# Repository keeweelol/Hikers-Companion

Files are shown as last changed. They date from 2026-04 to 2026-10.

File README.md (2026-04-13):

# Hiker’s Companion

## Overview
Hiker’s Companion is a portable hiking safety device designed for use in areas with little or no cellular coverage. It combines GPS tracking with LoRa communication to allow users to send location data and emergency SOS signals to nearby devices or gateways.

The goal is to provide a **low-cost (<$100), reliable, and energy-efficient** safety solution for recreational hikers.

---

## Features
- 📍 GPS location tracking (≈10 m accuracy)
- 🚨 SOS emergency signaling
- 📡 Long-range LoRa communication (no cellular needed)
- 🔋 24-hour battery life target
- 📱 Bluetooth setup via mobile device
- 🖥️ LCD status display
- 🧭 Real-time location updates for responders

---

## System Architecture

### Main Components
- **ESP32 Microcontroller**
  - Controls system logic and communication
- **GPS Module**
  - Provides real-time coordinates
- **LoRa Module (SX1262)**
  - Handles long-range wireless transmission
- **LCD Display**
  - Shows device status (sending, delivered, etc.)
- **Power System**
  - 3.7V battery → 3.3V regulated supply

---

## How It Works
1. User powers on the device  
2. GPS continuously collects location data  
3. System checks for button input  
4. When pressed:
   - SOS message + GPS data is transmitted via LoRa  
5. Gateway forwards message to emergency contacts  
6. Signal repeats for tracking movement  

---

## Design Constraints
- Cost: **< $100**
- Battery life: **≥ 24 hours**
- Range: **~1 km off-trail communication**
- Temperature: **-18°C to 38°C**
- Durability:
  - Drop resistant (1.5 m)
  - IP55 (dust + water resistant)

---

## Communication Choice
LoRa was selected over alternatives like NB-IoT, Satellite (Iridium), and Mioty due to:

- ✅ Low power consumption  
- ✅ Long range  
- ✅ Low cost  
- ❌ Requires mesh/gateway infrastructure  

---

## Power Analysis
- Estimated average current: **~46.93 mA**
- Daily consumption: **~1.126 Ah**
- Battery capacity: **3 Ah**

➡️ Device can comfortably last **24+ hours** on a single charge.

---

## Current Progress
- ✅ System design finalized  
- ✅ Component selection complete (ESP32-based boards)  
- ✅ Communication method chosen (LoRa)  
- ✅ Initial power calculations completed  

---

## Next Steps
- 🔧 Prototype development (Spring 2026)
- 🔌 Hardware integration and testing
- 🔋 Real-world power validation
- 🧱 Final enclosure design
- 🚀 Full system validation (Fall 2026)

---

## Team
- Ky’Juan Branch  
- Zavier Lowe  
- Kenneth Patrick  
- Taylor Snow  

North Carolina A&T State University  
ECEN 478 – Senior Design Project I  

---

## Summary
Hiker’s Companion aims to improve safety in remote hiking environments by providing a reliable, low-cost emergency communication system that works where traditional networks fail.

---

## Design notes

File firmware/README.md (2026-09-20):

# Hiker's Companion Firmware

Custom PlatformIO/Arduino firmware for the LILYGO T-Beam Supreme
(ESP32-S3 + SX1262 LoRa + AXP2101 PMU + GNSS).

This is separate from `../Lora Source/`, which is LilyGO's own vendored
example repo — kept only as pinout/API reference, not built directly.

Also separate: `../heltec-rx-test/`, a throwaway RX bench rig on a Heltec
WiFi LoRa 32 V3 used to confirm this board's LoRa TX is actually reaching a
second radio — decrypted payload + RSSI/SNR go to both serial and the
Heltec's onboard SSD1306 OLED, which wakes for 5s on each received signal
and sleeps otherwise. It also replies with an `ACK,<id>` for every valid
packet it decrypts, which is what makes the T-Beam's "Delivered" status
real (see FW-06 below). Not part of the product firmware.

## Test hardware on hand

2x LILYGO T-Beam Supreme, 2x Heltec WiFi LoRa 32 V3. Enough to test beyond a
single sender/receiver pair once we get there — e.g. two T-Beam senders into
one gateway, or a relay hop — not just the current one-to-one link test.

## Status: Milestone 1 — GPS + LoRa send loop, with SOS button and status display

Reads GPS fixes and transmits location over LoRa on a timer. The onboard
BOOT button (GPIO0) toggles a standing SOS beacon: pressing it sends an
immediate "SOS"-flagged packet and switches every subsequent periodic send
to "SOS" too (instead of the routine "OK") until pressed again to cancel —
see `sendLocationPacket()` / `buttonPressed()` in `src/main.cpp`.

An SH1106 OLED (I2C, pins 17/18) shows live status via `showStatus()`:
message type on top, "Sending" / "Delivered" / "No ACK" / "Send failed"
below. "Delivered" is now a real ACK, not an assumption: each packet carries
a small message id (`<type>,<id>,<location>`), and after transmitting, the
T-Beam listens for a matching `ACK,<id>` for up to the ACK's own airtime at
the current spreading factor plus `ACK_TURNAROUND_MARGIN_MS` (computed in
`waitForAck()`, so the window grows automatically from SF7 to SF12)
reply from the Heltec RX rig (`waitForAck()`/`sendAck()`). A timeout with no
reply shows "No ACK" — distinct from "Send failed," which means the radio
call itself errored, not that nobody answered.

The panel stays off between transmissions to save power — it wakes for a
send and holds for `DISPLAY_HOLD_MS` (5s) after the result, then sleeps
again (`displayWake()`/`displaySleep()`).

## Power

Between sends, the LoRa and GPS PMU rails (ALDO3/ALDO4) are cut and the
ESP32 goes into light sleep, instead of both rails and the CPU staying fully
awake for the whole `SEND_INTERVAL_MS` interval — this duty cycle is what
the report's 46.93 mA average current draw is based on. Each cycle in
`loop()`:

1. Check for a pending SOS press (`buttonPressed()`/`handleButtonPress()`).
2. Power the GPS/LoRa rails back on and acquire a fix (`acquireGpsFix()`,
   bounded by `GPS_ACQUIRE_BUDGET_MS` for a routine poll or the much shorter
   `GPS_ACQUIRE_QUICK_MS` for an SOS press — a fresh fix isn't worth making
   an emergency send wait).
3. Send (`sendLocationPacket()`).
4. Gate the rails back off (`gpsRailDown()`/`radioRailDown()`) and light-sleep
   for whatever's left of the ~60s interval (`lightSleepMs()`).

The SX1262 and the GPS module both lose all internal state when their rail
is cut, so `gpsRailUp()`/`radioRailUp()` do a full re-init (`initGPS()`/
`initRadio()`), not just a PMU output toggle. The sleep also arms a GPIO
wakeup on the SOS button (level-triggered, since ESP32-S3 light sleep GPIO
wakeup only supports level triggers) so a press doesn't have to wait out the
rest of a ~60s sleep.

## BLE provisioning (FW-10)

Two ways in:

- **At power-on**: holding BOOT through boot (2s, `PROVISION_HOLD_MS`) skips
  the normal GPS/LoRa loop entirely and boots straight into a standalone
  provisioning mode (`bootButtonHeldForProvisioning()` in `main.cpp`).
- **On the fly, during normal operation**: short-pressing the board's
  physical PWR button (`checkBluetoothButton()`/`bluetoothButtonPressed()`
  in `main.cpp`) drops straight into provisioning mid-loop, without a
  reboot. PWR isn't a GPIO on this board — it's wired into the AXP2101 PMU
  as its "power key," reported via `PMU_IRQ_PIN` going low — so it's a
  physically separate button from BOOT/`BUTTON_PIN` (SOS) on purpose: a
  contact-editing press can never be mistaken for, or interfere with, the
  emergency button. **Ignored outright whenever the SOS beacon is active**
  (`sosActive`) rather than queued — entering provisioning can block the
  loop for minutes, and an active SOS beacon has to keep beaconing every
  cycle, not go quiet while someone edits contacts. When SOS isn't active,
  a PWR press is checked at the top of `loop()`, inside `acquireGpsFix()`'s
  polling loop, and as a light-sleep wakeup source, so it can interrupt a
  routine "OK" cycle at any point except the ~2s send/ACK-wait window
  itself.

Either way, `runProvisioningMode()` never returns — normal operation never
runs BLE, so it doesn't touch the sleep/power budget the Power section
above depends on.

In provisioning mode the device advertises as `HikerComp-XXXX` (last 4 hex
digits of its MAC, so multiple units on the bench are distinguishable)
implementing the Nordic UART Service (NUS) — the de facto standard a
terminal-style BLE app (Serial Bluetooth Terminal, nRF Connect's UART
preset, Adafruit Bluefruit Connect, etc.) auto-detects and treats as a
plain serial link, so provisioning is "type a command, see a reply" rather
than hand-browsing a raw GATT table. No dedicated companion app exists yet
(see FW-11).

The OLED reflects connection state throughout — "Bluetooth / No Device"
while advertising, flipping to "Bluetooth / Connected" as soon as a phone
connects (polled from `clientConnected` in `runProvisioningMode()`'s loop
rather than drawn from inside the NimBLE connect/disconnect callbacks
themselves, so every display write stays on one task). Unlike normal
operation, the display is never put to sleep in this mode — it stays lit
for the whole session, since provisioning is a short, deliberate, plugged-in
bench activity rather than something to optimize for battery life.

One command per line on the RX characteristic, one text reply per line back
over TX (`sendLine()`/`RxCallbacks::onWrite()` in `src/ble_provisioning.cpp`):

- `<slot 0-1>|<name>|<phone>` — store one of up to 2 emergency contacts.
  Replies `OK: stored slot <n>`.
- `LIST` — replies with all slots as `<slot>:<name>:<phone>` lines,
  confirming what's actually stored.
- `CLEAR` — wipes all slots.
- `DONE` — ends the session immediately instead of waiting on a disconnect.
- Anything else gets an `ERR: ...` reply rather than being silently dropped,
  since a human is typing these by hand.

Contacts are backed by NVS (`Preferences`, namespace `hc_contacts`) so they
survive a reboot; each slot is its own pair of keys so a write to one can't
corrupt another.

A session also ends on a phone disconnect (one provisioning session per
boot-hold — walking away doesn't leave the device re-advertising), on a
second BOOT press, or after `PROVISION_IDLE_TIMEOUT_MS` (3 min) if no phone
ever connects. Either way `runProvisioningMode()` finishes with
`esp_restart()` back into normal firmware — there's no in-place return path.

**Not implemented:** pairing is unauthenticated (BLE "Just Works", no
passkey/bonding) — same simple-for-now tradeoff as the LoRa PSK being baked
into firmware, acceptable for bench hardware the team controls but not
before this leaves the bench.

### Contacts over LoRa

The stored contacts go out over LoRa on **every** SOS send, not just the
first one. While `sosActive` is set, `sendLocationPacket()` appends
`,<buildContactsForSos()>` — a compact `name:phone;name:phone;...` summary,
empty slots skipped — to each packet of the standing beacon.

Repeating the list on every beacon costs airtime on data that doesn't change
mid-emergency, but that redundancy is the point: LoRa packets get lost, and a
responder who only catches one packet out of a standing beacon still learns
who to notify. With a one-shot, losing that single packet meant losing the
contacts for the entire emergency. If the
combined location+contacts string would overflow the crypto buffer
(`kMaxPlaintextLen`, now 160 bytes — raised from the location-only packet's
64 specifically to fit this), the contacts are dropped for that send and
the location goes out alone instead — the location must never fail to send
just because someone's stored contact names ran long.

Raising `kMaxPlaintextLen` also raises the ciphertext size on the air
(`+ HC_GCM_NONCE_LEN + HC_GCM_TAG_LEN` = up to 188 bytes now, versus 92
before), which is why `heltec-rx-test/src/main.cpp`'s own receive buffer
(`kMaxCipherLen`) had to move from 128 to 192 alongside it — a packet larger
than the receiver's buffer gets silently dropped as "bad packet length"
rather than received. The two constants have to be kept in sync by hand;
there's no shared source of truth between the two PlatformIO projects for
this.

## Build / flash

```sh
python3 -m venv .venv
.venv/bin/pip install platformio
.venv/bin/pio run                 # compile
.venv/bin/pio run -t upload       # flash (board connected via USB-C)
.venv/bin/pio device monitor      # serial log at 115200 baud
```

## Config knobs (top of `src/main.cpp`)

- `LORA_FREQUENCY_MHZ` — 915 MHz (US915 ISM band)
- `LORA_SPREADING_FACTOR` — currently SF10, placeholder until range testing
  picks a value from the report's SF7-SF12 tradeoff space
- `SEND_INTERVAL_MS` — currently 60s, matches the flow chart's "poll every
  minute" behavior

## Security

LoRa payloads are encrypted with AES-128-GCM before transmission — GCM gives
both confidentiality and an authentication tag, so a receiver can tell a
tampered/spoofed packet from a real one, not just decrypt it. This matters
once the main/gateway node forwards messages to emergency services: a forged
SOS or forged "I'm fine" location needs to fail the auth check, not be
trusted just because it decrypts.

The 128-bit key is pre-shared and baked directly into firmware — see
`../shared/psk.h`, included by every project via the `-I ../shared` build
flag so sender and receiver firmware can't drift out of sync. This is
deliberately simple for now, since every node is firmware we build and flash
ourselves; revisit if the project ever needs per-device keys or field
provisioning. Crypto helpers (`hcEncrypt`/`hcDecrypt`) live in
`../shared/hc_crypto.h`.

Wire format on the air: `[12-byte nonce][ciphertext][16-byte tag]`.

## Known gotcha

The T-Beam Supreme's AXP2101 PMU gates power to the LoRa, GPS, and display
modules behind the ALDO3, ALDO4, and ALDO1 rails respectively, all off at
boot. `initPower()` in `main.cpp` turns them on — skip any of these and
that module silently never powers up even with correct wiring. ALDO1 is
the one that actually bit us: per LilyGO's own hardware doc it's shared
across the display, the BME280 sensor, and the magnetometer, and our
`initPower()` originally only ever enabled ALDO3/ALDO4, never ALDO1. One of
our two units had a screen that stayed completely black through boot even
though `display.begin()` reported success and the rest of the device ran
fine — flashing Meshtastic on the same unit proved the OLED hardware itself
was fine, which pointed straight at power rather than the display or its
I2C address. The SH1106 controller could apparently still ACK basic I2C
reads/writes with no ALDO1 power at all (enough for `begin()` to report
success), but never had the power to actually drive the panel. `initPower()`
now enables ALDO1 alongside ALDO3/ALDO4, and — because `runProvisioningMode()`
can be entered via the boot-hold path *before* `initPower()` would otherwise
run (it's `[[noreturn]]`, so the rest of `setup()` never executes in that
boot) — `initPower()` was moved ahead of the `bootButtonHeldForProvisioning()`
check in `setup()`, so both entry paths into provisioning always have a
powered display too.

LilyGO also ships this board with two magnetometer sub-variants (QMC6310U
vs QMC6310N) that, per their docs, put the SH1106 OLED at different I2C
addresses — 0x3C or 0x3D respectively. We haven't actually confirmed this
varies between our own two units (the ALDO1 gap above was the real bug on
the unit we tested), but `initDisplay()`/`runProvisioningMode()` both probe
`0x3C` then `0x3D` rather than assuming one anyway (`DISPLAY_I2C_ADDR_CANDIDATES`),
since it's cheap insurance against a documented hardware variance for this
exact board. Display failure is non-fatal everywhere, including at boot —
`initDisplay()` used to `haltWithError()` if the display didn't respond,
which took the *entire* device down (no GPS, no LoRa, no SOS) over what
looked like just a dead screen. It now logs and continues with
`displayAvailable = false`; every `display*` function in `main.cpp` checks
that flag and no-ops rather than touching hardware that was never found.

The board's PWR button isn't a GPIO at all — it's wired into the AXP2101 as
its power key, reported by pulling `PMU_IRQ_PIN` low. `initPower()`
disables every other AXP2101 IRQ source and enables only
`XPOWERS_AXP2101_PKEY_SHORT_IRQ`, so `bluetoothButtonPressed()` can treat
"pin is low" as "PWR was pressed" without decoding the status register —
if another IRQ source ever gets enabled here for something else, that
assumption breaks and the pin could go low for an unrelated reason.
`PMU->clearIrqStatus()` must be called after reading a press or the pin
stays stuck low and every subsequent check reads as a phantom press.

The display's I2C bus (`Wire`) needs a full re-init (`reinitDisplay()`)
before every cycle's status draw, not just an ON command — unlike the
GPS/LoRa rails, the display's own power is never cut, but the ESP32's I2C
peripheral state doesn't reliably survive `esp_light_sleep_start()` either
way. Without this the screen goes dark after the first sleep and stays dark
even though GPS/LoRa/SOS keep working fine, since those get a full re-init
already (their rails actually are cut). `reinitDisplay()` is non-fatal on
failure, unlike `initDisplay()` at boot — a flaky display shouldn't halt the
whole device the way a missing one at boot should.

Confirmed, not just suspected: native USB CDC serial (`ARDUINO_USB_CDC_ON_BOOT=1`)
is not reliable across sleep on this chip — RadioLib itself emits `"Use of
USB CDC for debug output is not recommended (might stop on first sleep).
Use hardware UART instead."` at compile time whenever that flag is set,
sleep loop or not. If `pio device monitor` (or opening the COM port
directly) stops working partway through testing, replug the USB-C cable to
force Windows to re-enumerate it — don't rely on one continuous serial
session surviving a full sleep cycle. A hardware UART-to-USB adapter would
sidestep this if continuous logging becomes necessary.

RadioLib's `setDio1Action()` (used for interrupt-driven receive, see
`heltec-rx-test/`) fires on any rising edge on that pin — it doesn't know
whether the chip currently means RX-done or TX-done by it. Any
`radio.transmit()` call made while that interrupt is attached (e.g. sending
an ACK from within the RX loop) will trip the same callback via its own
TX-done pulse, so the flag it sets must be explicitly cleared after your own
transmits or the next loop iteration will treat it as a real received
packet — see the comment on `sendAck()` in `heltec-rx-test/src/main.cpp`.

## Next milestones (not yet implemented)

- Power measurement against the report's theoretical current-draw numbers
  now that the sleep/rail-gating duty cycle (see Power, above) is in place
  to measure

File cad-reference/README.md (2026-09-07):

# CAD reference

3D/2D reference models for the LILYGO T-Beam Supreme, extracted from the
vendored `../Lora Source/dimensions/` archives (LilyGO's own repo, kept
elsewhere in this project only as reference — not built or modified there).
Pulled out here because they were buried in compressed archives inside a
directory that's otherwise just firmware examples, and are directly useful
for the mechanical backlog items (MECH-01/02/04): enclosure material and
gasket selection, CAD'ing a manufacturable build, and finalizing carabiner
mounts and cutouts.

## T-Beam-Supreme/

- **T-Beam-Supreme-Board.stp** — Full 3D STEP model of the board itself.
  Import this for real component clearances (ports, connectors, antenna,
  battery connector placement) rather than guessing from photos.
- **T-Beam-Supreme-Dimensions.dxf** — 2D board outline and mounting-hole
  dimension drawing.
- **T-Beam-Supreme-Bracket.stp** — A separate mounting bracket LilyGO
  provides for this board.
- **shell/backshell.stl, shell/topside.stl, shell/brackets.stl** — LilyGO's
  own existing enclosure shell design for this board (back half, top half,
  and mounting brackets). A real starting point for MECH-02 rather than a
  from-scratch design — still needs our own button/port cutouts, wall
  thickness/gasket work for the IP55 target (MECH-01), and carabiner mount
  changes (MECH-04), since this shell wasn't designed for those.

## Source

Pulled from `Lora Source/dimensions/` on 2026-09-07:
`T-Beam-Supreme.zip`, `T-Beam-Supreme-Shell.7z`, `T-Beam-Supreme-Bracket.zip`,
`T-BEAM-SUPREME-V3.0.DXF`. See that folder's own README.md for the full
LilyGO dimension-file index across all their boards, if a different board
revision's files are ever needed.

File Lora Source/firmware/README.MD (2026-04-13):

## How to Flash ?

### Before burning firmware, please put the board into download mode and follow the steps below

 1. Connect the board via the USB cable
 2. Press and hold the **BOOT** button , While still pressing the **BOOT** button (If there is no **BOOT** button, you need to use wires to connect **GND** and **IO0** together.)
 3. Press **RST** button
 4. Release the **RST** button
 5. Release the **BOOT** button (If there is no **BOOT** button, disconnect IO0 from GND.)
 6. Upload sketch
 7. Press the **RST** button to exit download mode

### Use ESP Download Tool

- Download [Flash_download_tool](https://www.espressif.com.cn/sites/default/files/tools/flash_download_tool_3.9.6_0.zip)

> \[!IMPORTANT]
> The following GIF shows the writing of ESP32S3. If you are using ESP32, please select ESP32 instead of ESP32S3.

web_flasher

* **Note that after writing is completed, you need to press RST to reset**.

### Use Web Flasher

- [ESP Web Flasher Online](https://espressif.github.io/esptool-js/)

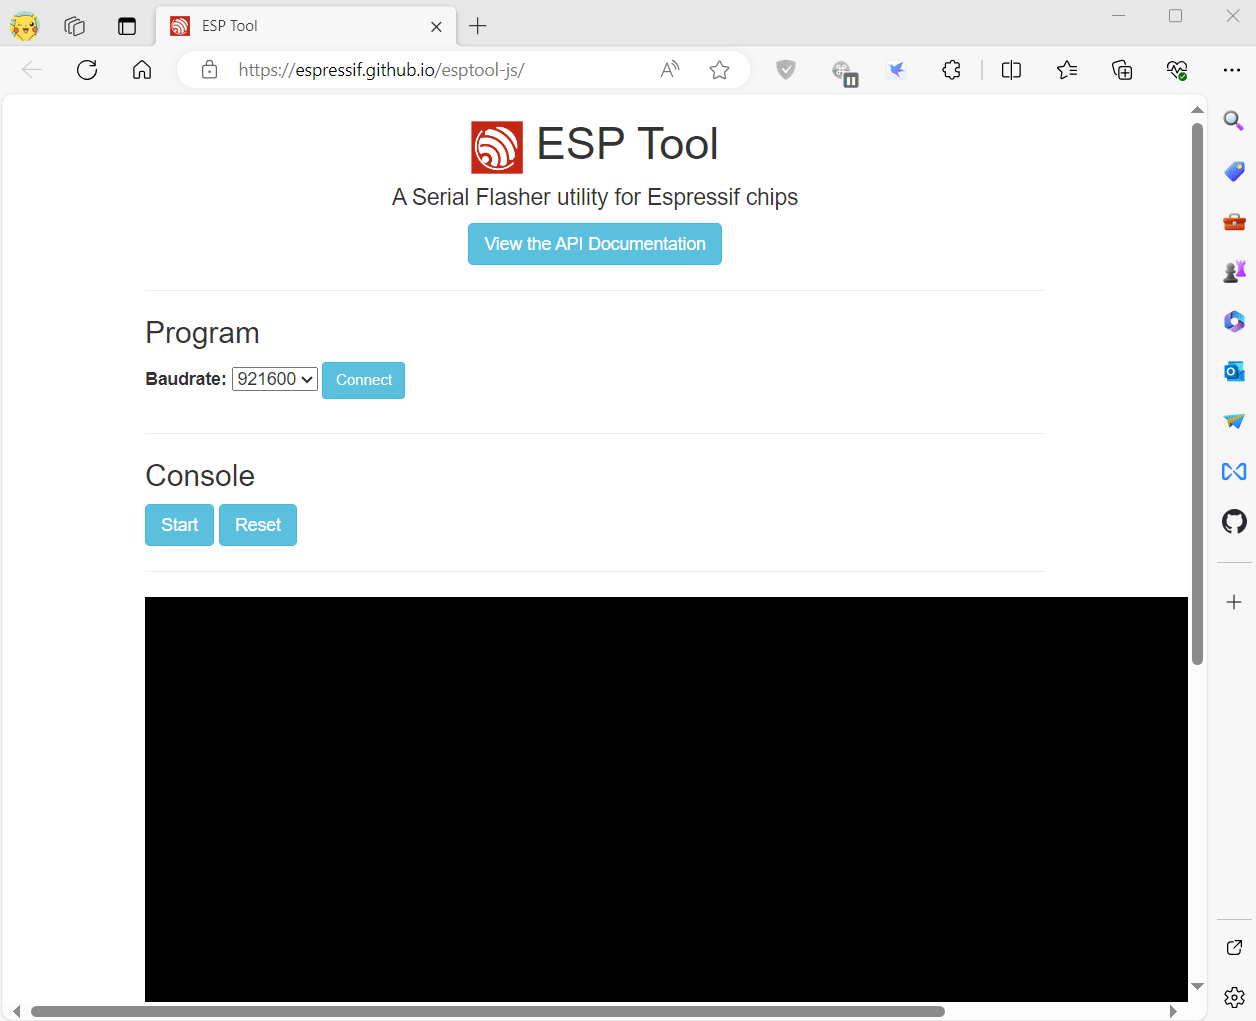
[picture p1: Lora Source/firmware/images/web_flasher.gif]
web_flasher


* **Note that after writing is completed, you need to press RST to reset**.

### Use command line

If system asks about install Developer Tools, do it.

```
python3 -m pip install --upgrade pip
python3 -m pip install esptool
```

In order to launch esptool.py, exec directly with this:

```
python3 -m esptool
```

For ESP32 use the following command to write

```
esptool --chip esp32  --baud 921600 --before default_reset --after hard_reset write_flash -z --flash_mode dio --flash_freq 80m 0x0 firmware.bin

```

For ESP32-S3 use the following command to write

```
esptool --chip esp32s3  --baud 921600 --before default_reset --after hard_reset write_flash -z --flash_mode dio --flash_freq 80m 0x0 firmware.bin

```

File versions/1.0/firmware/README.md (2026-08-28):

# Hiker's Companion Firmware

Custom PlatformIO/Arduino firmware for the LILYGO T-Beam Supreme
(ESP32-S3 + SX1262 LoRa + AXP2101 PMU + GNSS).

This is separate from `../Lora Source/`, which is LilyGO's own vendored
example repo — kept only as pinout/API reference, not built directly.

Also separate: `../heltec-rx-test/`, a throwaway RX bench rig on a Heltec
WiFi LoRa 32 V3 used to confirm this board's LoRa TX is actually reaching a
second radio (prints received payload + RSSI/SNR to serial). Not part of the
product firmware.

## Test hardware on hand

2x LILYGO T-Beam Supreme, 2x Heltec WiFi LoRa 32 V3. Enough to test beyond a
single sender/receiver pair once we get there — e.g. two T-Beam senders into
one gateway, or a relay hop — not just the current one-to-one link test.

## Status: Milestone 1 — GPS + LoRa send loop, with SOS button

Reads GPS fixes and transmits location over LoRa on a timer. The onboard
BOOT button (GPIO0) toggles a standing SOS beacon: pressing it sends an
immediate "SOS"-flagged packet and switches every subsequent periodic send
to "SOS" too (instead of the routine "OK") until pressed again to cancel —
see `sendLocationPacket()` / `pollButton()` in `src/main.cpp`. No display
yet, and no ACK, so "sent ok" on serial is not the same as "a human saw
this."

## Build / flash

```sh
python3 -m venv .venv
.venv/bin/pip install platformio
.venv/bin/pio run                 # compile
.venv/bin/pio run -t upload       # flash (board connected via USB-C)
.venv/bin/pio device monitor      # serial log at 115200 baud
```

## Config knobs (top of `src/main.cpp`)

- `LORA_FREQUENCY_MHZ` — 915 MHz (US915 ISM band)
- `LORA_SPREADING_FACTOR` — currently SF10, placeholder until range testing
  picks a value from the report's SF7-SF12 tradeoff space
- `SEND_INTERVAL_MS` — currently 60s, matches the flow chart's "poll every
  minute" behavior

## Security

LoRa payloads are encrypted with AES-128-GCM before transmission — GCM gives
both confidentiality and an authentication tag, so a receiver can tell a
tampered/spoofed packet from a real one, not just decrypt it. This matters
once the main/gateway node forwards messages to emergency services: a forged
SOS or forged "I'm fine" location needs to fail the auth check, not be
trusted just because it decrypts.

The 128-bit key is pre-shared and baked directly into firmware — see
`../shared/psk.h`, included by every project via the `-I ../shared` build
flag so sender and receiver firmware can't drift out of sync. This is
deliberately simple for now, since every node is firmware we build and flash
ourselves; revisit if the project ever needs per-device keys or field
provisioning. Crypto helpers (`hcEncrypt`/`hcDecrypt`) live in
`../shared/hc_crypto.h`.

Wire format on the air: `[12-byte nonce][ciphertext][16-byte tag]`.

## Known gotcha

The T-Beam Supreme's AXP2101 PMU gates power to the LoRa and GPS modules
behind the ALDO3/ALDO4 rails, which are off at boot. `initPower()` in
`main.cpp` turns them on — skip that step and the radio/GPS silently never
power up even with correct wiring.

## Next milestones (not yet implemented)

- LCD status display ("Sending" / "Delivered")
- LoRa RX side / ACK handling so "Delivered" status is real, not assumed
- Power measurement against the report's theoretical current-draw numbers

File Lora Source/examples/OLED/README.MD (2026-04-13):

  

## TBEAM-S3-CORE

- `TBEAM-S3-CORE` uses `SH1106` by default. Please do not run the `SSD1306` example on `TBEAM-S3-CORE`
- For more examples, please refer to U8g2/examples

## TBEAM-V1.x

- `TBEAM-V1.x` The SSD1306 driver screen is used by default. If the SH1106 screen is used, please comment cancellation
    ```
    // #define DISPLAY_ MODEL               U8G2_ SH1106_ 128X64_ NONAME_ F_ HW_ I2C
    ```

## Other model uses SSD1306 display model

- [esp8266-oled-ssd1306](https://github.com/ThingPulse/esp8266-oled-ssd1306)
- For more examples, please refer to esp8266-oled-ssd1306/examples

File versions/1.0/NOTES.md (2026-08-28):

# Version 1.0

Baseline snapshot: everything working and hardware-verified as of this session.

- GPS + LoRa send loop (Milestone 1), hardware-verified on the T-Beam Supreme.
- AES-128-GCM encryption on all LoRa payloads (pre-shared key in `shared/psk.h`).
- SOS button (GPIO0 / BOOT button): press toggles a standing SOS beacon —
  every send goes out flagged "SOS" instead of "OK" until pressed again to
  cancel.
- `heltec-rx-test/`: RX bench rig on a Heltec WiFi LoRa 32 V3, confirmed
  receiving and decrypting real packets from the T-Beam with RSSI/SNR logged.

Not yet implemented: LCD status display, LoRa RX/ACK on the gateway side,
sleep/wake power management, final GPS polling interval.

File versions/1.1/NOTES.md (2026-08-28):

# Version 1.1

Built on 1.0 — adds status displays to both boards (FW-05).

- T-Beam: SH1106 OLED (I2C, pins 17/18) shows "Sending" / "Delivered" /
  "Send failed" per send, plus a "Ready" boot screen. See `showStatus()` in
  `firmware/src/main.cpp`. No ACK yet, so "Delivered" means the radio call
  returned success, not that anyone received it (FW-06).
- Heltec RX rig: onboard SSD1306 OLED shows the received message type
  (OK/SOS, large) with RSSI/SNR below, plus distinct banners for
  decrypt/auth failure, CRC mismatch, and radio errors. Needed enabling the
  Vext power rail (GPIO36, active-low) before the display responds.
- Both displays power down between events rather than staying lit: the
  T-Beam's wakes for a send and holds 5s past the result before sleeping;
  the Heltec's wakes for 5s on any received signal. Non-blocking timer
  (`displayWake()`/`displaySleep()`/`scheduleDisplayOff()`, checked once per
  `loop()`) — no `delay()`, since that would stall GPS/button/radio polling.

Everything from 1.0's NOTES.md still applies (GPS + LoRa send loop, AES-128-GCM
encryption, SOS button toggle).

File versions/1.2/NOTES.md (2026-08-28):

# Version 1.2

Built on 1.1 — adds a real delivery ACK (FW-06).

- Outgoing packets now carry a message id: `<type>,<id>,<location>` instead
  of just `<type>,<location>`.
- Heltec RX rig replies with an encrypted `ACK,<id>` for every packet it
  successfully decrypts (`sendAck()`), sent before its own display update to
  keep latency low.
- T-Beam listens for up to `ACK_TIMEOUT_MS` (2s) after transmitting
  (`waitForAck()`, using RadioLib's blocking `receive()` with a timeout) and
  now shows three distinct outcomes instead of two:
  - "Delivered" — a matching ACK came back (a real confirmation now, not an
    assumption)
  - "No ACK" — transmit succeeded but nothing came back in time
  - "Send failed" — the radio call itself errored

Trade-off: `waitForAck()` blocks `loop()` (GPS/button polling included) for
up to 2s after every send. Acceptable for now since it's once per send, not
continuous — revisit if button responsiveness during that window becomes a
problem.

**Bug fix folded into this snapshot**: `sendAck()`'s own `radio.transmit()`
call was tripping the Heltec's `onPacketReceived()` interrupt via its
TX-done pulse on the same DIO1 pin `setDio1Action()` watches for RX-done —
RadioLib's callback doesn't distinguish the two. The next `loop()` iteration
then read a corrupted mix of the ACK's own bytes and leftover tail from the
real packet (SX1262's TX/RX buffers share memory), which reliably failed
the GCM auth check and printed a spurious "decrypt/auth failed" right after
every successful exchange. Fixed by clearing `packetReceived = false`
immediately after `sendAck()`'s transmit call. See the "Known gotcha"
section of `firmware/README.md` for the full mechanism.

Everything from 1.1's NOTES.md still applies (status displays with
sleep/wake power saving) and 1.0's (GPS + LoRa send loop, AES-128-GCM
encryption — now covering the ACK too — and the SOS button toggle).

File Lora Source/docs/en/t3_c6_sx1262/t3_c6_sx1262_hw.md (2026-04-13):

<div align="center" markdown="1">
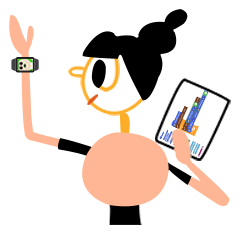
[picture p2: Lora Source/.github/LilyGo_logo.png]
LilyGo logo
  
</div>

<h1 align = "center">🌟LilyGo T3-C6🌟</h1>

## Overview

* This page introduces the hardware parameters related to `LilyGo T3-C6`

### Notes on use

1. Please be sure to connect the antenna before transmitting, otherwise it is easy to damage the RF module

### Product

| Product | SOC | Flash |
| --- | --- | --- |
| [T-Lora C6][1] | ESP32-C6-MINI-1U | 4MB(Quad-SPI) |

[1]: https://www.lilygo.cc/products/t-lora-c6 "T-Lora C6"

### PlatformIO Quick Start

1. Install [Visual Studio Code](https://code.visualstudio.com/) and [Python](https://www.python.org/)
2. Search for the `PlatformIO` plugin in the `Visual Studio Code` extension and install it.
3. After the installation is complete, you need to restart `Visual Studio Code`
4. After restarting `Visual Studio Code`, select `File` in the upper left corner of `Visual Studio Code` -> `Open Folder` -> select the `LilyGo-LoRa-Series` directory
5. Wait for the installation of third-party dependent libraries to complete
6. Click on the `platformio.ini` file, and in the `platformio` column
7. Select the board name you want to use in `default_envs` and uncomment it.
8. Uncomment one of the lines `src_dir = xxxx` to make sure only one line works , Please note the example comments, indicating what works and what does not.
9.  Click the (✔) symbol in the lower left corner to compile
10. Connect the board to the computer USB-C , Micro-USB is used for module firmware upgrade
11. Click (→) to upload firmware
12. Click (plug symbol) to monitor serial output
13. If it cannot be written, or the USB device keeps flashing, please check the **FAQ** below

### Arduino IDE quick start

1. Install [Arduino IDE](https://www.arduino.cc/en/software)
2. Install [Arduino ESP32](https://docs.espressif.com/projects/arduino-esp32/en/latest/)
3. Copy all folders in the `lib` directory to the `Sketchbook location` directory. How to find the location of your own libraries, [please see here](https://support.arduino.cc/hc/en-us/articles/4415103213714-Find-sketches-libraries-board-cores-and-other-files-on-your-computer)
    * Windows: `C:\Users\{username}\Documents\Arduino`
    * macOS: `/Users/{username}/Documents/Arduino`
    * Linux: `/home/{username}/Arduino`
4. Open the corresponding example
    * Open the downloaded `LilyGo-LoRa-Series`
    * Open `examples`
    * Select the sample file and open the file ending with `ino`
5. On Arduino Select the corresponding board in the IDE tool project and click on the corresponding option in the list below to select

     | T3-C6                                | Value                                                   |
     | ------------------------------------ | ------------------------------------------------------- |
     | Board                                | **ESP32C6 Dev Module**                                  |
     | Port                                 | Your port                                               |
     | USB CDC On Boot                      | Enable                                                  |
     | CPU Frequency                        | 160MHZ(WiFi)                                            |
     | Core Debug Level                     | None                                                    |
     | USB DFU On Boot                      | Disable                                                 |
     | Erase All Flash Before Sketch Upload | Disable                                                 |
     | Flash Mode                           | DIO                                                     |
     | Flash Size                           | **4MB(32Mb)**                                           |
     | Arduino Runs On                      | Core1                                                   |
     | USB Firmware MSC On Boot             | Disable                                                 |
     | Partition Scheme                     | **Default 4M Flash with spiffs(1.2M APP/1.5MB SPIFFS)** |
     | Upload Speed                         | 921600                                                  |
     | Programmer                           | **Esptool**                                             |

6. Please uncomment the `utilities.h` file of each sketch according to your board model ,e.g `T3_C6` , otherwise the compilation will report an error.
7. Upload sketch

### 📍 Pins Map

| Name | GPIO NUM | Free |
| --- | --- | ---- |
| LoRa(**SX1276**) SCK | 6 | ❌ |
| LoRa(**SX1276**) MISO  | 1 | ❌ |
| LoRa(**SX1276**) MOSI  | 0 | ❌ |
| LoRa(**SX1276**) RESET | 21 | ❌ |
| LoRa(**SX1276**) DIO0  | 23 | ❌ |
| LoRa(**SX1276**) BUSY  | 22 | ❌ |
| LoRa(**SX1276**) CS | 18 | ❌ |
| On Board LED | 7 | ❌ |

### ⚡ Electrical parameters

| Features | Details |
| --- | --- |
| 🔗USB-C Input Voltage | 5V |

### Button Description

| Channel | Peripherals |
| --- | --- |
| BOOT | Boot mode button, customizable |
| RST | Reset button |

### LED Description

* User LED

1. The LED is connected to ESP32C6 GPIO7, and the LED is turned on or off by writing a high or low level

### RF parameters

| Features | Details |
| --- | --- |
| RF  Module | SX1262 |
| Frequency range | 840～945MHz |
| Transfer rate(LoRa) | 0.018K～37.5Kbps |
| Transfer rate(FSK)  | 1.2K～300Kbps |
| Modulation | FSK, GFSK, MSK, GMSK, LoRa，OOK |

### Resource

* [Schematic](../../../schematic/T3-C6_V1.0.pdf)

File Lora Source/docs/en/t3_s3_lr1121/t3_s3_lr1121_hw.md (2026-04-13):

<div align="center" markdown="1">
  LilyGo logo
</div>

<h1 align = "center">🌟LilyGo T3 S3 LR1121🌟</h1>

## Overview

* This page introduces the hardware parameters related to `LilyGo T3 S3 LR1121`

### Notes on use

1. This version does not have BMS, please use a lithium-ion battery with battery protection function
2. Please be sure to connect the antenna before transmitting, otherwise it is easy to damage the RF module
3. The T3-S3 V1.2 and T3-S3 V1.3 use the same pins; the only difference is the charging circuit.

### Product

| Product | SOC | Flash | PSRAM |
| --- | --- | --- | --- |
| [T3-S3][1] | ESP32-S3FH4R2 | 4MB(Quad-SPI) | 2MB(Quad-SPI) |

[1]: https://www.lilygo.cc/products/t3s3-v1-0?variant=42586879688885 "T3-S3"

## PlatformIO Quick Start

1. Install [Visual Studio Code](https://code.visualstudio.com/) and [Python](https://www.python.org/)
2. Search for the `PlatformIO` plugin in the `Visual Studio Code` extension and install it.
3. After the installation is complete, you need to restart `Visual Studio Code`
4. After restarting `Visual Studio Code`, select `File` in the upper left corner of `Visual Studio Code` -> `Open Folder` -> select the `LilyGo-LoRa-Series` directory
5. Wait for the installation of third-party dependent libraries to complete
6. Click on the `platformio.ini` file, and in the `platformio` column
7. Select the board name you want to use in `default_envs` and uncomment it.
8. Uncomment one of the lines `src_dir = xxxx` to make sure only one line works , Please note the example comments, indicating what works and what does not.
9. Click the (✔) symbol in the lower left corner to compile
10. Connect the board to the computer USB-C , Micro-USB is used for module firmware upgrade
11. Click (→) to upload firmware
12. Click (plug symbol) to monitor serial output
13. If it cannot be written, or the USB device keeps flashing, please check the **FAQ** below

## Arduino IDE quick start

1. Install [Arduino IDE](https://www.arduino.cc/en/software)
2. Install [Arduino ESP32](https://docs.espressif.com/projects/arduino-esp32/en/latest/)
3. Copy all folders in the `lib` directory to the `Sketchbook location` directory. How to find the location of your own libraries, [please see here](https://support.arduino.cc/hc/en-us/articles/4415103213714-Find-sketches-libraries-board-cores-and-other-files-on-your-computer)
    * Windows: `C:\Users\{username}\Documents\Arduino`
    * macOS: `/Users/{username}/Documents/Arduino`
    * Linux: `/home/{username}/Arduino`
4. Open the corresponding example
    * Open the downloaded `LilyGo-LoRa-Series`
    * Open `examples`
    * Select the sample file and open the file ending with `ino`
5. On Arduino Select the corresponding board in the IDE tool project and click on the corresponding option in the list below to select

    | Name                                 | Value                                                |
    | ------------------------------------ | ---------------------------------------------------- |
    | Board                                | **LilyGo T3-S3**                                     |
    | Port                                 | Your port                                            |
    | USB CDC On Boot                      | Enable                                               |
    | CPU Frequency                        | 240MHZ(WiFi)                                         |
    | Core Debug Level                     | None                                                 |
    | USB DFU On Boot                      | Disable                                              |
    | Erase All Flash Before Sketch Upload | Disable                                              |
    | Events Run On                        | Core1                                                |
    | Arduino Runs On                      | Core1                                                |
    | USB Firmware MSC On Boot             | Disable                                              |
    | Partition Scheme                     | **Default 4MB with spiffs (1.2MB APP/1.5MB SPIFFS)** |
    | PSRAM                                | **QSPI PSRAM**                                       |
    | **Board Revision***                  | **Radio-LR1121**                                     |
    | Upload Mode                          | **UART0/Hardware CDC**                               |
    | Upload Speed                         | 921600                                               |
    | USB Mode                             | **CDC and JTAG**                                     |
    | Programmer                           | **Esptool**                                          |

     * **Board revision Select according to actual model**

6. Upload sketch

### 📍 Pins Map

| Name | GPIO NUM | Free |
| --- | --- | ---- |
| (QWIIC) Uart1 TX | 43(External QWIIC Socket) | ✅️ |
| (QWIIC) Uart1 RX | 44(External QWIIC Socket) | ✅️ |
| QWIIC Socket IO10* | 10(External QWIIC Socket) | ✅️ |
| QWIIC Socket IO21* | 21(External QWIIC Socket) | ✅️ |
| SDA | 18 | ❌ |
| SCL | 17 | ❌ |
| OLED(**SSD1306**) SDA  | Share with I2C bus | ❌ |
| OLED(**SSD1306**) SCL  | Share with I2C bus | ❌ |
| SD CS | 13 | ❌ |
| SD MOSI | 11 | ❌ |
| SD MISO | 2 | ❌ |
| SD SCK | 14 | ❌ |
| LoRa(**LR1121**) SCK | 5 | ❌ |
| LoRa(**LR1121**) MISO  | 3 | ❌ |
| LoRa(**LR1121**) MOSI  | 6 | ❌ |
| LoRa(**LR1121**) RESET | 8 | ❌ |
| LoRa(**LR1121**) DIO9  | 36 | ❌ |
| LoRa(**LR1121**) BUSY  | 34 | ❌ |
| LoRa(**LR1121**) CS | 7 | ❌ |
| Button1 (BOOT) | 0 | ❌ |
| Battery ADC | 1 | ❌ |
| On Board LED | 37 | ❌ |

* You can use GPIO10,21 by removing the two resistors in the figure below. Otherwise, the GPIO is connected to DIO8,DIO7 of Radio by default.
* SDA(18) and SCL(17) are not brought out and cannot be accessed. They can only be used as other GPIOs through QWIIC or header pins. During initialization, use explicit initialization `Wire.begin(sda,scl);` Any unused GPIO can be used as SDA and SCL.

| T3 V1.2 | T3 V1.3 |
| --- | --- |
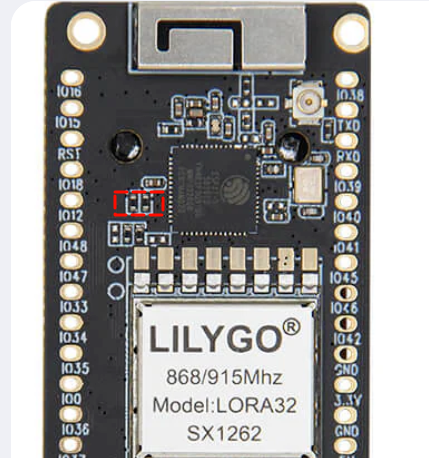
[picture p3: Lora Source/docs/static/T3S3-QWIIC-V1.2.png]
T3-S3-QWIIC
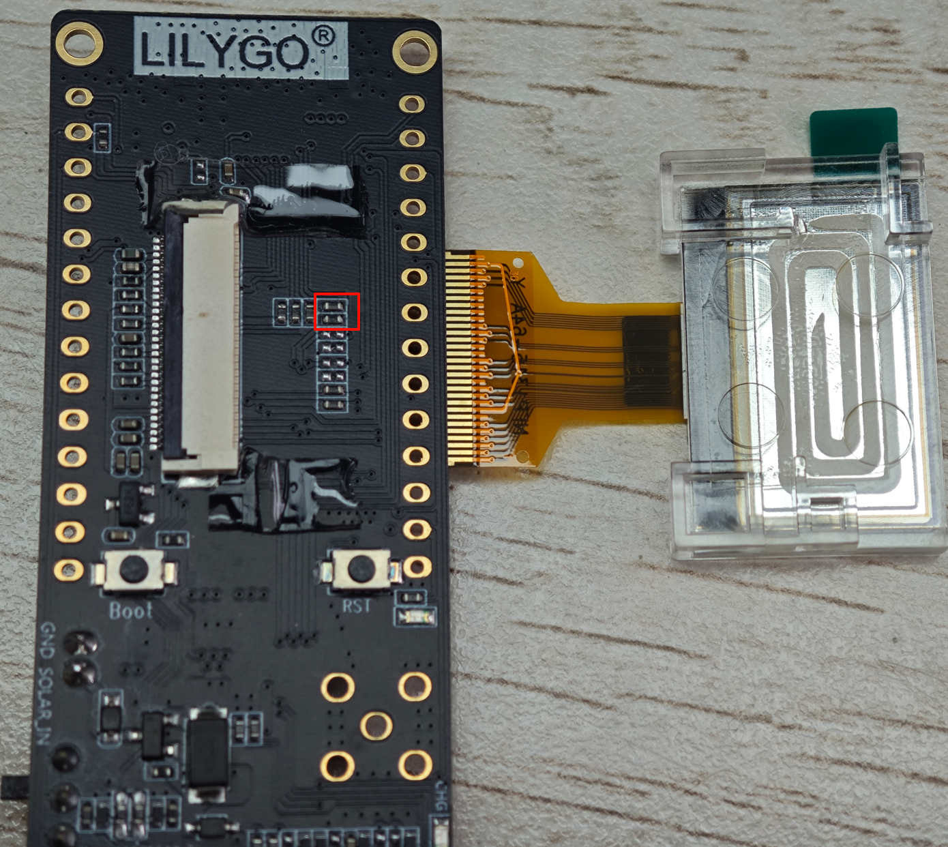
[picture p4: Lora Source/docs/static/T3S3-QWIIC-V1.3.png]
T3-S3-QWIIC
|  |  |

### 🧑🏼‍🔧 I2C Devices Address

| Devices | 7-Bit Address | Share Bus |
| --- | --- | --- |
| OLED Display SSD1306 | 0x3C | ✅️ |

### ⚡ Electrical parameters

| Features | Details  |
| --- | --- |
| 🔗USB-C Input Voltage | 5V |
| 🔗Solar Input Voltage(T3 V1.3 Only) | 4.5~5.6V |
| ⚡Charge Current | 500mA |
| 🔋Battery Voltage | 3.7V |
| 🔋Battery Socket Cables | PH2.0mm  |
| 🔗QWIIC Socket Cables | JST1.0 |

> \[!IMPORTANT]
> T3 V1.3 The maximum solar input voltage can only be 5.6V. If the voltage exceeds this, the Zener diode will discharge and cause the diode to heat up.T3 V1.3 
>

### Button Description

| Channel | Peripherals |
| --- | --- |
| BOOT | Boot mode button, customizable |
| RST | Reset button |

### LED Description

* CHG LED

| LED State | Details |
| --- | --- |
| On | Battery charging |
| Off | Battery Full |
| Blink | Battery not connected |

* User LED

1. The LED is connected to ESP32 GPIO37, and the LED is turned on or off by writing a high or low level

### RF parameters

| Features | Details |
| --- | --- |
| RF  Module | LR1121 |
| Frequency range | 400-520MHz/830-945MHz/2400-2500MHz |
| Transfer rate(LoRa Sub1G) | 0.018 K ～ 62.5 Kbps |
| Transfer rate(FSK Sub1G)  | 0.6 K ～ 300 Kbps |
| Transfer rate(LoRa 2.4G)  | 0.476 K~101.5 Kbps |
| Modulation | LoRa,FSK,LR-HFSS |

* LR1121 Sub-1G When the power setting is lower than 14, the power is abnormal. Please [see here](https://github.com/Xinyuan-LilyGO/LilyGo-LoRa-Series/issues/254#issuecomment-3219719499)

## WiFi-IPEX

* The following figure shows how to switch the onboard WIFI antenna to IPEX

| T3 V1.2 | T3 V1.3 |
| --- | --- |
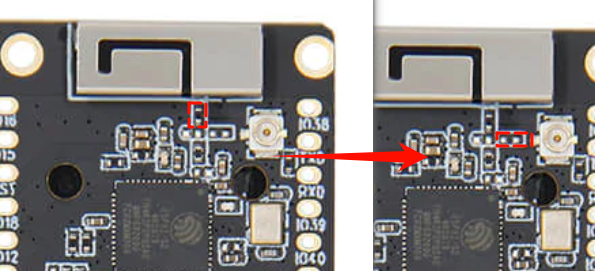
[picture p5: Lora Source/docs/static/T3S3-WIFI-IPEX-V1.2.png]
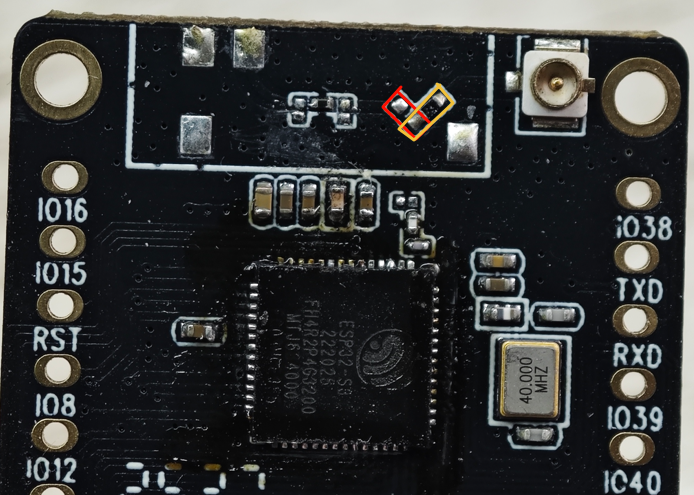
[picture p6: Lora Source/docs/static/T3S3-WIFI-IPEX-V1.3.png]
|  |  |

## LoRa Ant

* For instructions on how to configure LoRa antenna control, please refer to the [example](https://github.com/Xinyuan-LilyGO/LilyGo-LoRa-Series/blob/d04e9c4c66516ad918c7fafbd63b477822066ec8/examples/T3S3Factory/T3S3Factory.ino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)
* LR1121 The 2.4G antenna interface is located on the LoRa module and cannot be changed.
* LoRa 2.4G and Sub1G antennas are independent and cannot be shared.
* The following figure shows how to switch the onboard LoRa-Sub1G SMA antenna to IPEX

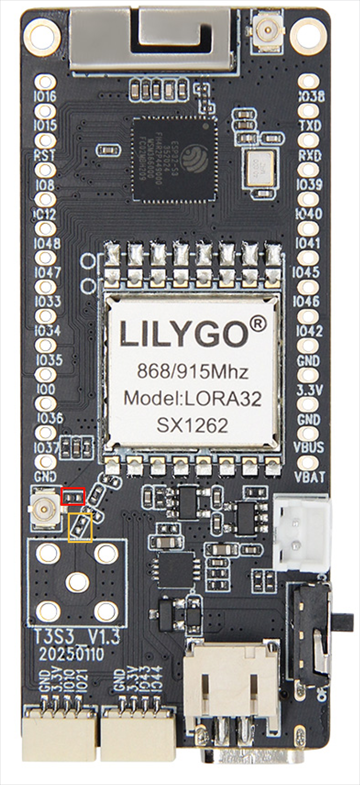
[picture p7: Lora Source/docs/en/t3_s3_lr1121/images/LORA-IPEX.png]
LORA-IPEX


### LR1121 RF Block Diagram

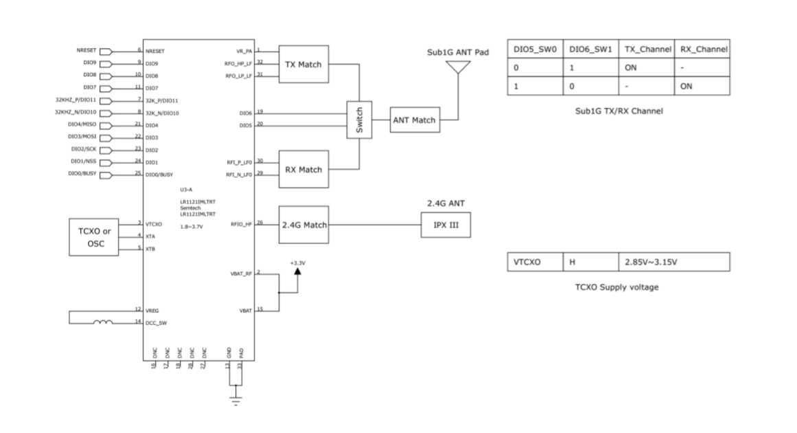
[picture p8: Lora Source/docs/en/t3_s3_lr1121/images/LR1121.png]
RF Block Diagram


#### Resource

* [T3_S3_V1.2 schematic](../../../schematic/T3_S3_V1.2.pdf)
* [T3_S3_V1.3 schematic](../../../schematic/T3_S3_V1.3.pdf)
* [LR1121 datasheet](https://www.semtech.com/products/wireless-rf/lora-connect/lr1121)

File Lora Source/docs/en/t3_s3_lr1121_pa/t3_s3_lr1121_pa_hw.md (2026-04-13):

<div align="center" markdown="1">
  LilyGo logo
</div>

<h1 align = "center">🌟LilyGo T3 S3 LR1121 PA Version🌟</h1>

## Overview

* This page introduces the hardware parameters related to `LilyGo T3 S3 LR1121 PA Version`

### Notes on use

1. This version does not have BMS, please use a lithium-ion battery with battery protection function
2. Please be sure to connect the antenna before transmitting, otherwise it is easy to damage the RF module
3. The T3-S3 V1.2 and T3-S3 V1.3 use the same pins; the only difference is the charging circuit.

### Product

| Product | SOC | Flash | PSRAM |
| --- | --- | --- | --- |
| [T3-S3][1] | ESP32-S3FH4R2 | 4MB(Quad-SPI) | 2MB(Quad-SPI) |

[1]: https://www.lilygo.cc/products/t3s3-v1-0?variant=42586879688885 "T3-S3"

## PlatformIO Quick Start

1. Install [Visual Studio Code](https://code.visualstudio.com/) and [Python](https://www.python.org/)
2. Search for the `PlatformIO` plugin in the `Visual Studio Code` extension and install it.
3. After the installation is complete, you need to restart `Visual Studio Code`
4. After restarting `Visual Studio Code`, select `File` in the upper left corner of `Visual Studio Code` -> `Open Folder` -> select the `LilyGo-LoRa-Series` directory
5. Wait for the installation of third-party dependent libraries to complete
6. Click on the `platformio.ini` file, and in the `platformio` column
7. Select the board name you want to use in `default_envs` and uncomment it.
8. Uncomment one of the lines `src_dir = xxxx` to make sure only one line works , Please note the example comments, indicating what works and what does not.
9. Click the (✔) symbol in the lower left corner to compile
10. Connect the board to the computer USB-C , Micro-USB is used for module firmware upgrade
11. Click (→) to upload firmware
12. Click (plug symbol) to monitor serial output
13. If it cannot be written, or the USB device keeps flashing, please check the **FAQ** below

## Arduino IDE quick start

1. Install [Arduino IDE](https://www.arduino.cc/en/software)
2. Install [Arduino ESP32](https://docs.espressif.com/projects/arduino-esp32/en/latest/)
3. Copy all folders in the `lib` directory to the `Sketchbook location` directory. How to find the location of your own libraries, [please see here](https://support.arduino.cc/hc/en-us/articles/4415103213714-Find-sketches-libraries-board-cores-and-other-files-on-your-computer)
    * Windows: `C:\Users\{username}\Documents\Arduino`
    * macOS: `/Users/{username}/Documents/Arduino`
    * Linux: `/home/{username}/Arduino`
4. Open the corresponding example
    * Open the downloaded `LilyGo-LoRa-Series`
    * Open `examples`
    * Select the sample file and open the file ending with `ino`
5. On Arduino Select the corresponding board in the IDE tool project and click on the corresponding option in the list below to select

    | Name                                 | Value                                                |
    | ------------------------------------ | ---------------------------------------------------- |
    | Board                                | **ESP32S3 Dev Module**                               |
    | Port                                 | Your port                                            |
    | USB CDC On Boot                      | Enable                                               |
    | CPU Frequency                        | 240MHZ(WiFi)                                         |
    | Core Debug Level                     | None                                                 |
    | USB DFU On Boot                      | Disable                                              |
    | Erase All Flash Before Sketch Upload | Disable                                              |
    | Flash Mode                           | QIO 80Mhz                                            |
    | Flash Size                           | **4MB(32Mb)**                                        |
    | Arduino Runs On                      | Core1                                                |
    | USB Firmware MSC On Boot             | Disable                                              |
    | Partition Scheme                     | **Default 4MB with spiffs (1.2MB APP/1.5MB SPIFFS)** |
    | PSRAM                                | **OPI PSRAM**                                        |
    | Upload Speed                         | 921600                                               |
    | Programmer                           | **Esptool**                                          |

6. Please uncomment the `utilities.h` file of each sketch according to your board model e.g `T3_S3_V1_2_LR1121_PA`, otherwise the compilation will report an error.
7. Upload sketch

### 📍 Pins Map

| Name | GPIO NUM | Free |
| --- | --- | ---- |
| (QWIIC) Uart1 TX | 43(External QWIIC Socket) | ✅️ |
| (QWIIC) Uart1 RX | 44(External QWIIC Socket) | ✅️ |
| QWIIC Socket IO10* | 10(External QWIIC Socket) | ✅️ |
| QWIIC Socket IO21* | 21(External QWIIC Socket) | ✅️ |
| SDA | 18 | ❌ |
| SCL | 17 | ❌ |
| OLED(**SSD1306**) SDA  | Share with I2C bus | ❌ |
| OLED(**SSD1306**) SCL  | Share with I2C bus | ❌ |
| SD CS | 13 | ❌ |
| SD MOSI | 11 | ❌ |
| SD MISO | 2 | ❌ |
| SD SCK | 14 | ❌ |
| LoRa(**LR1121**) SCK | 5 | ❌ |
| LoRa(**LR1121**) MISO  | 3 | ❌ |
| LoRa(**LR1121**) MOSI  | 6 | ❌ |
| LoRa(**LR1121**) RESET | 8 | ❌ |
| LoRa(**LR1121**) DIO9  | 36 | ❌ |
| LoRa(**LR1121**) BUSY  | 34 | ❌ |
| LoRa(**LR1121**) CS | 7 | ❌ |
| Button1 (BOOT) | 0 | ❌ |
| Battery ADC | 1 | ❌ |
| On Board LED | 37 | ❌ |

* You can use GPIO10,21 by removing the two resistors in the figure below. Otherwise, the GPIO is connected to DIO8,DIO7 of Radio by default.
* SDA(18) and SCL(17) are not brought out and cannot be accessed. They can only be used as other GPIOs through QWIIC or header pins. During initialization, use explicit initialization `Wire.begin(sda,scl);` Any unused GPIO can be used as SDA and SCL.

| T3 V1.2 | T3 V1.3 |
| --- | --- |
| T3-S3-QWIIC | T3-S3-QWIIC |

### 🧑🏼‍🔧 I2C Devices Address

| Devices | 7-Bit Address | Share Bus |
| --- | --- | --- |
| OLED Display SSD1306 | 0x3C | ✅️ |

### ⚡ Electrical parameters

| Features | Details  |
| --- | --- |
| 🔗USB-C Input Voltage | 5V |
| 🔗Solar Input Voltage(T3 V1.3 Only) | 4.5~5.6V |
| ⚡Charge Current | 500mA |
| 🔋Battery Voltage | 3.7V |
| 🔋Battery Socket Cables | PH2.0mm  |
| 🔗QWIIC Socket Cables | JST1.0 |

> \[!IMPORTANT]
> T3 V1.3 The maximum solar input voltage can only be 5.6V. If the voltage exceeds this, the Zener diode will discharge and cause the diode to heat up.T3 V1.3 
>

### Button Description

| Channel | Peripherals |
| --- | --- |
| BOOT | Boot mode button, customizable |
| RST | Reset button |

### LED Description

* CHG LED

| LED State | Details |
| --- | --- |
| On | Battery charging |
| Off | Battery Full |
| Blink | Battery not connected |

* User LED

1. The LED is connected to ESP32 GPIO37, and the LED is turned on or off by writing a high or low level

### RF parameters

| Features | Details |
| --- | --- |
| RF  Module | LR1121 |
| Frequency range | 400-520MHz/830-945MHz/2400-2500MHz |
| Transfer rate(LoRa Sub1G) | 0.018 K ～ 62.5 Kbps |
| Transfer rate(FSK Sub1G)  | 0.6 K ～ 300 Kbps |
| Transfer rate(LoRa 2.4G)  | 0.476 K~101.5 Kbps |
| Modulation | LoRa,FSK,LR-HFSS |

> \[!IMPORTANT]
>
> ⚠️⚠️⚠️
> LR1121 version with a built-in PA, do not set the maximum power above 0dBm.
> This is because a power amplifier is added to the RF front end; setting it to 0dBm will achieve an output power of 22dBm.
> Setting it above 1dBm may damage the PA.
>

### LoRa Antenna Switch Truth Table

| Freq | Mode  | DIO5_SW0 | DIO6_SW1 | DIO7_SW2 | DIO8_SW3 |
| --- | ----- | --- | --- | --- | --- |
| 868/915 | TX | 0 | 1 | 0 | 0 |
| 868/915 | RX | 1 | 0 | 0 | 0 |
| 2.4G | TX | 0 | 0 | 1 | 0 |
| 2.4G | RX | 0 | 0 | 0 | 1 |
| SLEEP | SLEEP | 0 | 0 | 0 | 0 |

## WiFi-IPEX

* The following figure shows how to switch the onboard WIFI antenna to IPEX

| T3 V1.2 | T3 V1.3 |
| --- | --- |
| T3-S3 | T3-S3 |

## LoRa-IPEX

* The following figure shows how to switch the onboard LoRa SMA antenna to IPEX

LORA-IPEX

### LR1121 RF Block Diagram

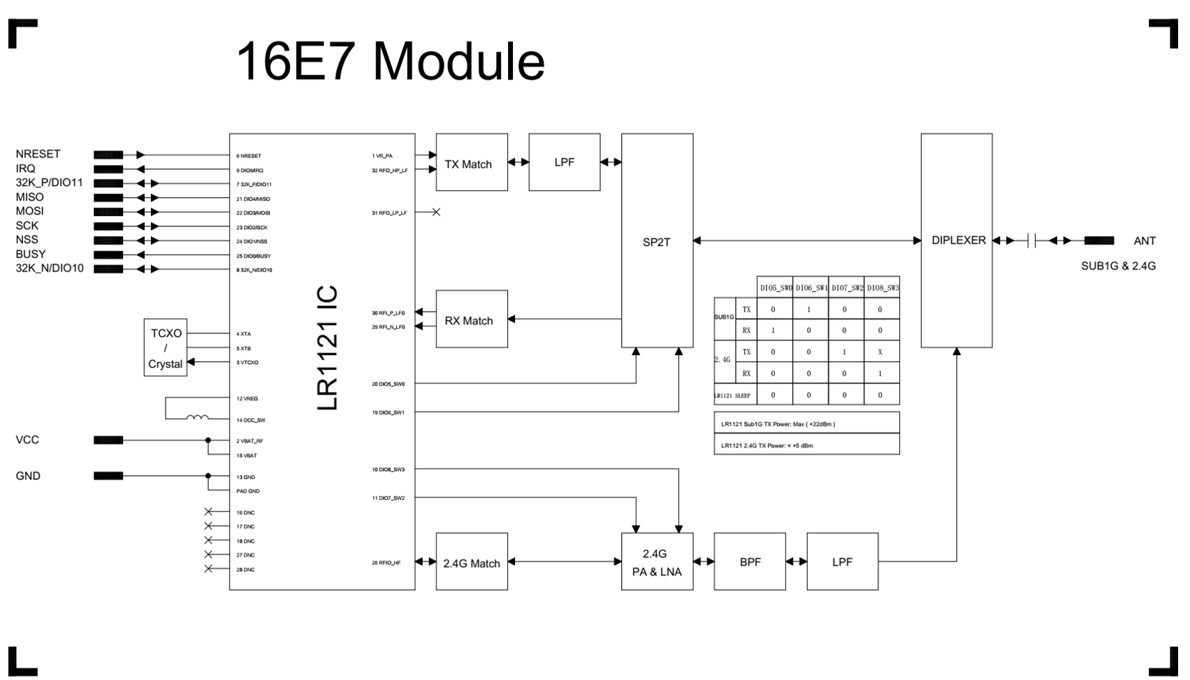
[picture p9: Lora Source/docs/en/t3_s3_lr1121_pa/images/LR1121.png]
RF Block Diagram


#### Resource

* [T3_S3_V1.2 schematic](../../../schematic/T3_S3_V1.2.pdf)
* [T3_S3_V1.3 schematic](../../../schematic/T3_S3_V1.3.pdf)
* [LR1121 datasheet](https://www.semtech.com/products/wireless-rf/lora-connect/lr1121)

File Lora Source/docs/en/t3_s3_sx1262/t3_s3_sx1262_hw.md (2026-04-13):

<div align="center" markdown="1">
  LilyGo logo
</div>

<h1 align = "center">🌟LilyGo T3 S3 SX1262🌟</h1>

## Overview

* This page introduces the hardware parameters related to `LilyGo T3 S3 SX1262`

### Notes on use

1. This version does not have BMS, please use a lithium-ion battery with battery protection function
2. Please be sure to connect the antenna before transmitting, otherwise it is easy to damage the RF module
3. The T3-S3 V1.2 and T3-S3 V1.3 use the same pins; the only difference is the charging circuit.

### Product

| Product | SOC | Flash | PSRAM |
| --- | --- | --- | --- |
| [T3-S3][1] | ESP32-S3FH4R2 | 4MB(Quad-SPI) | 2MB(Quad-SPI) |

[1]: https://www.lilygo.cc/products/t3s3-v1-0?variant=42586879688885 "T3-S3"

## PlatformIO Quick Start

1. Install [Visual Studio Code](https://code.visualstudio.com/) and [Python](https://www.python.org/)
2. Search for the `PlatformIO` plugin in the `Visual Studio Code` extension and install it.
3. After the installation is complete, you need to restart `Visual Studio Code`
4. After restarting `Visual Studio Code`, select `File` in the upper left corner of `Visual Studio Code` -> `Open Folder` -> select the `LilyGo-LoRa-Series` directory
5. Wait for the installation of third-party dependent libraries to complete
6. Click on the `platformio.ini` file, and in the `platformio` column
7. Select the board name you want to use in `default_envs` and uncomment it.
8. Uncomment one of the lines `src_dir = xxxx` to make sure only one line works , Please note the example comments, indicating what works and what does not.
9. Click the (✔) symbol in the lower left corner to compile
10. Connect the board to the computer USB-C , Micro-USB is used for module firmware upgrade
11. Click (→) to upload firmware
12. Click (plug symbol) to monitor serial output
13. If it cannot be written, or the USB device keeps flashing, please check the **FAQ** below

## Arduino IDE quick start

1. Install [Arduino IDE](https://www.arduino.cc/en/software)
2. Install [Arduino ESP32](https://docs.espressif.com/projects/arduino-esp32/en/latest/)
3. Copy all folders in the `lib` directory to the `Sketchbook location` directory. How to find the location of your own libraries, [please see here](https://support.arduino.cc/hc/en-us/articles/4415103213714-Find-sketches-libraries-board-cores-and-other-files-on-your-computer)
    * Windows: `C:\Users\{username}\Documents\Arduino`
    * macOS: `/Users/{username}/Documents/Arduino`
    * Linux: `/home/{username}/Arduino`
4. Open the corresponding example
    * Open the downloaded `LilyGo-LoRa-Series`
    * Open `examples`
    * Select the sample file and open the file ending with `ino`
5. On Arduino Select the corresponding board in the IDE tool project and click on the corresponding option in the list below to select

    | Name                                 | Value                                                |
    | ------------------------------------ | ---------------------------------------------------- |
    | Board                                | **LilyGo T3-S3**                                     |
    | Port                                 | Your port                                            |
    | USB CDC On Boot                      | Enable                                               |
    | CPU Frequency                        | 240MHZ(WiFi)                                         |
    | Core Debug Level                     | None                                                 |
    | USB DFU On Boot                      | Disable                                              |
    | Erase All Flash Before Sketch Upload | Disable                                              |
    | Events Run On                        | Core1                                                |
    | Arduino Runs On                      | Core1                                                |
    | USB Firmware MSC On Boot             | Disable                                              |
    | Partition Scheme                     | **Default 4MB with spiffs (1.2MB APP/1.5MB SPIFFS)** |
    | PSRAM                                | **QSPI PSRAM**                                       |
    | **Board Revision***                  | **Radio-SX1262**                                     |
    | Upload Mode                          | **UART0/Hardware CDC**                               |
    | Upload Speed                         | 921600                                               |
    | USB Mode                             | **CDC and JTAG**                                     |
    | Programmer                           | **Esptool**                                          |

     * **Board revision Select according to actual model**

6. Upload sketch

### 📍 Pins Map

| Name | GPIO NUM | Free |
| --- | --- | ---- |
| (QWIIC) Uart1 TX | 43(External QWIIC Socket) | ✅️ |
| (QWIIC) Uart1 RX | 44(External QWIIC Socket) | ✅️ |
| QWIIC Socket IO10* | 10(External QWIIC Socket) | ✅️ |
| QWIIC Socket IO21* | 21(External QWIIC Socket) | ✅️ |
| SDA | 18 | ❌ |
| SCL | 17 | ❌ |
| OLED(**SSD1306**) SDA  | Share with I2C bus | ❌ |
| OLED(**SSD1306**) SCL  | Share with I2C bus | ❌ |
| SD CS | 13 | ❌ |
| SD MOSI | 11 | ❌ |
| SD MISO | 2 | ❌ |
| SD SCK | 14 | ❌ |
| LoRa(**SX1262**) SCK | 5 | ❌ |
| LoRa(**SX1262**) MISO  | 3 | ❌ |
| LoRa(**SX1262**) MOSI  | 6 | ❌ |
| LoRa(**SX1262**) RESET | 8 | ❌ |
| LoRa(**SX1262**) DIO1  | 33 | ❌ |
| LoRa(**SX1262**) BUSY  | 34 | ❌ |
| LoRa(**SX1262**) CS | 7 | ❌ |
| Button1 (BOOT) | 0 | ❌ |
| Battery ADC | 1 | ❌ |
| On Board LED | 37 | ❌ |

* You can use GPIO10,21 by removing the two resistors in the figure below. Otherwise, the GPIO is connected to DIO3,DIO4 of Radio by default.
* SDA(18) and SCL(17) are not brought out and cannot be accessed. They can only be used as other GPIOs through QWIIC or header pins. During initialization, use explicit initialization `Wire.begin(sda,scl);` Any unused GPIO can be used as SDA and SCL.

| T3 V1.2 | T3 V1.3 |
| --- | --- |
| T3-S3-QWIIC | T3-S3-QWIIC |

### 🧑🏼‍🔧 I2C Devices Address

| Devices | 7-Bit Address | Share Bus |
| --- | --- | --- |
| OLED Display SSD1306 | 0x3C | ✅️ |

### ⚡ Electrical parameters

| Features | Details  |
| --- | --- |
| 🔗USB-C Input Voltage | 5V |
| 🔗Solar Input Voltage(T3 V1.3 Only) | 4.5~5.6V |
| ⚡Charge Current | 500mA |
| 🔋Battery Voltage | 3.7V |
| 🔋Battery Socket Cables | PH2.0mm  |
| 🔗QWIIC Socket Cables | JST1.0 |

> \[!IMPORTANT]
> T3 V1.3 The maximum solar input voltage can only be 5.6V. If the voltage exceeds this, the Zener diode will discharge and cause the diode to heat up.T3 V1.3 
>

### Button Description

| Channel | Peripherals |
| --- | --- |
| BOOT | Boot mode button, customizable |
| RST | Reset button |

### LED Description

* CHG LED

| LED State | Details |
| --- | --- |
| On | Battery charging |
| Off | Battery Full |
| Blink | Battery not connected |

* User LED

1. The LED is connected to ESP32 GPIO37, and the LED is turned on or off by writing a high or low level

### RF parameters

| Features | Details |
| --- | --- |
| RF  Module | SX1262 |
| Frequency range | 868/915MHz |
| Transfer rate(LoRa) | 0.018 K ～ 62.5 Kbps |
| Transfer rate(FSK)  | 0.6 K ～ 300 Kbps |
| Modulation | FSK, GFSK, MSK, GMSK, LoRa,OOK |

## WiFi-IPEX

* The following figure shows how to switch the onboard WIFI antenna to IPEX

| T3 V1.2 | T3 V1.3 |
| --- | --- |
| T3-S3 | T3-S3 |

## LoRa-IPEX

* The following figure shows how to switch the onboard LoRa SMA antenna to IPEX

LORA-IPEX

### SX1262 RF Block Diagram

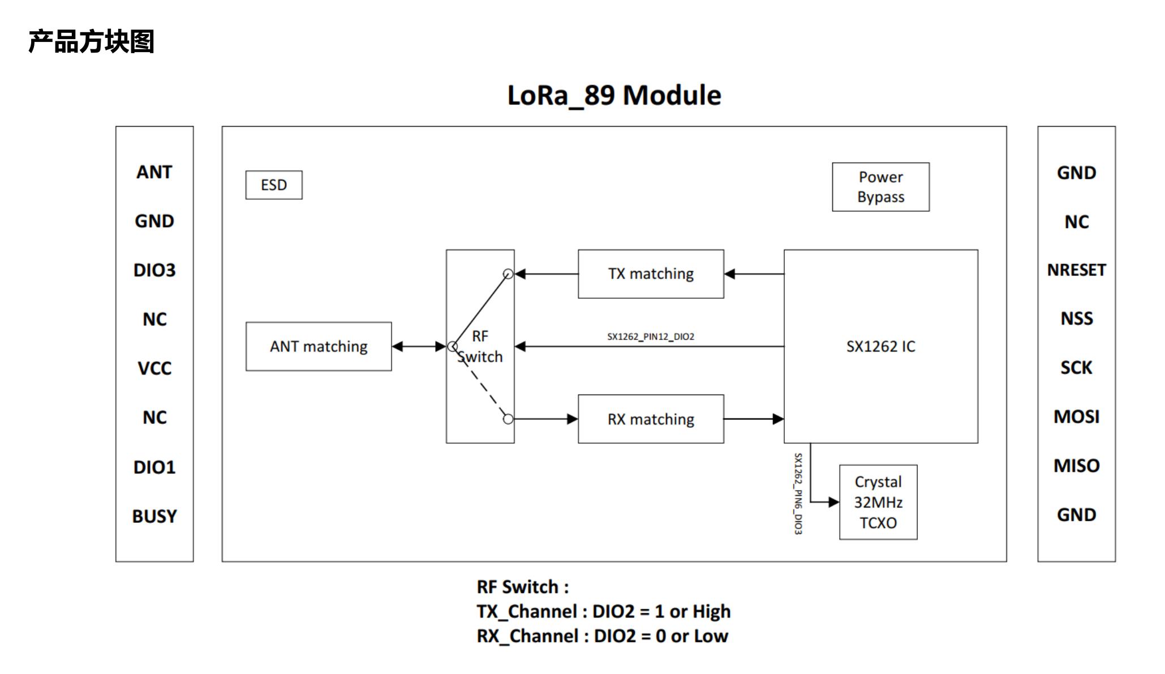
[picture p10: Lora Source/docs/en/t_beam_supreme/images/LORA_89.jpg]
RF Block Diagram


#### Resource

* [T3_S3_V1.2 schematic](../../../schematic/T3_S3_V1.2.pdf)
* [T3_S3_V1.3 schematic](../../../schematic/T3_S3_V1.3.pdf)
* [SX1262 datasheet](https://www.semtech.com/products/wireless-rf/lora-transceivers/sx1262)

### Application

* [T-Beam Meshtastic](https://github.com/meshtastic/Meshtastic-device)

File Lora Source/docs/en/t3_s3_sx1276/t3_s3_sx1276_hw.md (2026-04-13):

<div align="center" markdown="1">
  LilyGo logo
</div>

<h1 align = "center">🌟LilyGo T3 S3 SX1276🌟</h1>

## Overview

* This page introduces the hardware parameters related to `LilyGo T3 S3 SX1276`

### Notes on use

1. This version does not have BMS, please use a lithium-ion battery with battery protection function
2. Please be sure to connect the antenna before transmitting, otherwise it is easy to damage the RF module
3. The T3-S3 V1.2 and T3-S3 V1.3 use the same pins; the only difference is the charging circuit.

### Product

| Product | SOC | Flash | PSRAM |
| --- | --- | --- | --- |
| [T3-S3][1] | ESP32-S3FH4R2 | 4MB(Quad-SPI) | 2MB(Quad-SPI) |

[1]: https://www.lilygo.cc/products/t3s3-v1-0?variant=42586879688885 "T3-S3"

## PlatformIO Quick Start

1. Install [Visual Studio Code](https://code.visualstudio.com/) and [Python](https://www.python.org/)
2. Search for the `PlatformIO` plugin in the `Visual Studio Code` extension and install it.
3. After the installation is complete, you need to restart `Visual Studio Code`
4. After restarting `Visual Studio Code`, select `File` in the upper left corner of `Visual Studio Code` -> `Open Folder` -> select the `LilyGo-LoRa-Series` directory
5. Wait for the installation of third-party dependent libraries to complete
6. Click on the `platformio.ini` file, and in the `platformio` column
7. Select the board name you want to use in `default_envs` and uncomment it.
8. Uncomment one of the lines `src_dir = xxxx` to make sure only one line works , Please note the example comments, indicating what works and what does not.
9. Click the (✔) symbol in the lower left corner to compile
10. Connect the board to the computer USB-C , Micro-USB is used for module firmware upgrade
11. Click (→) to upload firmware
12. Click (plug symbol) to monitor serial output
13. If it cannot be written, or the USB device keeps flashing, please check the **FAQ** below

## Arduino IDE quick start

1. Install [Arduino IDE](https://www.arduino.cc/en/software)
2. Install [Arduino ESP32](https://docs.espressif.com/projects/arduino-esp32/en/latest/)
3. Copy all folders in the `lib` directory to the `Sketchbook location` directory. How to find the location of your own libraries, [please see here](https://support.arduino.cc/hc/en-us/articles/4415103213714-Find-sketches-libraries-board-cores-and-other-files-on-your-computer)
    * Windows: `C:\Users\{username}\Documents\Arduino`
    * macOS: `/Users/{username}/Documents/Arduino`
    * Linux: `/home/{username}/Arduino`
4. Open the corresponding example
    * Open the downloaded `LilyGo-LoRa-Series`
    * Open `examples`
    * Select the sample file and open the file ending with `ino`
5. On Arduino Select the corresponding board in the IDE tool project and click on the corresponding option in the list below to select

    | Name                                 | Value                                                |
    | ------------------------------------ | ---------------------------------------------------- |
    | Board                                | **LilyGo T3-S3**                                     |
    | Port                                 | Your port                                            |
    | USB CDC On Boot                      | Enable                                               |
    | CPU Frequency                        | 240MHZ(WiFi)                                         |
    | Core Debug Level                     | None                                                 |
    | USB DFU On Boot                      | Disable                                              |
    | Erase All Flash Before Sketch Upload | Disable                                              |
    | Events Run On                        | Core1                                                |
    | Arduino Runs On                      | Core1                                                |
    | USB Firmware MSC On Boot             | Disable                                              |
    | Partition Scheme                     | **Default 4MB with spiffs (1.2MB APP/1.5MB SPIFFS)** |
    | PSRAM                                | **QSPI PSRAM**                                       |
    | **Board Revision***                  | **Radio-SX1276**                                     |
    | Upload Mode                          | **UART0/Hardware CDC**                               |
    | Upload Speed                         | 921600                                               |
    | USB Mode                             | **CDC and JTAG**                                     |
    | Programmer                           | **Esptool**                                          |

     * **Board revision Select according to actual model**

6. Upload sketch

### 📍 Pins Map

| Name | GPIO NUM | Free |
| --- | --- | ---- |
| (QWIIC) Uart1 TX | 43(External QWIIC Socket) | ✅️ |
| (QWIIC) Uart1 RX | 44(External QWIIC Socket) | ✅️ |
| QWIIC Socket IO10* | 10(External QWIIC Socket) | ✅️ |
| QWIIC Socket IO21* | 21(External QWIIC Socket) | ✅️ |
| SDA | 18 | ❌ |
| SCL | 17 | ❌ |
| OLED(**SSD1306**) SDA  | Share with I2C bus | ❌ |
| OLED(**SSD1306**) SCL  | Share with I2C bus | ❌ |
| SD CS | 13 | ❌ |
| SD MOSI | 11 | ❌ |
| SD MISO | 2 | ❌ |
| SD SCK | 14 | ❌ |
| LoRa(**SX1276**) SCK | 5 | ❌ |
| LoRa(**SX1276**) MISO  | 3 | ❌ |
| LoRa(**SX1276**) MOSI  | 6 | ❌ |
| LoRa(**SX1276**) RESET | 8 | ❌ |
| LoRa(**SX1276**) DIO0  | 9 | ❌ |
| LoRa(**SX1276**) DIO1  | 33 | ❌ |
| LoRa(**SX1276**) DIO2  | 34 | ❌ |
| LoRa(**SX1276**) DIO3  | 21 | ❌ |
| LoRa(**SX1276**) DIO4  | 10 | ❌ |
| LoRa(**SX1276**) DIO5  | 36 | ❌ |
| LoRa(**SX1276**) CS | 7 | ❌ |
| Button1 (BOOT) | 0 | ❌ |
| Battery ADC | 1 | ❌ |
| On Board LED | 37 | ❌ |

* You can use GPIO10,21 by removing the two resistors in the figure below. Otherwise, the GPIO is connected to DIO3,DIO4 of Radio by default.
* SDA(18) and SCL(17) are not brought out and cannot be accessed. They can only be used as other GPIOs through QWIIC or header pins. During initialization, use explicit initialization `Wire.begin(sda,scl);` Any unused GPIO can be used as SDA and SCL.

| T3 V1.2 | T3 V1.3 |
| --- | --- |
| T3-S3-QWIIC | T3-S3-QWIIC |

### 🧑🏼‍🔧 I2C Devices Address

| Devices | 7-Bit Address | Share Bus |
| --- | --- | --- |
| OLED Display SSD1306 | 0x3C | ✅️ |

### ⚡ Electrical parameters

| Features | Details  |
| --- | --- |
| 🔗USB-C Input Voltage | 5V |
| 🔗Solar Input Voltage(T3 V1.3 Only) | 4.5~5.6V |
| ⚡Charge Current | 500mA |
| 🔋Battery Voltage | 3.7V |
| 🔋Battery Socket Cables | PH2.0mm  |
| 🔗QWIIC Socket Cables | JST1.0 |

> \[!IMPORTANT]
> T3 V1.3 The maximum solar input voltage can only be 5.6V. If the voltage exceeds this, the Zener diode will discharge and cause the diode to heat up.T3 V1.3 
>

### Button Description

| Channel | Peripherals |
| --- | --- |
| BOOT | Boot mode button, customizable |
| RST | Reset button |

### LED Description

* CHG LED

| LED State | Details |
| --- | --- |
| On | Battery charging |
| Off | Battery Full |
| Blink | Battery not connected |

* User LED

1. The LED is connected to ESP32 GPIO37, and the LED is turned on or off by writing a high or low level

### RF parameters

| Features | Details |
| --- | --- |
| RF  Module | SX1276 |
| Frequency range | 840～945MHz |
| Transfer rate(LoRa) | 0.018K～37.5Kbps |
| Transfer rate(FSK)  | 1.2K～300Kbps |
| Modulation | FSK, GFSK, MSK, GMSK, LoRa，OOK |

> [!IMPORTANT]
> When the bandwidth is lower than 62.5kHz, LoRa modules using non-TCXOs will not be able to communicate fully.
> This will result in poor communication quality.
> If you need to use a bandwidth lower than 62.5kHz, please use a [TCXO Version](https://lilygo.cc/products/t3-s3-v1-3?variant=45367157883061)
>

## WiFi-IPEX

* The following figure shows how to switch the onboard WIFI antenna to IPEX

| T3 V1.2 | T3 V1.3 |
| --- | --- |
| T3-S3 | T3-S3 |

## LoRa-IPEX

* The following figure shows how to switch the onboard LoRa SMA antenna to IPEX

LORA-IPEX

#### Resource

* [T3_S3_V1.2 schematic](../../../schematic/T3_S3_V1.2.pdf)
* [T3_S3_V1.3 schematic](../../../schematic/T3_S3_V1.3.pdf)
* [SX1276 datasheet](https://www.semtech.com/products/wireless-rf/lora-connect/sx1276)

### Application

* [T-Beam Meshtastic](https://github.com/meshtastic/Meshtastic-device)

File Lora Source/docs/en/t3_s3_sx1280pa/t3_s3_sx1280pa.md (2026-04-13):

<div align="center" markdown="1">
  LilyGo logo
</div>

<h1 align = "center">🌟LilyGo T3 S3 SX1280PA🌟</h1>

## Overview

* This page introduces the hardware parameters related to `LilyGo T3 S3 SX1280PA`

### Notes on use

1. This version does not have BMS, please use a lithium-ion battery with battery protection function
2. Please be sure to connect the antenna before transmitting, otherwise it is easy to damage the RF module
3. The T3-S3 V1.2 and T3-S3 V1.3 use the same pins; the only difference is the charging circuit.

### Product

| Product | SOC | Flash | PSRAM |
| --- | --- | --- | --- |
| [T3-S3][1] | ESP32-S3FH4R2 | 4MB(Quad-SPI) | 2MB(Quad-SPI) |

[1]: https://www.lilygo.cc/products/t3s3-v1-0?variant=42586879688885 "T3-S3"

## PlatformIO Quick Start

1. Install [Visual Studio Code](https://code.visualstudio.com/) and [Python](https://www.python.org/)
2. Search for the `PlatformIO` plugin in the `Visual Studio Code` extension and install it.
3. After the installation is complete, you need to restart `Visual Studio Code`
4. After restarting `Visual Studio Code`, select `File` in the upper left corner of `Visual Studio Code` -> `Open Folder` -> select the `LilyGo-LoRa-Series` directory
5. Wait for the installation of third-party dependent libraries to complete
6. Click on the `platformio.ini` file, and in the `platformio` column
7. Select the board name you want to use in `default_envs` and uncomment it.
8. Uncomment one of the lines `src_dir = xxxx` to make sure only one line works , Please note the example comments, indicating what works and what does not.
9. Click the (✔) symbol in the lower left corner to compile
10. Connect the board to the computer USB-C , Micro-USB is used for module firmware upgrade
11. Click (→) to upload firmware
12. Click (plug symbol) to monitor serial output
13. If it cannot be written, or the USB device keeps flashing, please check the **FAQ** below

## Arduino IDE quick start

1. Install [Arduino IDE](https://www.arduino.cc/en/software)
2. Install [Arduino ESP32](https://docs.espressif.com/projects/arduino-esp32/en/latest/)
3. Copy all folders in the `lib` directory to the `Sketchbook location` directory. How to find the location of your own libraries, [please see here](https://support.arduino.cc/hc/en-us/articles/4415103213714-Find-sketches-libraries-board-cores-and-other-files-on-your-computer)
    * Windows: `C:\Users\{username}\Documents\Arduino`
    * macOS: `/Users/{username}/Documents/Arduino`
    * Linux: `/home/{username}/Arduino`
4. Open the corresponding example
    * Open the downloaded `LilyGo-LoRa-Series`
    * Open `examples`
    * Select the sample file and open the file ending with `ino`
5. On Arduino Select the corresponding board in the IDE tool project and click on the corresponding option in the list below to select

    | Name                                 | Value                                                |
    | ------------------------------------ | ---------------------------------------------------- |
    | Board                                | **LilyGo T3-S3**                                     |
    | Port                                 | Your port                                            |
    | USB CDC On Boot                      | Enable                                               |
    | CPU Frequency                        | 240MHZ(WiFi)                                         |
    | Core Debug Level                     | None                                                 |
    | USB DFU On Boot                      | Disable                                              |
    | Erase All Flash Before Sketch Upload | Disable                                              |
    | Events Run On                        | Core1                                                |
    | Arduino Runs On                      | Core1                                                |
    | USB Firmware MSC On Boot             | Disable                                              |
    | Partition Scheme                     | **Default 4MB with spiffs (1.2MB APP/1.5MB SPIFFS)** |
    | PSRAM                                | **QSPI PSRAM**                                       |
    | **Board Revision***                  | **Radio-SX1280PA**                                   |
    | Upload Mode                          | **UART0/Hardware CDC**                               |
    | Upload Speed                         | 921600                                               |
    | USB Mode                             | **CDC and JTAG**                                     |
    | Programmer                           | **Esptool**                                          |

     * **Board revision Select according to actual model**

6. Upload sketch

### 📍 Pins Map

| Name | GPIO NUM | Free |
| --- | --- | ---- |
| Uart1 TX | 43(External QWIIC Socket) | ✅️ |
| Uart1 RX | 44(External QWIIC Socket) | ✅️ |
| QWIIC Socket IO10* | 10(External QWIIC Socket) | ❌ |
| QWIIC Socket IO21* | 21(External QWIIC Socket) | ❌ |
| SDA | 18 | ❌ |
| SCL | 17 | ❌ |
| OLED(**SSD1306**) SDA  | Share with I2C bus | ❌ |
| OLED(**SSD1306**) SCL  | Share with I2C bus | ❌ |
| SD CS | 13 | ❌ |
| SD MOSI | 11 | ❌ |
| SD MISO | 2 | ❌ |
| SD SCK | 14 | ❌ |
| LoRa(**SX1280**) SCK | 5 | ❌ |
| LoRa(**SX1280**) MISO  | 3 | ❌ |
| LoRa(**SX1280**) MOSI  | 6 | ❌ |
| LoRa(**SX1280**) RESET | 8 | ❌ |
| LoRa(**SX1280**) DIO1  | 9 | ❌ |
| LoRa(**SX1280**) BUSY  | 36 | ❌ |
| LoRa(**SX1280**) CS | 7 | ❌ |
| LoRa(**SX1280**) TX | 10 | ❌ |
| LoRa(**SX1280**) RX | 21 | ❌ |
| Button1 (BOOT) | 0 | ❌ |
| Battery ADC | 1 | ❌ |
| On Board LED | 37 | ❌ |

* QWIIC IO10/IO21 GPIOs are already connected to the Radio TX/RX Pin and cannot be used.
* SDA(18) and SCL(17) are not brought out and cannot be accessed. They can only be used as other GPIOs through QWIIC or header pins. During initialization, use explicit initialization `Wire.begin(sda,scl);` Any unused GPIO can be used as SDA and SCL.

### 🧑🏼‍🔧 I2C Devices Address

| Devices | 7-Bit Address | Share Bus |
| --- | --- | --- |
| OLED Display SSD1306 | 0x3C | ✅️ |

### ⚡ Electrical parameters

| Features | Details  |
| --- | --- |
| 🔗USB-C Input Voltage | 5V |
| 🔗Solar Input Voltage(T3 V1.3 Only) | 4.5~5.6V |
| ⚡Charge Current | 500mA |
| 🔋Battery Voltage | 3.7V |
| 🔋Battery Socket Cables | PH2.0mm  |
| 🔗QWIIC Socket Cables | JST1.0 |

> \[!IMPORTANT]
> T3 V1.3 The maximum solar input voltage can only be 5.6V. If the voltage exceeds this, the Zener diode will discharge and cause the diode to heat up.T3 V1.3 
>

### Button Description

| Channel | Peripherals |
| --- | --- |
| BOOT | Boot mode button, customizable |
| RST | Reset button |

### LED Description

* CHG LED

| LED State | Details |
| --- | --- |
| On | Battery charging |
| Off | Battery Full |
| Blink | Battery not connected |

* User LED

1. The LED is connected to ESP32 GPIO37, and the LED is turned on or off by writing a high or low level

### RF parameters

| Features | Details |
| --- | --- |
| RF  Module | SX1280 |
| Frequency range | 2400 ~ 2500MHz |
| Transfer rate(LoRa) | 0.476 ～ 202 Kbps |
| Transfer rate(FSK)  | 0.125 ～ 20000 Kbps |
| Transfer rate(FLRC) | 260 ～ 1300 Kbps |
| Modulation | LoRa 、 FLRC 、 (G)FSK |

## WiFi-IPEX

* The following figure shows how to switch the onboard WIFI antenna to IPEX

| T3 V1.2 | T3 V1.3 |
| --- | --- |
| T3-S3 | T3-S3 |

## LoRa-IPEX

* The following figure shows how to switch the onboard LoRa SMA antenna to IPEX

LORA-IPEX

### Frequently asked questions

1. When the module turns on PA (transmit) / LNA (receive) data, the module's RX / TX two input pins need to be set. The state truth table is shown in the table below. Setting errors will result in failure to send and receive data normally.

| TX PIN | RX PIN | Radio Status |
| --- | --- | --- |
| 1 | X | PA ( TX active )  |
| 0 | 1 | LNA ( RX active ) |

2. Recommended that the software controls the 1280 chip to output 2~5dbm, so that the entire module will output 20dbm power; When the output of the 1280 chip is higher than 2dbm, the output power of the entire module is only 20dbm; When the output of the 1280 chip is higher than 5dbm, the output power of the entire module is only 20dbm, but if 5dbm is given to the FEM, it will damage the FEM chip (the maximum input allowed by the FEM is 5dbm) .If the output of the 1280 chip is lower than 2dbm, the output power of the entire module is within 20dbm.
3. SX1280 output power setting cannot be greater than 2~5dbm, otherwise the FEM chip may be damaged. Setting 3dbm already has 20dmb output power

#### Resource

* [T3_S3_V1.2 schematic](../../../schematic/T3_S3_V1.2.pdf)
* [T3_S3_V1.3 schematic](../../../schematic/T3_S3_V1.3.pdf)
* [SX1280 datasheet](https://www.semtech.cn/products/wireless-rf/lora-connect/sx1280)

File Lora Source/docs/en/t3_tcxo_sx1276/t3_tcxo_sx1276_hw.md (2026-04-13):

<div align="center" markdown="1">
  LilyGo logo
</div>

<h1 align = "center">🌟LilyGo T3 TCXO SX1276🌟</h1>

## Overview

* This page introduces the hardware parameters related to `LilyGo T3 TCXO SX1276`

### Notes on use

1. This version does not have BMS, please use a lithium-ion battery with battery protection function
2. Please be sure to connect the antenna before transmitting, otherwise it is easy to damage the RF module

### Product

| Product | SOC | Flash | PSRAM |
| --- | --- | --- | ----- |
| [T-3 TCXO][1] | ESP32-PICO-D4 | 4MB(Quad-SPI) | ❌ |

[1]: https://lilygo.cc/products/t3-tcxo "T-3 TCXO"

### PlatformIO Quick Start

1. Install the **CH9102 USB bridge** driver for the first time.
   * [Windows](https://www.wch-ic.com/downloads/CH343SER_ZIP.html)
   * [Mac OS](https://www.wch-ic.com/downloads/CH34XSER_MAC_ZIP.html)
2. Install [Visual Studio Code](https://code.visualstudio.com/) and [Python](https://www.python.org/)
3. Search for the `PlatformIO` plugin in the `Visual Studio Code` extension and install it.
4. After the installation is complete, you need to restart `Visual Studio Code`
5. After restarting `Visual Studio Code`, select `File` in the upper left corner of `Visual Studio Code` -> `Open Folder` -> select the `LilyGo-LoRa-Series` directory
6. Wait for the installation of third-party dependent libraries to complete
7. Click on the `platformio.ini` file, and in the `platformio` column
8. Select the board name you want to use in `default_envs` and uncomment it.
9. Uncomment one of the lines `src_dir = xxxx` to make sure only one line works , Please note the example comments, indicating what works and what does not.
10. Click the (✔) symbol in the lower left corner to compile
11. Connect the board to the computer USB-C , Micro-USB is used for module firmware upgrade
12. Click (→) to upload firmware
13. Click (plug symbol) to monitor serial output
14. If it cannot be written, or the USB device keeps flashing, please check the **FAQ** below

### Arduino IDE quick start

1. Install the **CH9102 USB bridge** driver for the first time.
   * [Windows](https://www.wch-ic.com/downloads/CH343SER_ZIP.html)
   * [Mac OS](https://www.wch-ic.com/downloads/CH34XSER_MAC_ZIP.html)
2. Install [Arduino IDE](https://www.arduino.cc/en/software)
3. Install [Arduino ESP32](https://docs.espressif.com/projects/arduino-esp32/en/latest/)
4. Copy all folders in the `lib` directory to the `Sketchbook location` directory. How to find the location of your own libraries, [please see here](https://support.arduino.cc/hc/en-us/articles/4415103213714-Find-sketches-libraries-board-cores-and-other-files-on-your-computer)
    * Windows: `C:\Users\{username}\Documents\Arduino`
    * macOS: `/Users/{username}/Documents/Arduino`
    * Linux: `/home/{username}/Arduino`
5. Open the corresponding example
    * Open the downloaded `LilyGo-LoRa-Series`
    * Open `examples`
    * Select the sample file and open the file ending with `ino`
6. On Arduino Select the corresponding board in the IDE tool project and click on the corresponding option in the list below to select

    | Name                                 | Value                                |
    | ------------------------------------ | ------------------------------------ |
    | Board                                | **ESP32 Dev Module**                 |
    | Port                                 | Your port                            |
    | CPU Frequency                        | 240MHZ(WiFi/BT)                      |
    | Core Debug Level                     | None                                 |
    | Erase All Flash Before Sketch Upload | Disable                              |
    | Events Run On                        | Core1                                |
    | Flash Frequency                      | 80MHZ                                |
    | Flash Mode                           | QIO                                  |
    | Flash Size                           | **4MB(32Mb)**                        |
    | JTAG Adapter                         | Disabled                             |
    | Arduino Runs On                      | Core1                                |
    | Partition Scheme                     | **Huge APP (3MB No OTA/1MB SPIFFS)** |
    | PSRAM                                | **Enable**                           |
    | Upload Speed                         | 921600                               |
    | Programmer                           | **Esptool**                          |

6. Please uncomment the `utilities.h` file of each sketch according to your board model ,e.g `T3_V3_0_SX1276_TCXO`, otherwise the compilation will report an error.
7. Upload sketch

### 📍 Pins Map

| Name | GPIO NUM | Free |
| --- | --- | ---- |
| OLED(**SSD1306**) SDA | 21 | ❌ |
| OLED(**SSD1306**) SCL | 22 | ❌ |
| SD CS | 13 | ❌ |
| SD MOSI | 15 | ❌ |
| SD MISO | 2 | ❌ |
| SD SCK | 14 | ❌ |
| LoRa(**SX1276**) SCK | 5 | ❌ |
| LoRa(**SX1276**) MISO | 19 | ❌ |
| LoRa(**SX1276**) MOSI | 27 | ❌ |
| LoRa(**SX1276**) RESET | 23 | ❌ |
| LoRa(**SX1276**) DIO0 | 26 | ❌ |
| LoRa(**SX1276**) DIO1 | 32 | ❌ |
| LoRa(**SX1276**) CS | 7 | ❌ |
| LoRa(**SX1276**) TCXO EN | 12 | ❌ |
| Battery ADC | 35 | ❌ |
| On Board LED | 25 | ❌ |

* **The GPIOs above GPIO33 of the ESP32 chip only allow input functions and cannot be set as output functions.**
* **You need to remove the SD card when uploading the sketch, otherwise it will not be downloaded**
* **TCXO EN must be set to high before initializing the Radio**

### 🧑🏼‍🔧 I2C Devices Address

| Devices | 7-Bit Address | Share Bus |
| --- | --- | --- |
| OLED Display SSD1306 | 0x3C | ✅️ |

### ⚡ Electrical parameters

| Features | Details |
| --- | --- |
| 🔗USB-C Input Voltage | 5V |
| ⚡Charge Current | 500mA |
| 🔋Battery Voltage | 3.7V |

### Button Description

| Channel | Peripherals  |
| --- | --- |
| RST | Reset button |

### LED Description

* CHG LED

| LED State | Details |
| --- | --- |
| On | Battery charging |
| Off | Battery Full |
| Blink | Battery not connected |

* User LED

1. The LED is connected to ESP32 GPIO25, and the LED is turned on or off by writing a high or low level

### RF parameters

| Features | Details |
| --- | --- |
| RF  Module | SX1276 |
| Frequency range | 840～945MHz |
| Transfer rate(LoRa) | 0.018K～37.5Kbps |
| Transfer rate(FSK)  | 1.2K～300Kbps |
| Modulation | FSK, GFSK, MSK, GMSK, LoRa，OOK |

> [!IMPORTANT]
> When the bandwidth is lower than 62.5kHz, LoRa modules using non-TCXOs will not be able to fully communicate, resulting in poor communication quality.
> Modules equipped with TCXOs do not experience this issue.
>

#### Resource

* [T3-TCXO schematic](../../../schematic/T3_V3.0.pdf)
* [SX1276 datasheet](https://www.semtech.com/products/wireless-rf/lora-transceivers/sx1276)
* [T3-TCXO DXF](../../../dimensions/T3_V3.0_TCXO.dxf)

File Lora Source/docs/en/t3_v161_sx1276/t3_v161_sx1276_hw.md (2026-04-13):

<div align="center" markdown="1">
  LilyGo logo
</div>

<h1 align = "center">🌟LilyGo LoRa32 SX1276🌟</h1>

## Overview

* This page introduces the hardware parameters related to `LilyGo LoRa32 SX1276`

### Notes on use

1. This version does not have BMS, please use a lithium-ion battery with battery protection function
2. Please be sure to connect the antenna before transmitting, otherwise it is easy to damage the RF module

### Product

| Product | SOC | Flash | PSRAM |
| --- | --- | --- | ----- |
| [LoRa32 V1.6.1][1] | ESP32-PICO-D4 | 4MB(Quad-SPI) | ❌ |

[1]: https://lilygo.cc/products/lora3 "LoRa32 V1.6.1"

### PlatformIO Quick Start

1. Install the **CH9102 USB bridge** driver for the first time.
   * [Windows](https://www.wch-ic.com/downloads/CH343SER_ZIP.html)
   * [Mac OS](https://www.wch-ic.com/downloads/CH34XSER_MAC_ZIP.html)
2. Install [Visual Studio Code](https://code.visualstudio.com/) and [Python](https://www.python.org/)
3. Search for the `PlatformIO` plugin in the `Visual Studio Code` extension and install it.
4. After the installation is complete, you need to restart `Visual Studio Code`
5. After restarting `Visual Studio Code`, select `File` in the upper left corner of `Visual Studio Code` -> `Open Folder` -> select the `LilyGo-LoRa-Series` directory
6. Wait for the installation of third-party dependent libraries to complete
7. Click on the `platformio.ini` file, and in the `platformio` column
8. Select the board name you want to use in `default_envs` and uncomment it.
9. Uncomment one of the lines `src_dir = xxxx` to make sure only one line works , Please note the example comments, indicating what works and what does not.
10. Click the (✔) symbol in the lower left corner to compile
11. Connect the board to the computer USB-C , Micro-USB is used for module firmware upgrade
12. Click (→) to upload firmware
13. Click (plug symbol) to monitor serial output
14. If it cannot be written, or the USB device keeps flashing, please check the **FAQ** below

### Arduino IDE quick start

1. Install the **CH9102 USB bridge** driver for the first time.
   * [Windows](https://www.wch-ic.com/downloads/CH343SER_ZIP.html)
   * [Mac OS](https://www.wch-ic.com/downloads/CH34XSER_MAC_ZIP.html)
2. Install [Arduino IDE](https://www.arduino.cc/en/software)
3. Install [Arduino ESP32](https://docs.espressif.com/projects/arduino-esp32/en/latest/)
4. Copy all folders in the `lib` directory to the `Sketchbook location` directory. How to find the location of your own libraries, [please see here](https://support.arduino.cc/hc/en-us/articles/4415103213714-Find-sketches-libraries-board-cores-and-other-files-on-your-computer)
    * Windows: `C:\Users\{username}\Documents\Arduino`
    * macOS: `/Users/{username}/Documents/Arduino`
    * Linux: `/home/{username}/Arduino`
5. Open the corresponding example
    * Open the downloaded `LilyGo-LoRa-Series`
    * Open `examples`
    * Select the sample file and open the file ending with `ino`
6. On Arduino Select the corresponding board in the IDE tool project and click on the corresponding option in the list below to select

    | Name                                 | Value                                |
    | ------------------------------------ | ------------------------------------ |
    | Board                                | **ESP32 Dev Module**                 |
    | Port                                 | Your port                            |
    | CPU Frequency                        | 240MHZ(WiFi/BT)                      |
    | Core Debug Level                     | None                                 |
    | Erase All Flash Before Sketch Upload | Disable                              |
    | Events Run On                        | Core1                                |
    | Flash Frequency                      | 80MHZ                                |
    | Flash Mode                           | QIO                                  |
    | Flash Size                           | **4MB(32Mb)**                        |
    | JTAG Adapter                         | Disabled                             |
    | Arduino Runs On                      | Core1                                |
    | Partition Scheme                     | **Huge APP (3MB No OTA/1MB SPIFFS)** |
    | PSRAM                                | **Enable**                           |
    | Upload Speed                         | 921600                               |
    | Programmer                           | **Esptool**                          |

6. Please uncomment the `utilities.h` file of each sketch according to your board model ,e.g `T3_V1_6_SX1276` or `T3_V1_6_SX1278`, otherwise the compilation will report an error.
7. Upload sketch

### 📍 Pins Map

| Name | GPIO NUM | Free |
| --- | --- | ---- |
| OLED(**SSD1306**) SDA  | 21 | ❌ |
| OLED(**SSD1306**) SCL  | 22 | ❌ |
| SD CS | 13 | ❌ |
| SD MOSI | 15 | ❌ |
| SD MISO | 2 | ❌ |
| SD SCK | 14 | ❌ |
| LoRa(**SX1276**) SCK | 5 | ❌ |
| LoRa(**SX1276**) MISO  | 19 | ❌ |
| LoRa(**SX1276**) MOSI  | 27 | ❌ |
| LoRa(**SX1276**) RESET | 23 | ❌ |
| LoRa(**SX1276**) DIO1  | 33 | ❌ |
| LoRa(**SX1276**) DIO2  | 32 | ❌ |
| LoRa(**SX1276**) CS | 18 | ❌ |
| Battery ADC | 35 | ❌ |
| On Board LED | 25 | ❌ |

* **The GPIOs above GPIO33 of the ESP32 chip only allow input functions and cannot be set as output functions.**
* **You need to remove the SD card when uploading the sketch, otherwise it will not be downloaded**

### 🧑🏼‍🔧 I2C Devices Address

| Devices | 7-Bit Address | Share Bus |
| --- | --- | --- |
| OLED Display SSD1306 | 0x3C | ✅️ |

### ⚡ Electrical parameters

| Features | Details |
| --- | --- |
| 🔗USB-C Input Voltage | 5V |
| ⚡Charge Current | 500mA |
| 🔋Battery Voltage | 3.7V |

### Button Description

| Channel | Peripherals  |
| --- | --- |
| RST | Reset button |

### LED Description

* CHG LED

| LED State | Details |
| --- | --- |
| On | Battery charging |
| Off | Battery Full |
| Blink | Battery not connected |

* User LED

1. The LED is connected to ESP32 GPIO25, and the LED is turned on or off by writing a high or low level

### RF parameters

| Features | Details |
| --- | --- |
| RF  Module | SX1276 |
| Frequency range | 840～945MHz |
| Transfer rate(LoRa) | 0.018K～37.5Kbps |
| Transfer rate(FSK)  | 1.2K～300Kbps |
| Modulation | FSK, GFSK, MSK, GMSK, LoRa，OOK |

## LoRa-IPEX

* The following figure shows how to switch the onboard LoRa SMA antenna to IPEX
* Rotate the resistor in the left picture 90° to the left and solder it to the position marked in the red box on the right.

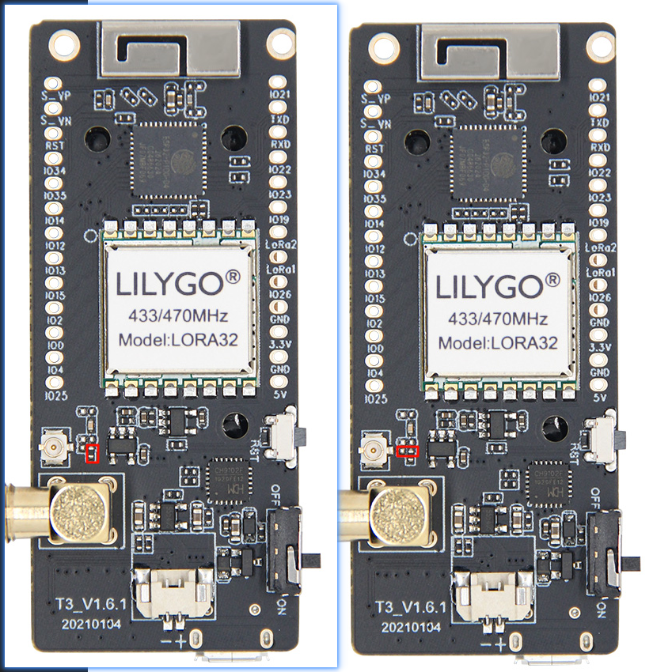
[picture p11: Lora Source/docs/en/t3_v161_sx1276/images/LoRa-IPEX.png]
LORA-IPEX


#### Resource

* [T3_V1.6.1 schematic](../../../schematic/T3_V1.6.1.pdf)
* [SX1276 datasheet](https://www.semtech.com/products/wireless-rf/lora-transceivers/sx1276)

### Application

* [T-Beam Paxcounter](https://github.com/cyberman54/ESP32-Paxcounter)
* [T-Beam Meshtastic](https://github.com/meshtastic/Meshtastic-device)

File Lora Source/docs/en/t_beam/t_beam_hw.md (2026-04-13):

<div align="center" markdown="1">
  LilyGo logo
</div>

<h1 align = "center">🌟LilyGo T-Beam🌟</h1>

## Overview

* This page introduces the hardware parameters related to `LilyGo T-Beam`

### Notes on use

1. Please be sure to connect the antenna before transmitting, otherwise it is easy to damage the RF module

### Product

| Product | SOC | Flash | PSRAM |
| --- | --- | --- | --- |
| [T-Beam Meshtastic][1] | ESP32-D0WDQ6-V3 | 4MB(Quad-SPI) | 8MB(Quad-SPI) |
| [T-Beam SoftRF][2] | ESP32-D0WDQ6-V3 | 4MB(Quad-SPI) | 8MB(Quad-SPI) |

[1]: https://www.lilygo.cc/products/t-beam-v1-1-esp32-lora-module "T-Beam Meshtastic"
[2]: https://www.lilygo.cc/products/t-beam-softrf "T-Beam SoftRF"

### PlatformIO Quick Start

1. Install the **CH9102 USB bridge** driver for the first time.
   * [Windows](https://www.wch-ic.com/downloads/CH343SER_ZIP.html)
   * [Mac OS](https://www.wch-ic.com/downloads/CH34XSER_MAC_ZIP.html)
2. Install [Visual Studio Code](https://code.visualstudio.com/) and [Python](https://www.python.org/)
3. Search for the `PlatformIO` plugin in the `Visual Studio Code` extension and install it.
4. After the installation is complete, you need to restart `Visual Studio Code`
5. After restarting `Visual Studio Code`, select `File` in the upper left corner of `Visual Studio Code` -> `Open Folder` -> select the `LilyGo-LoRa-Series` directory
6. Wait for the installation of third-party dependent libraries to complete
7. Click on the `platformio.ini` file, and in the `platformio` column
8. Select the board name you want to use in `default_envs` and uncomment it.
9. Uncomment one of the lines `src_dir = xxxx` to make sure only one line works , Please note the example comments, indicating what works and what does not.
10. Click the (✔) symbol in the lower left corner to compile
11. Connect the board to the computer USB-C , Micro-USB is used for module firmware upgrade
12. Click (→) to upload firmware
13. Click (plug symbol) to monitor serial output
14. If it cannot be written, or the USB device keeps flashing, please check the **FAQ** below

### Arduino IDE quick start

1. Install the **CH9102 USB bridge** driver for the first time.
   * [Windows](https://www.wch-ic.com/downloads/CH343SER_ZIP.html)
   * [Mac OS](https://www.wch-ic.com/downloads/CH34XSER_MAC_ZIP.html)
2. Install [Arduino IDE](https://www.arduino.cc/en/software)
3. Install [Arduino ESP32](https://docs.espressif.com/projects/arduino-esp32/en/latest/)
4. Copy all folders in the `lib` directory to the `Sketchbook location` directory. How to find the location of your own libraries, [please see here](https://support.arduino.cc/hc/en-us/articles/4415103213714-Find-sketches-libraries-board-cores-and-other-files-on-your-computer)
    * Windows: `C:\Users\{username}\Documents\Arduino`
    * macOS: `/Users/{username}/Documents/Arduino`
    * Linux: `/home/{username}/Arduino`
5. Open the corresponding example
    * Open the downloaded `LilyGo-LoRa-Series`
    * Open `examples`
    * Select the sample file and open the file ending with `ino`
6. On Arduino Select the corresponding board in the IDE tool project and click on the corresponding option in the list below to select

    | Name                                 | Value                                |
    | ------------------------------------ | ------------------------------------ |
    | Board                                | **ESP32 Dev Module**                 |
    | Port                                 | Your port                            |
    | CPU Frequency                        | 240MHZ(WiFi/BT)                      |
    | Core Debug Level                     | None                                 |
    | Erase All Flash Before Sketch Upload | Disable                              |
    | Events Run On                        | Core1                                |
    | Flash Frequency                      | 80MHZ                                |
    | Flash Mode                           | QIO                                  |
    | Flash Size                           | **4MB(32Mb)**                        |
    | JTAG Adapter                         | Disabled                             |
    | Arduino Runs On                      | Core1                                |
    | Partition Scheme                     | **Huge APP (3MB No OTA/1MB SPIFFS)** |
    | PSRAM                                | **Enable**                           |
    | Upload Speed                         | 921600                               |
    | Programmer                           | **Esptool**                          |

6. Please uncomment the `utilities.h` file of each sketch according to your board model ,e.g `T_BEAM_SX1262`,`T_BEAM_SX1276`,`T_BEAM_SX1278`, otherwise the compilation will report an error.
7. Upload sketch

### 📍 Pins Map

| Name | GPIO NUM | Free |
| --- | --- | ---- |
| SDA | 21 | ❌ |
| SCL | 22 | ❌ |
| OLED(**SSD1306**) SDA | Share with I2C bus | ❌ |
| OLED(**SSD1306**) SCL | Share with I2C bus | ❌ |
| GNSS(**Ublox M6/M8**) TX | 12 | ❌ |
| GNSS(**Ublox M6/M8**) RX | 34 | ❌ |
| LoRa(**SX1276/SX1278**) SCK | 5 | ❌ |
| LoRa(**SX1276/SX1278**) MISO  | 19 | ❌ |
| LoRa(**SX1276/SX1278**) MOSI  | 27 | ❌ |
| LoRa(**SX1276/SX1278**) RESET | 23 | ❌ |
| LoRa(**SX1276/SX1278**) DIO1  | 33 | ❌ |
| LoRa(**SX1276/SX1278**) DIO2  | 32 | ❌ |
| LoRa(**SX1276/SX1278**) CS | 18 | ❌ |
| Button1 | 38 | ❌ |
| PMU (**AXP2101**) IRQ | 35 | ❌ |
| PMU (**AXP2101**) SDA | Share with I2C bus | ❌ |
| PMU (**AXP2101**) SCL | Share with I2C bus | ❌ |

### 🧑🏼‍🔧 I2C Devices Address

| Devices | 7-Bit Address | Share Bus |
| --- | --- | --- |
| OLED Display (**SSD1306**)  | 0x3C | ✅️ |
| Power Manager (**AXP2101**) | 0x34 | ❌ |

### ⚡ Electrical parameters

| Features | Details |
| --- | --- |
| 🔗USB-C Input Voltage | 3.9V-6V |
| ⚡Charge Current | 0-1024mA (\(Programmable\)) |
| 🔋Battery Voltage | 3.7V |

### ⚡ PowerManage Channel

| Channel | Peripherals |
| --- | --- |
| DC1 | **ESP32** |
| DC2 | Unused |
| DC3 | Unused |
| DC4 | Unused |
| DC5 | Unused |
| LDO1(VRTC) | Unused |
| ALDO1 | Unused |
| ALDO2 | **Radio** |
| ALDO3 | **GPS** |
| ALDO4 | Unused |
| BLDO1 | Unused |
| BLDO2 | Unused |
| DLDO1 | Unused |
| CPUSLDO | Unused |
| VBACKUP | **GNSS Backup** |

### Button Description

| Channel | Peripherals |
| --- | --- |
| PWR | PMU button, customizable function |
| IO38 | Customizable function |
| RST | Reset button |

* The PWR button is connected to the PMU
  1. In shutdown mode, press the PWR button to turn on the power supply
  2. In power-on mode, press the PWR button for 6 seconds (default time) to turn off the power supply

### LED Description

* CHG LED
  1. If not controlled by the program, the default is always on when charging and off when fully charged
  2. This LED can be controlled by the program

* PPS LED,
  1. The red LED near the GPS module cannot be turned off
  2. This LED cannot be turned off and is connected to the GPS PPS Pin. This LED flashes to indicate that the PPS pulse has arrived.

### RF parameters

| Features | Details |
| --- | --- |
| RF  Module | SX1278/SX1276 |
| Frequency range | 868/915MHz |
| Transfer rate(LoRa) | 0.018 K ～ 62.5 Kbps |
| Transfer rate(FSK)  | 0.6 K ～ 300 Kbps |
| Modulation | FSK, GFSK, MSK, GMSK, LoRa,OOK |

## WiFi-IPEX

* The following figure shows how to switch the onboard WIFI antenna to IPEX

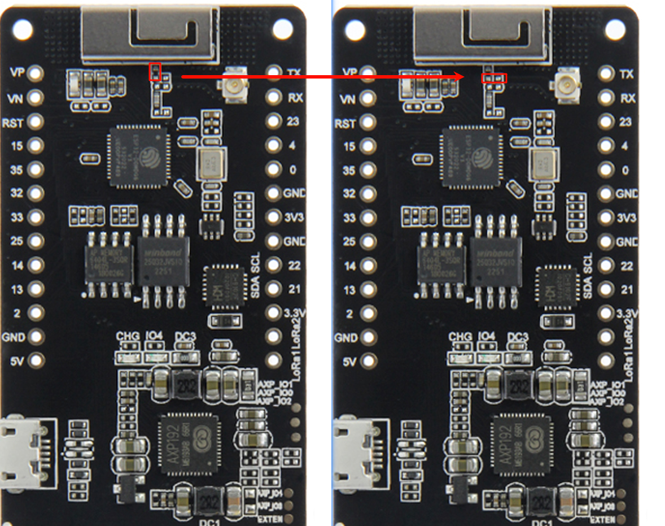
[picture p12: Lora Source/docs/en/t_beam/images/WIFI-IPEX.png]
WIFI-IPEX


### Resource

* [Schematic](../../../schematic/LilyGo_TBeam_V1.2.pdf)
* [AXP2101 datasheet](http://www.x-powers.com/en.php/Info/product_detail/article_id/95)
<!-- * [AXP192 datasheet](http://www.x-powers.com/en.php/Info/product_detail/article_id/29) -->
* [SX1262 datasheet](https://www.semtech.com/products/wireless-rf/lora-transceivers/sx1262)
* [SX1278 datasheet](https://www.semtech.com/products/wireless-rf/lora-transceivers/sx1278)
* [SX1276 datasheet](https://www.semtech.com/products/wireless-rf/lora-transceivers/sx1276)
* [SX1262 datasheet](https://www.semtech.com/products/wireless-rf/lora-transceivers/sx1262)
* [GSP NEO-6/NEO-8 datasheet](https://www.u-blox.com/en/product/neo-6-series)

### Application

* [T-Beam SoftRF](https://github.com/lyusupov/SoftRF)
* [T-Beam Paxcounter](https://github.com/cyberman54/ESP32-Paxcounter)
* [T-Beam Meshtastic](https://github.com/meshtastic/Meshtastic-device)

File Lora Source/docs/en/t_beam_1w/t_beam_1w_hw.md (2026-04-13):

<div align="center" markdown="1">
  LilyGo logo
</div>

<h1 align = "center">🌟LilyGo T-Beam-1W🌟</h1>

## Overview

* This page introduces the hardware parameters related to `LilyGo T-Beam-1W`

### Notes on use

1. This board will not charge the external 7.4V battery, it is only powered by the battery.
2. Please be sure to connect the antenna before transmitting, otherwise it is easy to damage the RF module.
3. Please note that the GPIO with * added to the external pin header GPIO name is already connected to the internal module and cannot be used
4. This RF module provides a maximum power output of 32dBm on this board

## PlatformIO Quick Start

1. Install [Visual Studio Code](https://code.visualstudio.com/) and [Python](https://www.python.org/)
2. Search for the `PlatformIO` plugin in the `Visual Studio Code` extension and install it.
3. After the installation is complete, you need to restart `Visual Studio Code`
4. After restarting `Visual Studio Code`, select `File` in the upper left corner of `Visual Studio Code` -> `Open Folder` -> select the `LilyGo-LoRa-Series` directory
5. Wait for the installation of third-party dependent libraries to complete
6. Click on the `platformio.ini` file, and in the `platformio` column
7. Select the board name you want to use in `default_envs` and uncomment it.
8. Uncomment one of the lines `src_dir = xxxx` to make sure only one line works , Please note the example comments, indicating what works and what does not.
9. Click the (✔) symbol in the lower left corner to compile
10. Connect the board to the computer USB-C , Micro-USB is used for module firmware upgrade
11. Click (→) to upload firmware
12. Click (plug symbol) to monitor serial output
13. If it cannot be written, or the USB device keeps flashing, please check the **FAQ** below

## Arduino IDE quick start

1. Install [Arduino IDE](https://www.arduino.cc/en/software)
2. Install [Arduino ESP32](https://docs.espressif.com/projects/arduino-esp32/en/latest/)
3. Copy all folders in the `lib` directory to the `Sketchbook location` directory. How to find the location of your own libraries, [please see here](https://support.arduino.cc/hc/en-us/articles/4415103213714-Find-sketches-libraries-board-cores-and-other-files-on-your-computer)
    * Windows: `C:\Users\{username}\Documents\Arduino`
    * macOS: `/Users/{username}/Documents/Arduino`
    * Linux: `/home/{username}/Arduino`
4. Open the corresponding example
    * Open the downloaded `LilyGo-LoRa-Series`
    * Open `examples`
    * Select the sample file and open the file ending with `ino`
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

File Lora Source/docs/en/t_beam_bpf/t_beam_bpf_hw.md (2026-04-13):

<div align="center" markdown="1">
  LilyGo logo
</div>

<h1 align = "center">🌟LilyGo T-Beam-BPF🌟</h1>

## Overview

* This page introduces the hardware parameters related to `LilyGo T-Beam-BPF`

### Notes on use

1. The device will not be powered when the battery is inserted for the first time, because the onboard BMS is in shipping mode at this time. You need to exit shipping mode and insert the USB-C into the board to activate the device power supply. If the battery is removed and re-inserted, you need to repeat the above steps
2. Please be sure to connect the antenna before transmitting, otherwise it is easy to damage the RF module

## PlatformIO Quick Start

1. Install [Visual Studio Code](https://code.visualstudio.com/) and [Python](https://www.python.org/)
2. Search for the `PlatformIO` plugin in the `Visual Studio Code` extension and install it.
3. After the installation is complete, you need to restart `Visual Studio Code`
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

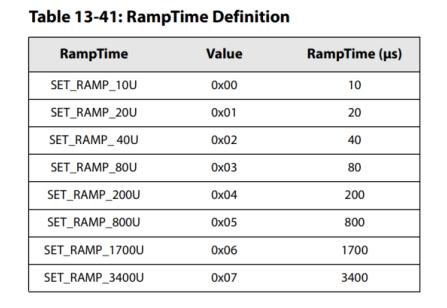
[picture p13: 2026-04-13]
Lora Source/docs/en/t_beam_1w/images/RampTime.jpg

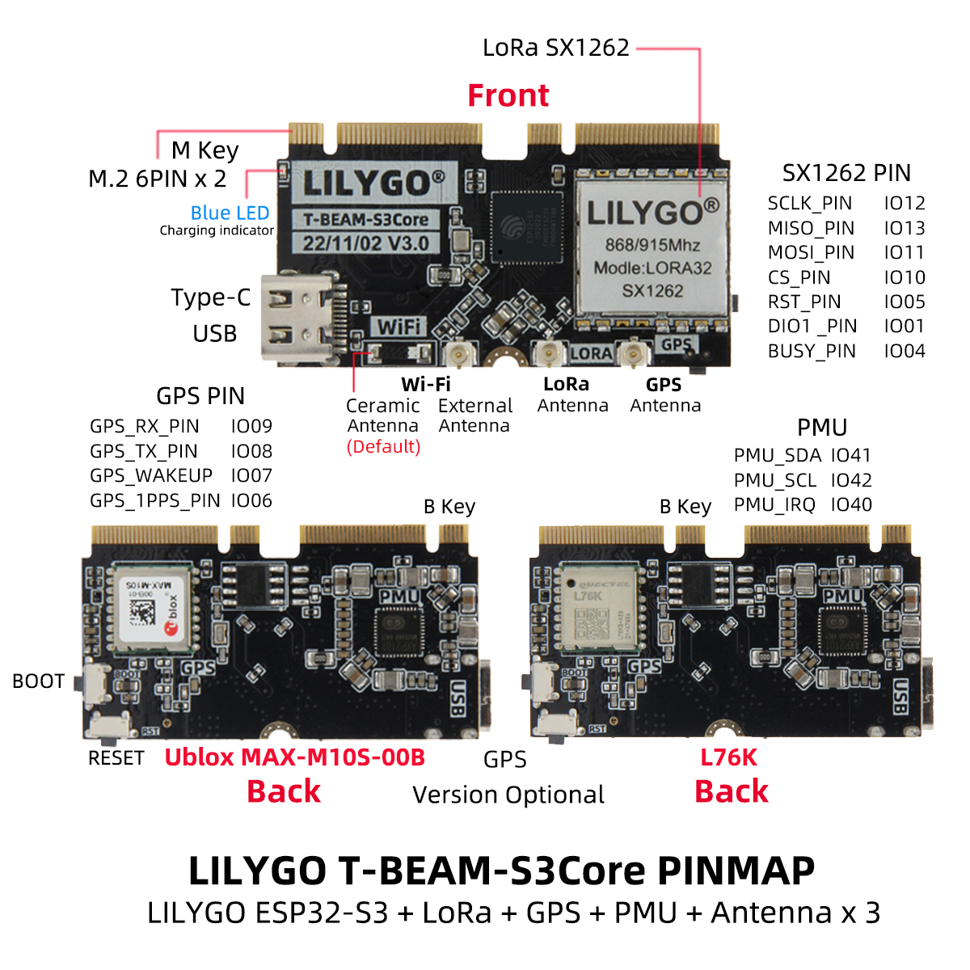
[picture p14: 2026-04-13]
Lora Source/assets/image/T-BEAM-S3Core.jpg

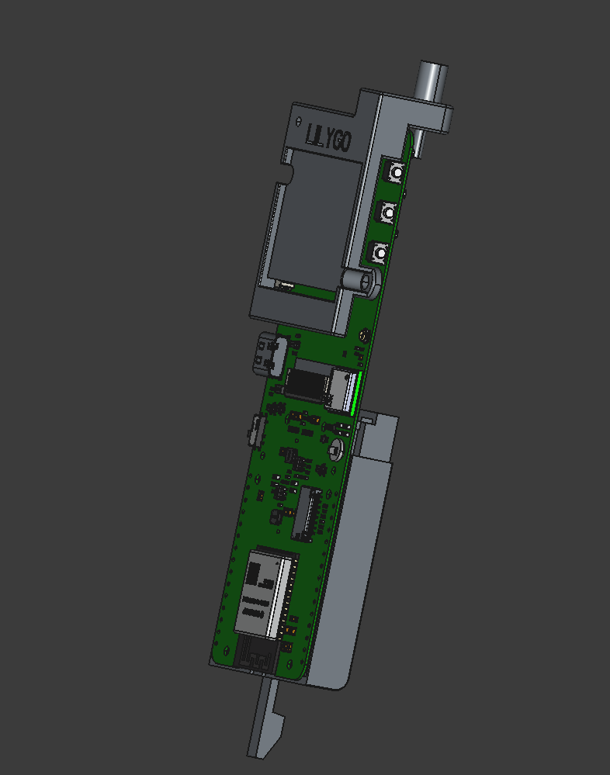
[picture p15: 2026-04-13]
Lora Source/dimensions/images/t-beam-1w.png

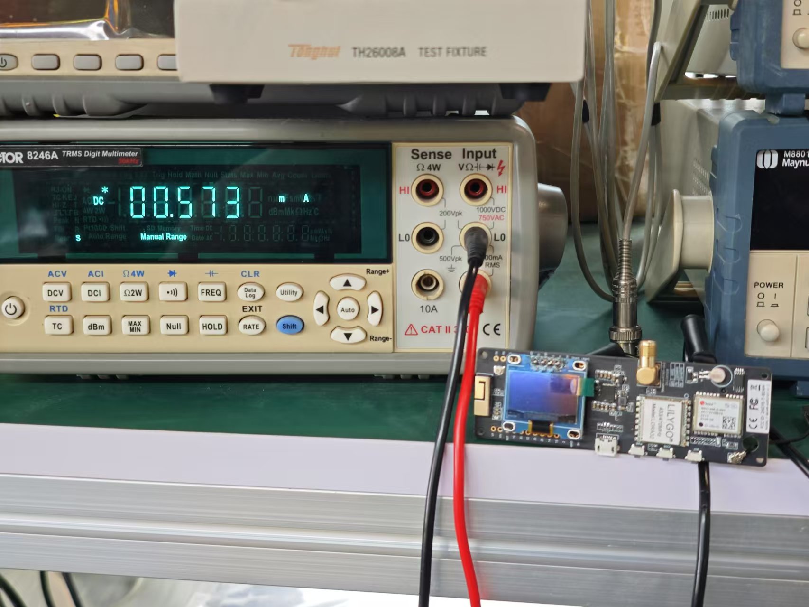
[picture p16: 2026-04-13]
Lora Source/examples/TBeamFactory/images/TIMER_WAKEUP_ADD_GPIO_WAKEUP_ext1_ext0_SLEEP_CUR_Disp.jpg

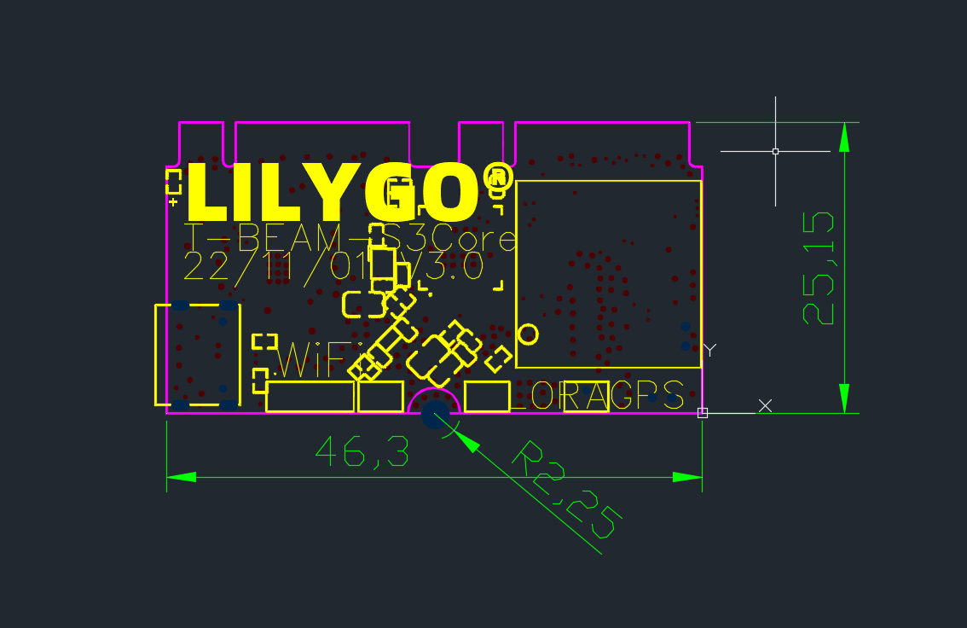
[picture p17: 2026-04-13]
Lora Source/dimensions/images/T-Beam-S3.png

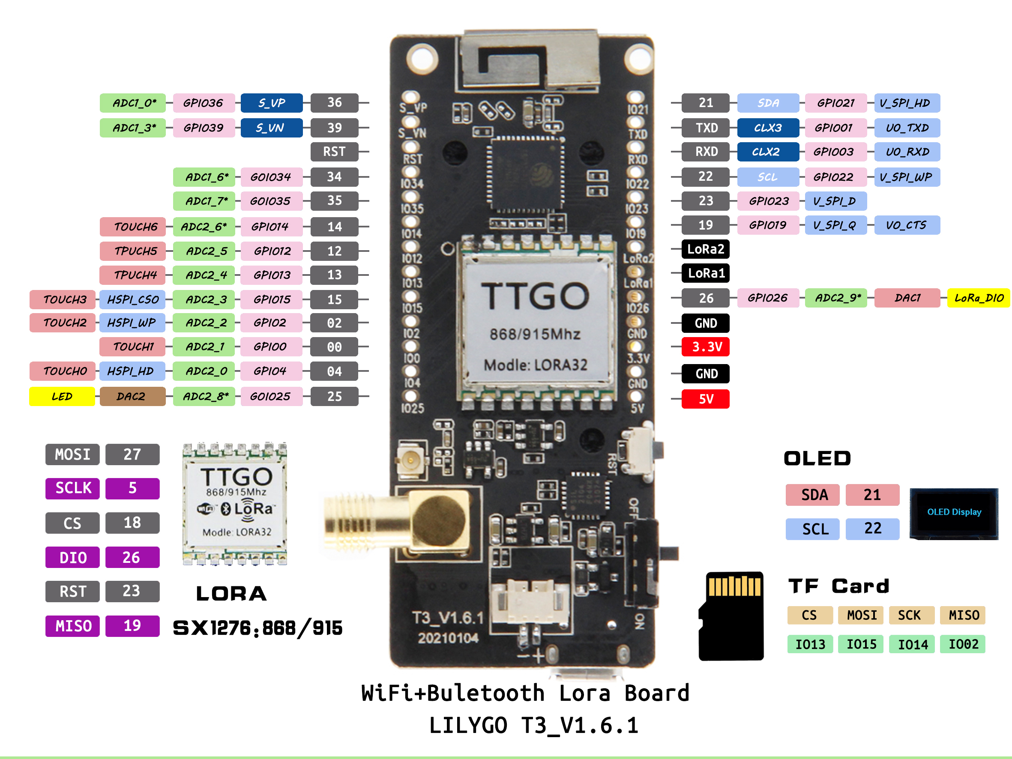
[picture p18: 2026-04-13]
Lora Source/assets/image/lora32_v1.6.1_pinmap.jpg

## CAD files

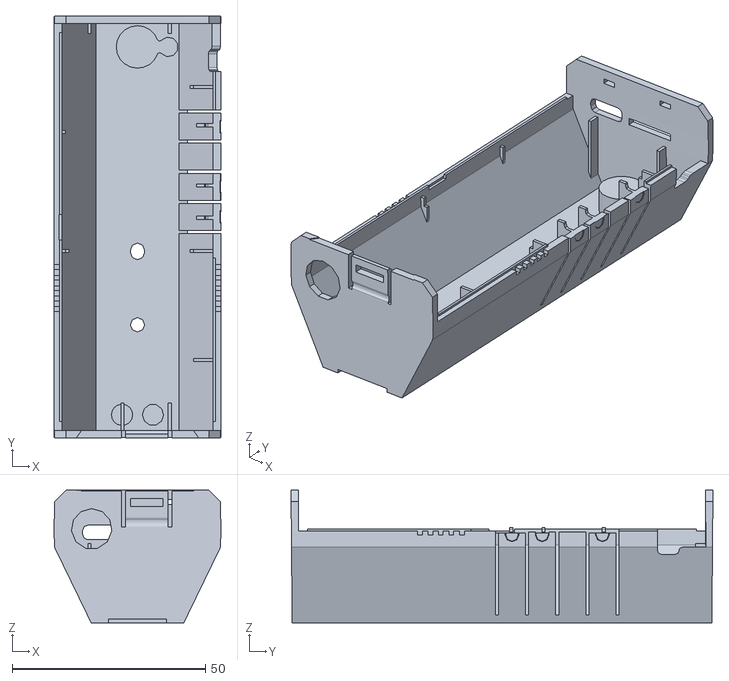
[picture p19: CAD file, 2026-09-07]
cad-reference/T-Beam-Supreme/shell/backshell.stl
43.2 x 109.2 x 34.3

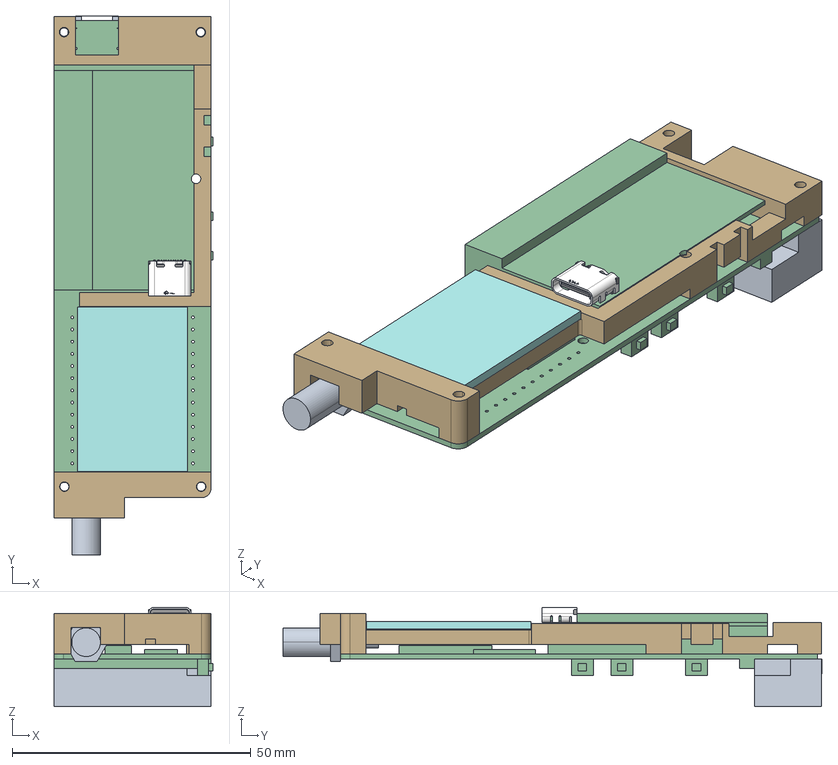
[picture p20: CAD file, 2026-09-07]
cad-reference/T-Beam-Supreme/T-Beam-Supreme-Board.stp
33.3 x 112.9 x 20.8 mm
0-PCB_16_1
0-PMMA_59_1
0-TP_7_1
0-TX_4_1
PRT0001_5_1
PRT0001

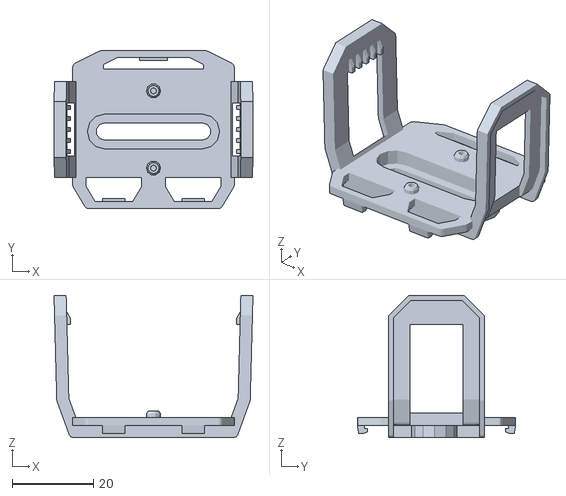
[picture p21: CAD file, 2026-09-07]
cad-reference/T-Beam-Supreme/shell/brackets.stl
49.0 x 39.0 x 35.0

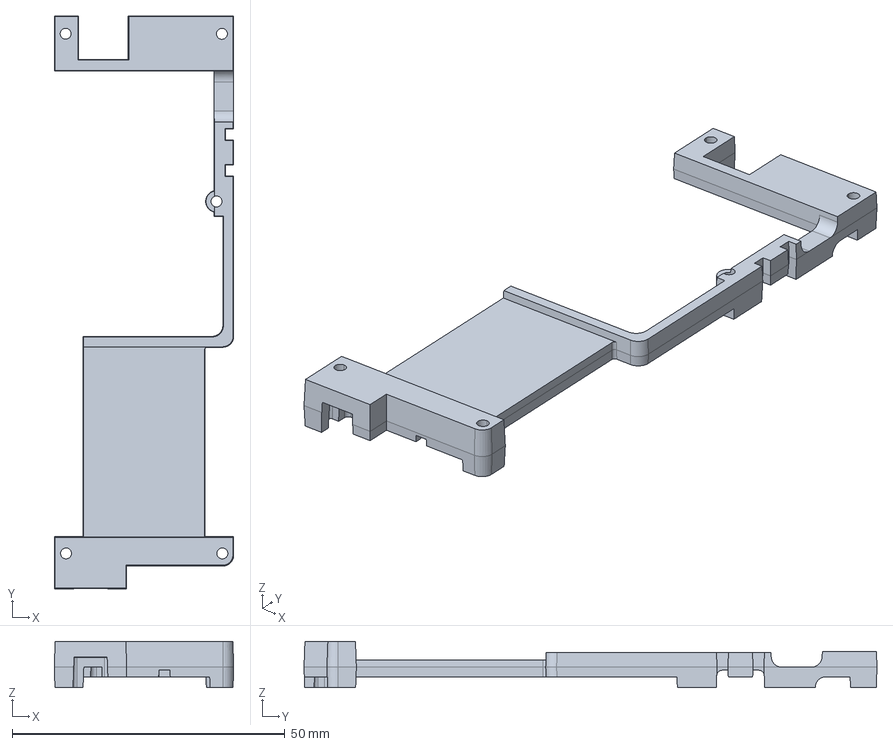
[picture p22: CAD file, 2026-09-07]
cad-reference/T-Beam-Supreme/T-Beam-Supreme-Bracket.stp
32.9 x 105.0 x 8.50 mm

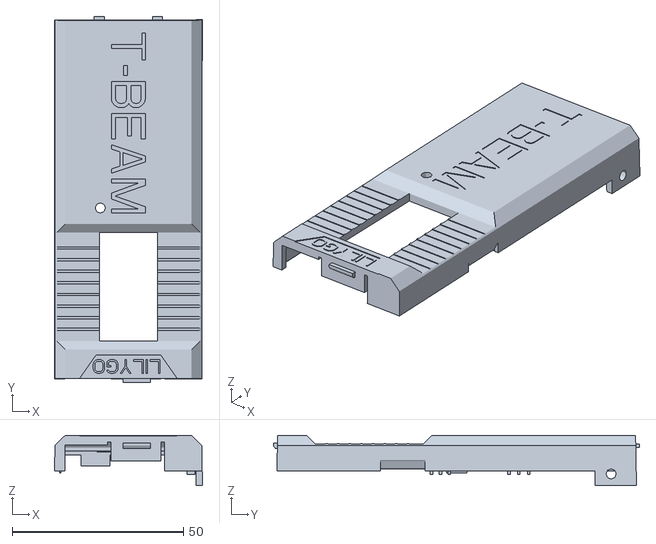
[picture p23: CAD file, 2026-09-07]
cad-reference/T-Beam-Supreme/shell/topside.stl
43.3 x 107.1 x 14.7

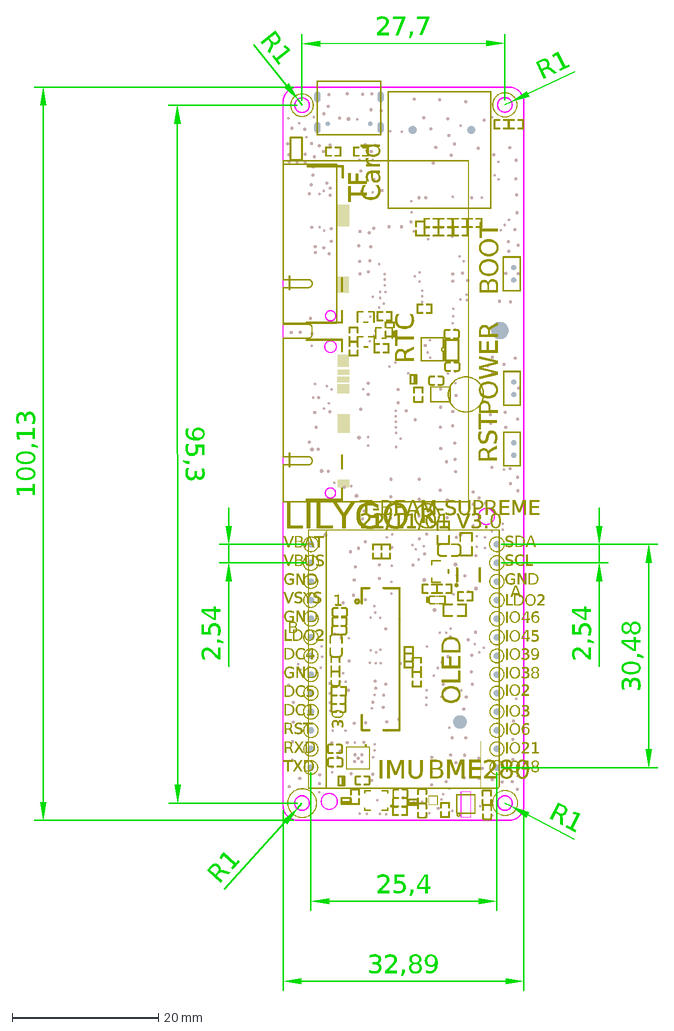
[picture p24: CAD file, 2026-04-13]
cad-reference/T-Beam-Supreme/T-Beam-Supreme-Dimensions.dxf
22/11/01 V3.0
T-BEAM-SUPREME
POWER
RST
BOOT
VBAT
VBUS
GND
VSYS
LDO2
DC4
DC5
DC1
RXD
TXD
SDA
SCL
IO46
IO45
IO39
IO38
IO2
IO3
IO6
IO48
A
B
IO21
LILYGO®
RTC
OLED
IMU
BME280
Card
TF
1
30
27,7
95,3
32,89
100,13
2,54
R1
25,4
30,48

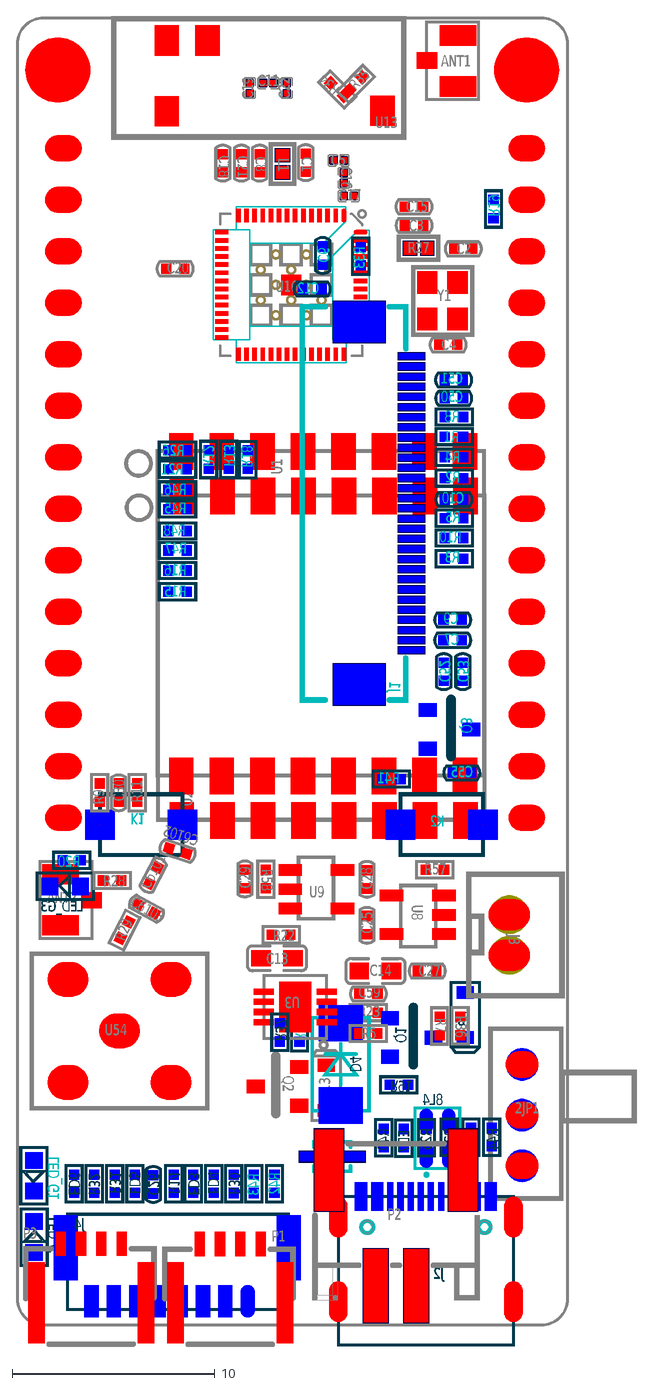
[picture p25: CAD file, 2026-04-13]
Lora Source/dimensions/T3S3 V1.3.dxf
U16
U54
Y1
C8
C6
R27
C20
ED4
ED6
8L4
U13
ANT1
ANT2
ED3
ED5
ED7
ED8
R19
2JP1
U8
U9
J2
C12
C15
C2
C21
C3
R33
U2
U1
LED_G
LED_G3
D13
Q3
J4
ED1
Q2
P1
P3
K1
C13
C14
C52
C10
C1
C6101
C6102
C6103
C25
C26
C27
C28
C29
C30
C50
C51
C55
R10
R11
R17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

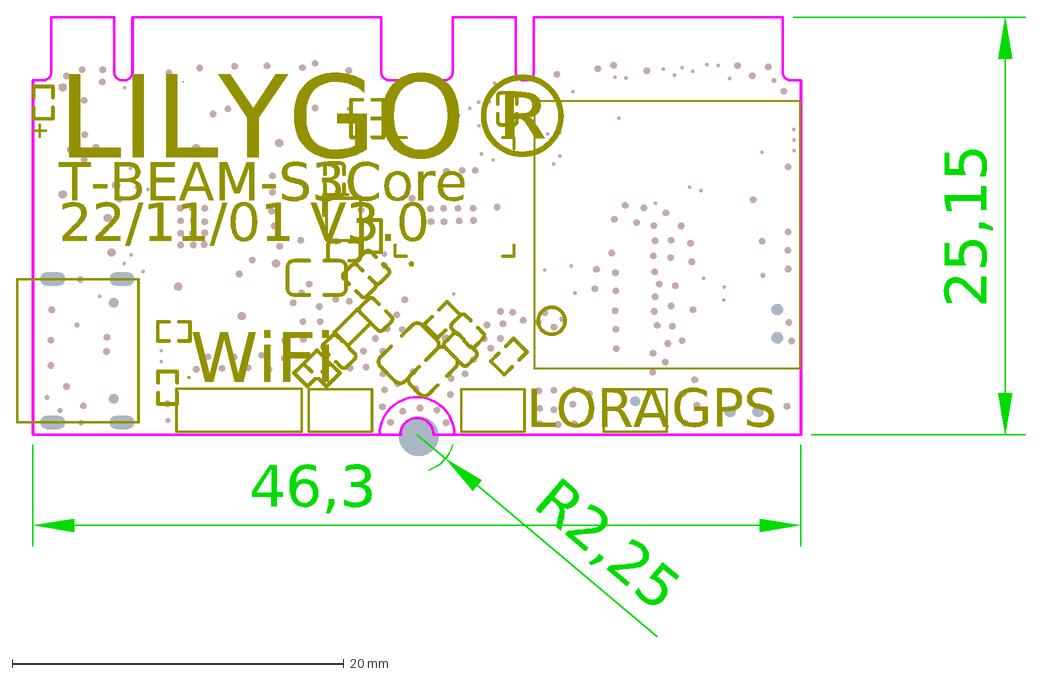
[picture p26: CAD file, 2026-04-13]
Lora Source/dimensions/T-BEAMS3-Core-V3.0.DXF
22/11/01 V3.0
T-BEAM-S3Core
LORA
GPS
WiFi
LILYGO®
+
46,3
25,15
R2,25

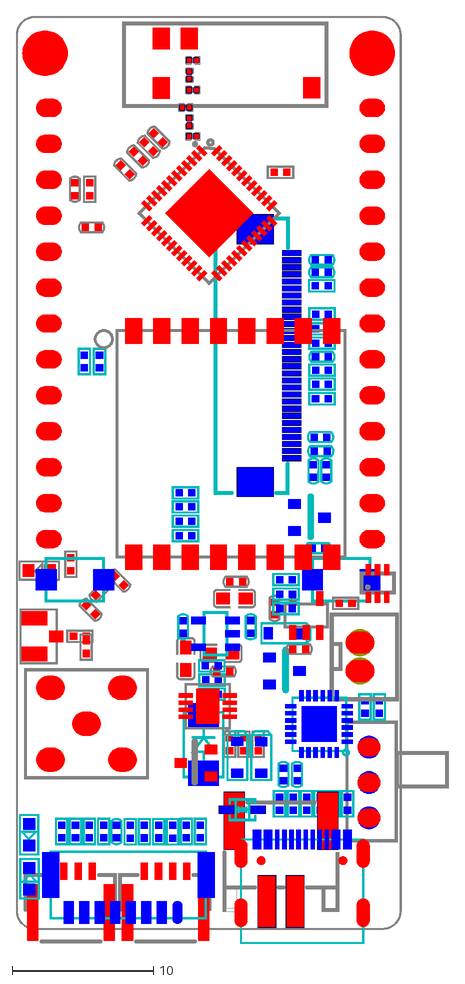
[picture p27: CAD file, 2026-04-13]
Lora Source/dimensions/T3_V3.0_TCXO.dxf
30.6 x 65.6

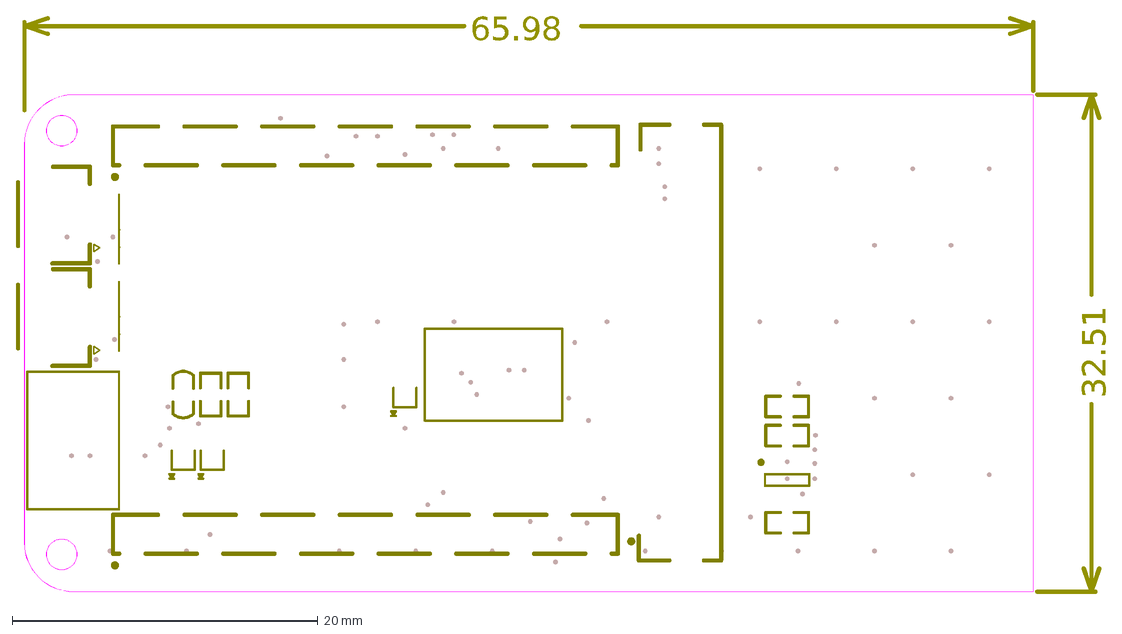
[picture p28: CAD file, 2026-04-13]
Lora Source/dimensions/T-Beam-Shiled-V1.0.dxf
32.51
65.98

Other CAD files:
Lora Source/dimensions/T3_V1.62.dwg
Lora Source/dimensions/T3_V1.3.dwg

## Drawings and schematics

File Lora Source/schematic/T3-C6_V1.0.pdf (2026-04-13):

D

6 | 5 | 4 | 3 | 2 | 1

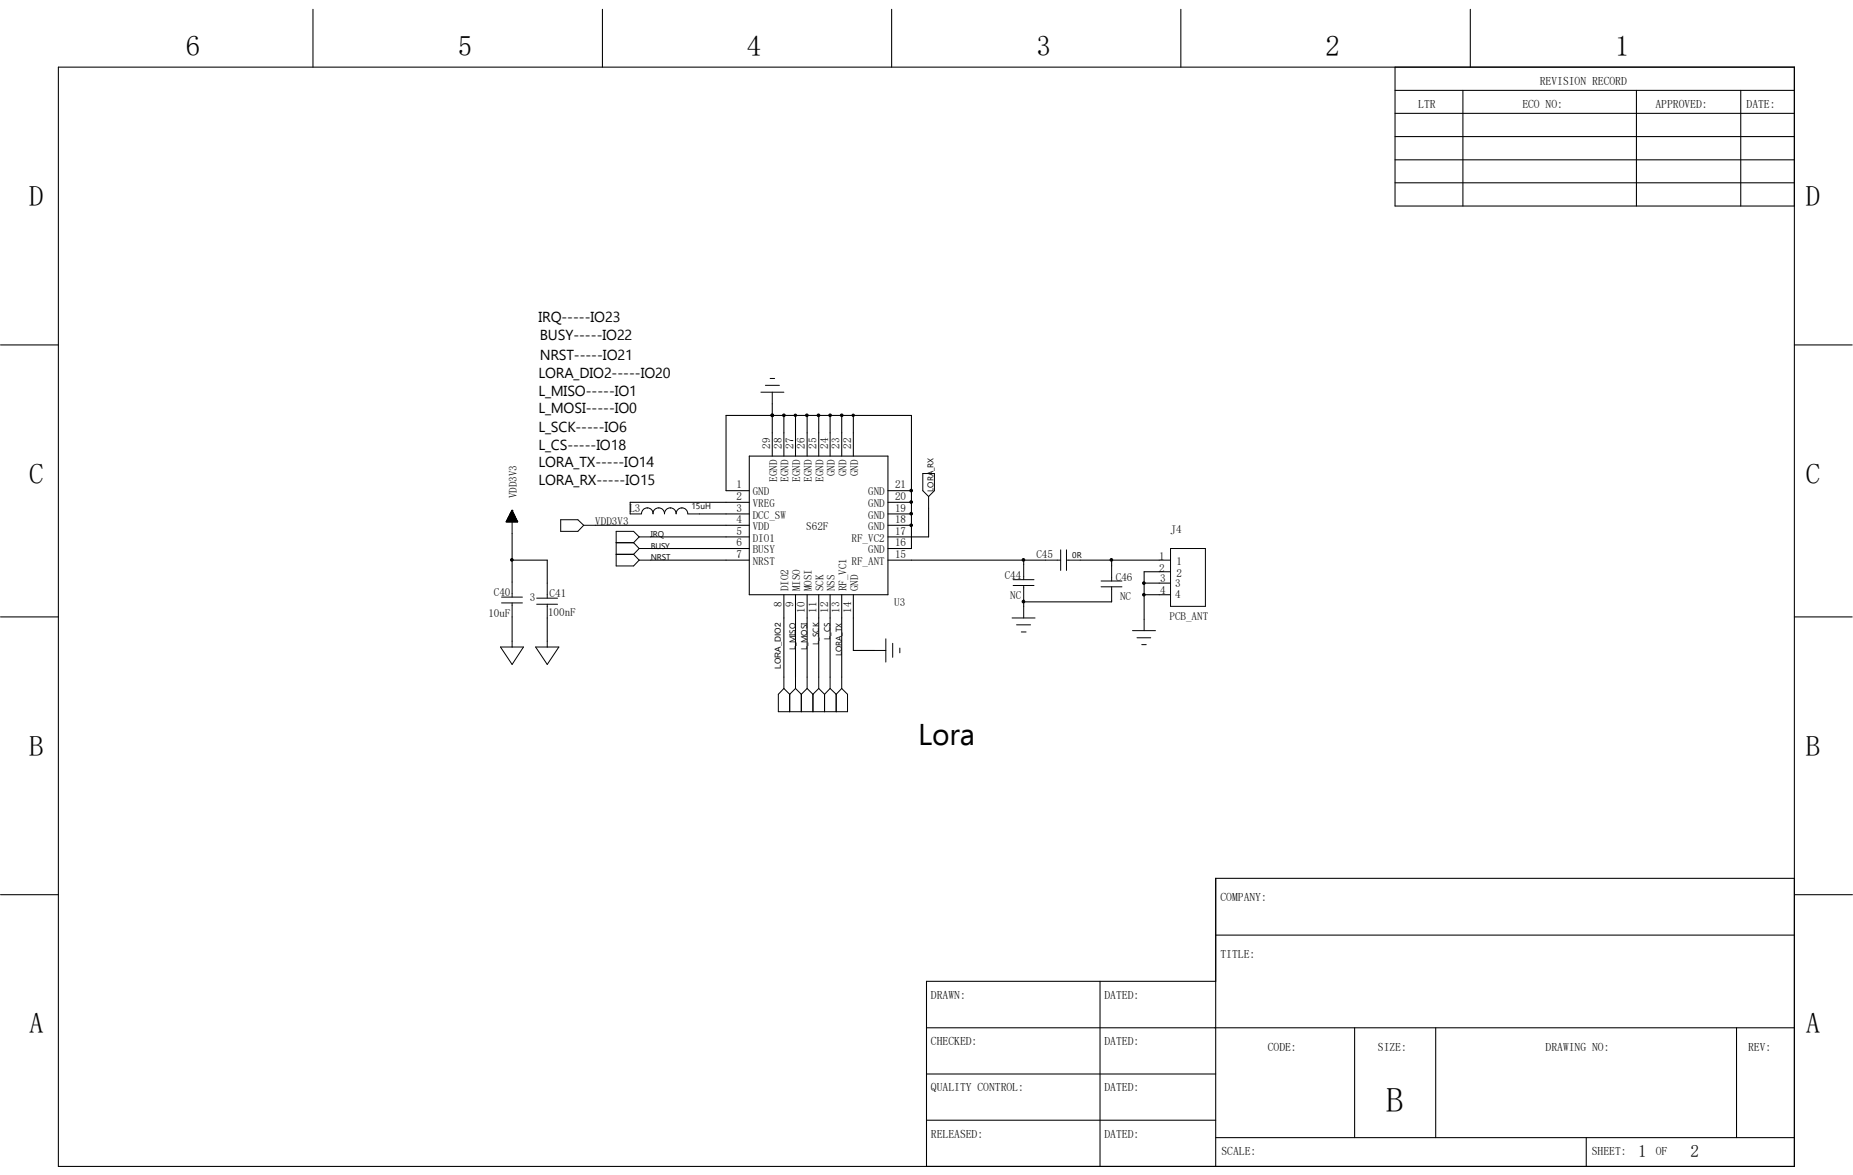
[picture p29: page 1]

REVISION RECORD

LTR | ECO NO: | APPROVED: | DATE:

21 GND ²² GND 23 GND 24 GND 25 EGND 26 EGND 27 EGND 28 EGND 29 EGND

GND 2 VREG 3 | 20 GND
DCC_SW 4 VDD 5 DIO1 6 BUSY 7 | 19 GND

9 MISO 10 MOSI 11 SCK 12 NSS 13 RF_VC1 14 GND

DRAWN: | DATED:
CHECKED: | DATED: | CODE: | SIZE: B | DRAWING NO: | REV:

QUALITY CONTROL: | DATED:

RELEASED: | DATED:

SCALE: | 1 2 SHEET: OF

D

6 | 5 | 4 | 3 | 2 | 1

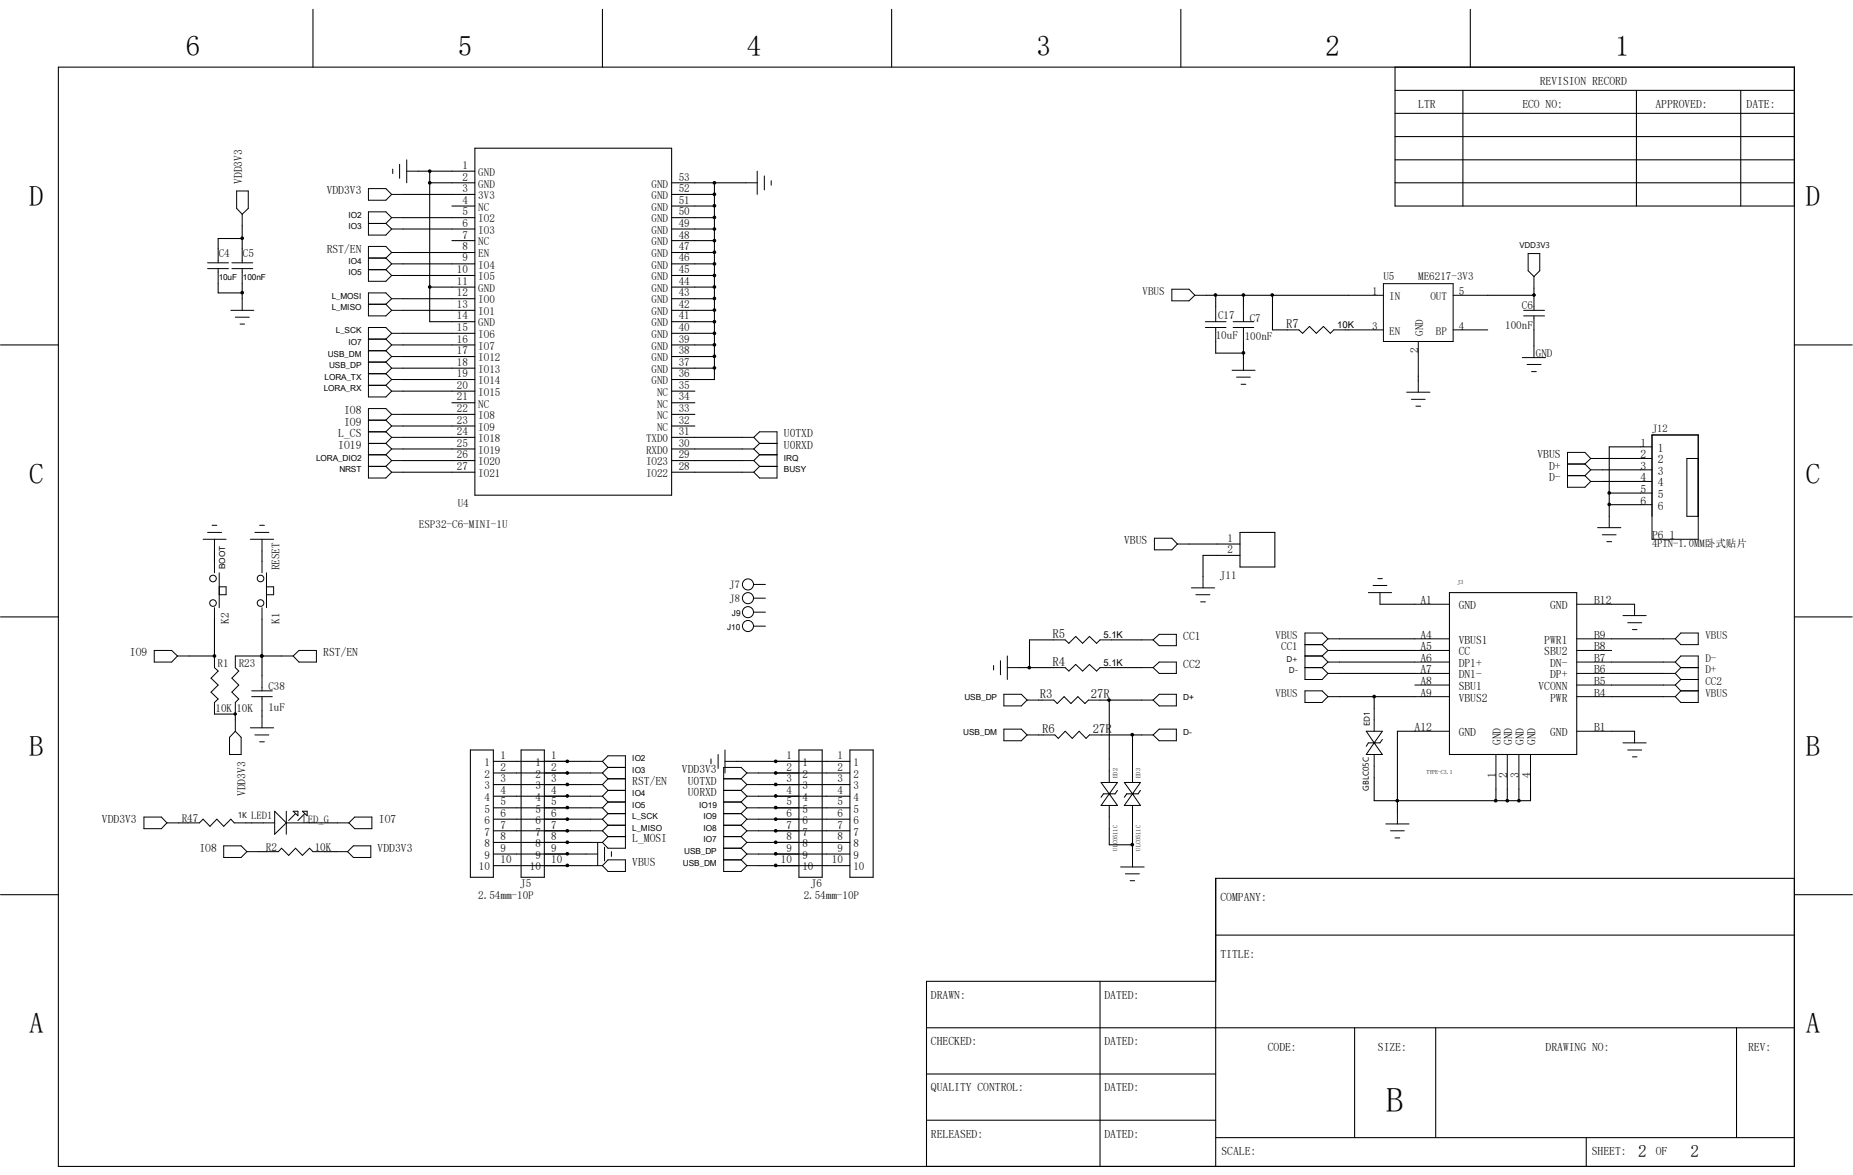
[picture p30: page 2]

REVISION RECORD

LTR | ECO NO: | APPROVED: | DATE:

GND 2 GND 3
3V3 4 NC 5 IO2 6 IO3 7 NC 8 EN 9 | 52 GND

10 10 | | 10 10

DRAWN: | DATED:
CHECKED: | DATED: | CODE: | SIZE: B | DRAWING NO: | REV:

QUALITY CONTROL: | DATED:

RELEASED: | DATED:

SCALE: | 2 2 SHEET: OF

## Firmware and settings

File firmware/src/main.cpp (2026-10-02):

// Hiker's Companion firmware for the LILYGO T-Beam Supreme (ESP32-S3, SX1262, AXP2101, GNSS).
// Sends GPS location over LoRa on an interval, with SOS button, OLED status, and delivery ACK.
// Between sends the LoRa rail is cut and the ESP32 light-sleeps (see loop()). The GPS
// rail follows its own schedule (see GpsMode).

#include <Adafruit_GFX.h>
#include <Adafruit_SH110X.h>
#include <Arduino.h>
#include <SPI.h>
#include <Wire.h>
#include <RadioLib.h>
#include <TinyGPS++.h>
#include <XPowersLib.h>
#include <driver/gpio.h>
#include <esp_sleep.h>

#include "ble_provisioning.h"
#include "hc_crypto.h"
#include "pins.h"

// Bump this alongside the git tag (vX.Y.Z) for each release.
static constexpr char FIRMWARE_VERSION[] = "0.5.0";

// ---- Radio configuration ----
// US902-928 MHz ISM band. SF must match the Heltec receiver. Set per build with
// -DLORA_SF=<7-12> (see the *-sfN envs in platformio.ini); defaults to 10.
#ifndef LORA_SF
#define LORA_SF 10
#endif
static constexpr float LORA_FREQUENCY_MHZ = 915.0;
static constexpr float LORA_BANDWIDTH_KHZ = 125.0;
static constexpr uint8_t LORA_SPREADING_FACTOR = LORA_SF;
static constexpr uint8_t LORA_CODING_RATE = 5;
static constexpr int8_t LORA_TX_POWER_DBM = 22; // SX1262 max

static constexpr uint32_t SEND_INTERVAL_MS = 60000;

// ACK listen window = ACK airtime at the current SF (computed in waitForAck())
// plus this margin for the receiver's decrypt/print/turnaround.
static constexpr uint32_t ACK_TURNAROUND_MARGIN_MS = 750;

// Longest ACK plaintext is "ACK,65535" (message ids are uint16_t).
static constexpr size_t kMaxAckPlainLen = 9;

// GPIO0 has no hardware debounce.
static constexpr uint32_t BUTTON_DEBOUNCE_MS = 50;

// GPS timing. All are placeholders pending real L76K data from the "GPS fix" log lines.
// Wait for a hot start after powering up from backup; a miss drops back to Acquire.
static constexpr uint32_t GPS_HOT_START_BUDGET_MS = 10000;
// Wait when the GPS was already on: long enough to catch a fresh 1 Hz NMEA fix.
static constexpr uint32_t GPS_READ_WINDOW_MS = 3000;
// Stay on this long past the first fix so the full ephemeris downloads.
static constexpr uint32_t GPS_SETTLE_MS = 60000;
// Ephemeris goes stale after ~2-4 h; re-acquire (and re-settle) before then.
static constexpr uint32_t GPS_EPHEMERIS_REFRESH_MS = 2UL * 60 * 60 * 1000;
// No sky (indoors): stop searching after this long, rest, then try again.
static constexpr uint32_t GPS_ACQUIRE_GIVE_UP_MS = 10UL * 60 * 1000;
static constexpr uint32_t GPS_ACQUIRE_REST_MS = 10UL * 60 * 1000;

// The first SOS send after a press gets a short window: getting the alert out beats
// a precise fix. Later SOS sends use the normal windows.
static constexpr uint32_t GPS_ACQUIRE_QUICK_MS = 2000;

// ---- Globals ----
// Must be typed as the interface: the concrete class makes power control protected.
TwoWire PMUWire = TwoWire(1);
XPowersLibInterface *PMU = nullptr;

HardwareSerial &SerialGPS = Serial1;
TinyGPSPlus gps;

SX1262 radio = new Module(RADIO_CS_PIN, RADIO_DIO1_PIN, RADIO_RST_PIN, RADIO_BUSY_PIN);

static constexpr uint8_t DISPLAY_WIDTH = 128;
static constexpr uint8_t DISPLAY_HEIGHT = 64;

// Two board sub-variants put the OLED at 0x3C or 0x3D, so initDisplay() probes both.
static constexpr uint8_t DISPLAY_I2C_ADDR_CANDIDATES[] = {0x3C, 0x3D};
Adafruit_SH1106G display(DISPLAY_WIDTH, DISPLAY_HEIGHT, &Wire, -1);

// If no display ever responds, every display function is a no-op.
bool displayAvailable = false;
uint8_t displayI2cAddr = DISPLAY_I2C_ADDR_CANDIDATES[0];

uint16_t nextMessageId = 0;

// BUTTON_PIN is INPUT_PULLUP: idle-high, pressed-low.
bool lastButtonReading = HIGH;
bool buttonState = HIGH;
uint32_t lastButtonChangeMs = 0;

// A press starts a standing SOS beacon (every send flagged "SOS"); a second press cancels it.
bool sosActive = false;
// Set by an SOS start, cleared once that first SOS packet has been sent.
bool sosFirstSendPending = false;

// The L76K has no built-in power-save mode, so firmware schedules its rail (ALDO4):
//   Acquire: rail stays on, even through light sleep, until a fix.
//   Settle:  stays on GPS_SETTLE_MS past the fix so the full ephemeris downloads.
//   Backup:  rail off between sends. The GNSS backup supply comes straight from the
//            18650, so ephemeris and RTC survive and each send is a hot start.
//            With no 18650 (USB only) every power-up is a cold start.
//   Rest:    rail off after GPS_ACQUIRE_GIVE_UP_MS without a fix.
// SOS follows the same schedule, except it never gives up searching (and wakes Rest).
enum class GpsMode : uint8_t { Acquire, Settle, Backup, Rest };
GpsMode gpsMode = GpsMode::Acquire;
uint32_t gpsModeStartMs = 0;
bool gpsPowered = false;
uint32_t gpsPowerOnMs = 0;
uint32_t gpsEphemerisMs = 0; // when the last Settle finished

static void printHex(const char *label, const uint8_t *data, size_t len) {
    Serial.print(label);
    for (size_t i = 0; i < len; i++) {
        Serial.printf("%02x", data[i]);
    }
    Serial.println();
}

static void haltWithError(const char *message) {
    Serial.println(message);
    while (true) {
        delay(1000);
    }
}

// LoRa, GPS, and the display sit behind AXP2101 rails ALDO3/ALDO4/ALDO1, all off at boot.
// Missing ALDO1 was the cause of a "dead" display: the controller still ACKs I2C
// unpowered, so display.begin() succeeded but nothing lit up.
static void initPower() {
    PMUWire.begin(PMU_SDA, PMU_SCL);

    PMU = new XPowersAXP2101(PMUWire);
    if (!PMU->init()) {
        haltWithError("PMU init failed - check I2C wiring to AXP2101");
    }

    PMU->setPowerChannelVoltage(XPOWERS_ALDO3, 3300); // LoRa rail
    PMU->enablePowerOutput(XPOWERS_ALDO3);

    PMU->setPowerChannelVoltage(XPOWERS_ALDO4, 3300); // GPS rail
    PMU->enablePowerOutput(XPOWERS_ALDO4);

    PMU->setPowerChannelVoltage(XPOWERS_ALDO1, 3300); // Display (+ BME280 + magnetometer) rail
    PMU->enablePowerOutput(XPOWERS_ALDO1);

    // Needed for the battery percentage to read correctly.
    PMU->enableBattDetection();
    PMU->enableBattVoltageMeasure();

    // The PWR button is the AXP2101 power key, reported by PMU_IRQ_PIN going low.
    // Only its IRQs are enabled. The long-press IRQ fires after ~2s and the
    // firmware then calls PMU->shutdown(). Holding for the full 4s also powers
    // off in hardware, as a backstop if the firmware is hung.
    PMU->disableIRQ(XPOWERS_AXP2101_ALL_IRQ);
    PMU->clearIrqStatus();
    PMU->enableIRQ(XPOWERS_AXP2101_PKEY_SHORT_IRQ | XPOWERS_AXP2101_PKEY_LONG_IRQ);
    PMU->setPowerKeyPressOffTime(XPOWERS_POWEROFF_4S);
    // Only on the concrete class; PMU is always created as XPowersAXP2101 above.
    static_cast<XPowersAXP2101 *>(PMU)->setLongPressPowerOFF();
    static_cast<XPowersAXP2101 *>(PMU)->enableLongPressShutdown();
    pinMode(PMU_IRQ_PIN, INPUT_PULLUP);
}

static void initGPS() {
    pinMode(GPS_EN_PIN, OUTPUT);
    digitalWrite(GPS_EN_PIN, HIGH);
    SerialGPS.begin(GPS_BAUD_RATE, SERIAL_8N1, GPS_RX_PIN, GPS_TX_PIN);
}

// Non-fatal: GPS/LoRa/SOS must keep working with a dead display.
static void initDisplay() {
    Wire.begin(I2C_SDA, I2C_SCL);
    for (uint8_t addr : DISPLAY_I2C_ADDR_CANDIDATES) {
        if (display.begin(addr, true)) {
            displayI2cAddr = addr;
            displayAvailable = true;
            display.clearDisplay();
            display.display();
            return;
        }
    }
    Serial.println("Display init failed at 0x3C and 0x3D - continuing without it");
}

// The panel stays off between sends; it wakes for a send and holds through the result.
static constexpr uint32_t DISPLAY_HOLD_MS = 5000;
bool displayOn = false;

static void displayWake() {
    if (!displayAvailable) {
        return;
    }
    if (!displayOn) {
        display.oled_command(SH110X_DISPLAYON);
        displayOn = true;
    }
}

// The ESP32's I2C state doesn't reliably survive light sleep, so the bus and
// controller are re-initialized before each cycle's draw. Non-fatal on failure.
static void reinitDisplay() {
    if (!displayAvailable) {
        return;
    }
    Wire.begin(I2C_SDA, I2C_SCL);
    if (display.begin(displayI2cAddr, true)) {
        displayOn = true; // begin() leaves the OLED on
    } else {
        Serial.println("  display re-init failed, continuing without it");
    }
}

static void displaySleep() {
    if (!displayAvailable) {
        return;
    }
    if (displayOn) {
        display.oled_command(SH110X_DISPLAYOFF);
        displayOn = false;
    }
}

// "Bat 87% CHG" while charging, "Bat 87% USB" if plugged in but not charging
// (full), "Bat 87%" on battery alone, or "No battery".
static void batteryLine(char *out, size_t size) {
    if (!PMU->isBatteryConnect()) {
        snprintf(out, size, "No battery");
        return;
    }
    const char *state = PMU->isCharging() ? " CHG" : (PMU->isVbusIn() ? " USB" : "");
    snprintf(out, size, "Bat %d%%%s", PMU->getBatteryPercent(), state);
}

// line1 is small context (message type); line2 is the big status word; the
// bottom line is battery status.
static void showStatus(const char *line1, const char *line2) {
    if (!displayAvailable) {
        return;
    }
    char battery[24];
    batteryLine(battery, sizeof(battery));

    display.clearDisplay();
    display.setTextColor(SH110X_WHITE);

    display.setTextSize(1);
    display.setCursor(0, 0);
    display.print(line1);

    display.setTextSize(2);
    display.setCursor(0, 20);
    display.print(line2);

    display.setTextSize(1);
    display.setCursor(0, 52);
    display.print(battery);

    display.display();
}

static void initRadio() {
    SPI.begin(RADIO_SCLK_PIN, RADIO_MISO_PIN, RADIO_MOSI_PIN, RADIO_CS_PIN);

    int state = radio.begin();
    if (state != RADIOLIB_ERR_NONE) {
        Serial.printf("Radio init failed, code %d\n", state);
        haltWithError("Halting.");
    }

    radio.setFrequency(LORA_FREQUENCY_MHZ);
    radio.setBandwidth(LORA_BANDWIDTH_KHZ);
    radio.setSpreadingFactor(LORA_SPREADING_FACTOR);
    radio.setCodingRate(LORA_CODING_RATE);
    radio.setOutputPower(LORA_TX_POWER_DBM);
}

// The GPS and LoRa rails are cut whenever they have nothing to do.
static void gpsRailDown() {
    digitalWrite(GPS_EN_PIN, LOW); // don't drive EN into an unpowered chip
    PMU->disablePowerOutput(XPOWERS_ALDO4);
    gpsPowered = false;
    Serial.println("  GPS rail down (backup supply keeps ephemeris)");
}

static void radioRailDown() {
    PMU->disablePowerOutput(XPOWERS_ALDO3);
}

// Both chips lose all state when their rail is cut, so bringing a rail up means a
// full re-init. The 10ms delay is an unmeasured placeholder for rail ramp-up.
static void gpsRailUp() {
    PMU->setPowerChannelVoltage(XPOWERS_ALDO4, 3300);
    PMU->enablePowerOutput(XPOWERS_ALDO4);
    delay(10);
    initGPS();
    gpsPowered = true;
    gpsPowerOnMs = millis();
    Serial.println("  GPS rail up");
}

static void radioRailUp() {
    PMU->setPowerChannelVoltage(XPOWERS_ALDO3, 3300);
    PMU->enablePowerOutput(XPOWERS_ALDO3);
    delay(10);
    initRadio();
}

// Debounced SOS button: true once per confirmed press.
static bool buttonPressed() {
    bool reading = digitalRead(BUTTON_PIN);
    if (reading != lastButtonReading) {
        lastButtonChangeMs = millis();
        lastButtonReading = reading;
    }

    if (millis() - lastButtonChangeMs > BUTTON_DEBOUNCE_MS && reading != buttonState) {
        buttonState = reading;
        return buttonState == LOW;
    }
    return false;
}

static void handleButtonPress() {
    sosActive = !sosActive;
    sosFirstSendPending = sosActive;
    Serial.println(sosActive ? "SOS button pressed - beacon started" : "SOS button pressed - beacon canceled");
}

// Light-sleeps for durationMs, or until the SOS or PWR button is pressed.
static void lightSleepMs(uint32_t durationMs) {
#ifdef DEBUG_NO_SLEEP
    // Debug build: light sleep suspends USB serial, so stay awake and poll
    // instead. Polls through buttonPressed()/handleButtonPress() rather than a
    // raw digitalRead, so SOS debounce state stays in sync with the rest of the
    // firmware -- a raw read here let a press start and end entirely inside this
    // wait without buttonPressed() ever seeing it, which could silently swallow
    // a tap depending on exactly when the next real buttonPressed() call landed.
    uint32_t start = millis();
    while (millis() - start < durationMs) {
        if (buttonPressed()) {
            handleButtonPress();
            return;
        }
        if (digitalRead(PMU_IRQ_PIN) == LOW) {
            return;
        }
        delay(10);
    }
    return;
#endif
    esp_sleep_enable_timer_wakeup((uint64_t)durationMs * 1000ULL);

    gpio_wakeup_enable((gpio_num_t)BUTTON_PIN, GPIO_INTR_LOW_LEVEL);
    gpio_wakeup_enable((gpio_num_t)PMU_IRQ_PIN, GPIO_INTR_LOW_LEVEL);
    esp_sleep_enable_gpio_wakeup();

    esp_light_sleep_start();

    gpio_wakeup_disable((gpio_num_t)BUTTON_PIN);
    gpio_wakeup_disable((gpio_num_t)PMU_IRQ_PIN);
}

static void holdDisplayThenSleep() {
    lightSleepMs(DISPLAY_HOLD_MS);
    displaySleep();
}

// PMU_IRQ_PIN only goes low for a PWR press (see initPower()), already qualified
// by the AXP2101, so no debounce. clearIrqStatus() must run or the pin stays low.
// A long press can't be aborted, so it shows "Power Off" and parks until the PMU
// cuts power; that applies even while SOS is active.
static bool bluetoothButtonPressed() {
    if (digitalRead(PMU_IRQ_PIN) != LOW) {
        return false;
    }
    PMU->getIrqStatus();
    bool shortPress = PMU->isPekeyShortPressIrq();
    bool longPress = PMU->isPekeyLongPressIrq();
    PMU->clearIrqStatus();

    if (longPress) {
        Serial.println("PWR long-press - shutting down");
        reinitDisplay();
        showStatus("Power", "Off");
        delay(1500); // long enough to read the message
        displaySleep();
        Serial.flush();
        PMU->shutdown(); // cuts every rail, ESP32 included; a PWR press turns it back on
        while (true) {
            delay(100);
        }
    }
    return shortPress;
}

// PWR short press enters BLE provisioning, on a different button from SOS on
// purpose. It's ignored while SOS is active: provisioning can block for minutes
// and the beacon must keep sending. Never returns if it enters.
static void checkBluetoothButton() {
    if (!bluetoothButtonPressed()) {
        return;
    }
    if (sosActive) {
        Serial.println("PWR button pressed - ignored, SOS beacon is active");
        return;
    }
    Serial.println("PWR button pressed - entering BLE provisioning");
    runProvisioningMode();
}

// "lat,lng,hdop,age_ms", or "NOFIX,age_ms" if there's no fix yet.
static String buildLocationMessage() {
    if (!gps.location.isValid()) {
        return "NOFIX," + String(gps.location.age());
    }

    String message;
    message += String(gps.location.lat(), 6);
    message += ",";
    message += String(gps.location.lng(), 6);
    message += ",";
    message += String(gps.hdop.hdop(), 1);
    message += ",";
    message += String(gps.location.age());
    return message;
}

// Waits for "ACK,<expectedId>" for the longest ACK's airtime at this SF plus
// ACK_TURNAROUND_MARGIN_MS. radio.receive() blocks and reads the packet itself.
static bool waitForAck(uint16_t expectedId) {
    static constexpr size_t kMaxAckCipherLen = 64;
    uint8_t ackCipherBuf[kMaxAckCipherLen];

    size_t maxAckOnAirBytes = kMaxAckPlainLen + HC_GCM_NONCE_LEN + HC_GCM_TAG_LEN;
    uint32_t ackAirtimeMs = (uint32_t)(radio.getTimeOnAir(maxAckOnAirBytes) / 1000);
    uint32_t ackTimeoutMs = ackAirtimeMs + ACK_TURNAROUND_MARGIN_MS;
    Serial.printf("  ACK window %u ms (ACK airtime %u ms + %u ms margin)\n",
                  (unsigned)ackTimeoutMs, (unsigned)ackAirtimeMs, (unsigned)ACK_TURNAROUND_MARGIN_MS);

    int state = radio.receive(ackCipherBuf, kMaxAckCipherLen, ackTimeoutMs);
    if (state != RADIOLIB_ERR_NONE) {
        Serial.println("  no ACK received");
        return false;
    }

    size_t ackCipherLen = radio.getPacketLength();
    uint8_t ackPlainBuf[kMaxAckCipherLen];
    size_t ackPlainLen = hcDecrypt(ackCipherBuf, ackCipherLen, ackPlainBuf);
    if (ackPlainLen == 0) {
        Serial.println("  ACK decrypt/auth failed");
        return false;
    }

    char ackStr[32];
    size_t copyLen = ackPlainLen < sizeof(ackStr) - 1 ? ackPlainLen : sizeof(ackStr) - 1;
    memcpy(ackStr, ackPlainBuf, copyLen);
    ackStr[copyLen] = '\0';

    int ackId = -1;
    if (sscanf(ackStr, "ACK,%d", &ackId) == 1 && ackId == expectedId) {
        Serial.printf("  ACK received for id %d\n", ackId);
        return true;
    }

    Serial.printf("  ACK mismatch or malformed: %s\n", ackStr);
    return false;
}

// Sends an encrypted "<type>,<id>,<location>[,<contacts>]" packet. Type is "OK"
// or "SOS"; id lets waitForAck() match the reply. Contacts ride on every SOS send
// so any single packet is enough; they're dropped if too long, since the
// location must never fail to send.
static void sendLocationPacket(const char *type) {
    reinitDisplay();
    showStatus(type, "Sending...");

    char battery[24];
    batteryLine(battery, sizeof(battery));
    Serial.printf("  battery: %s\n", battery);

    uint16_t msgId = nextMessageId++;
    String payload = String(type) + "," + String(msgId) + "," + buildLocationMessage();

    static constexpr size_t kMaxPlaintextLen = 160;

    if (sosActive) {
        String withContacts = payload + "," + buildContactsForSos();
        if (withContacts.length() <= kMaxPlaintextLen) {
            payload = withContacts;
        } else {
            Serial.println("  contacts too long to fit with location, sending location only");
        }
    }

    Serial.print("TX (plaintext): ");
    Serial.println(payload);

    uint8_t plainBuf[kMaxPlaintextLen];
    size_t plainLen = payload.length();
    if (plainLen > kMaxPlaintextLen) {
        Serial.println("  payload too long for crypto buffer, dropping");
        showStatus(type, "Send failed");
        holdDisplayThenSleep();
        return;
    }
    memcpy(plainBuf, payload.c_str(), plainLen);

    uint8_t cipherBuf[kMaxPlaintextLen + HC_GCM_NONCE_LEN + HC_GCM_TAG_LEN];
    size_t cipherLen = hcEncrypt(plainBuf, plainLen, cipherBuf);
    if (cipherLen == 0) {
        Serial.println("  encrypt failed");
        showStatus(type, "Send failed");
        holdDisplayThenSleep();
        return;
    }
    printHex("TX (over-the-air bytes): ", cipherBuf, cipherLen);

    int state = radio.transmit(cipherBuf, cipherLen);
    if (state == RADIOLIB_ERR_NONE) {
        Serial.println("  sent ok, waiting for ACK...");
        if (waitForAck(msgId)) {
            showStatus(type, "Delivered");
        } else {
            showStatus(type, "No ACK");
        }
    } else {
        Serial.printf("  send failed, code %d\n", state);
        showStatus(type, "Send failed");
    }
    holdDisplayThenSleep();
}

static bool hasFreshFix() {
    return gps.location.isValid() && gps.location.age() < 2000;
}

// Feeds GPS bytes to the parser until a fresh fix or budgetMs; true on a fresh fix.
// On timeout, buildLocationMessage() uses whatever fix TinyGPSPlus still has.
static bool acquireGpsFix(uint32_t budgetMs) {
    // Drop bytes buffered before light sleep: parsed now, they'd look fresh.
    while (SerialGPS.available() > 0) {
        SerialGPS.read();
    }
    uint32_t start = millis();
    while (millis() - start < budgetMs) {
        while (SerialGPS.available() > 0) {
            gps.encode(SerialGPS.read());
        }
        if (hasFreshFix()) {
            return true;
        }
        if (buttonPressed()) {
            handleButtonPress();
            return false; // don't make SOS wait out the budget
        }
        checkBluetoothButton(); // never returns if it enters provisioning
    }
    return false;
}

static const char *gpsModeName(GpsMode mode) {
    switch (mode) {
    case GpsMode::Acquire: return "acquire";
    case GpsMode::Settle: return "settle";
    case GpsMode::Backup: return "backup";
    case GpsMode::Rest: return "rest";
    }
    return "?";
}

static void enterGpsMode(GpsMode mode) {
    Serial.printf("  GPS mode %s -> %s\n", gpsModeName(gpsMode), gpsModeName(mode));
    gpsMode = mode;
    gpsModeStartMs = millis();
}

// Start of a cycle: applies time-based mode changes, powers the GPS if this cycle
// reads it, and returns how long to wait for a fix (0 = skip, GPS resting).
static uint32_t gpsBeginCycle() {
    uint32_t now = millis();
    if (gpsMode == GpsMode::Backup && now - gpsEphemerisMs >= GPS_EPHEMERIS_REFRESH_MS) {
        Serial.println("  GPS ephemeris due for refresh");
        enterGpsMode(GpsMode::Acquire);
    }
    if (gpsMode == GpsMode::Rest && (sosActive || now - gpsModeStartMs >= GPS_ACQUIRE_REST_MS)) {
        enterGpsMode(GpsMode::Acquire);
    }
    if (gpsMode == GpsMode::Rest) {
        return 0;
    }
    if (!gpsPowered) {
        gpsRailUp();
    }
    if (sosFirstSendPending) {
        return GPS_ACQUIRE_QUICK_MS;
    }
    return gpsMode == GpsMode::Backup ? GPS_HOT_START_BUDGET_MS : GPS_READ_WINDOW_MS;
}
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
void loop() {
    uint32_t cycleStartMs = millis();

    if (buttonPressed()) {
        handleButtonPress();
    }
    checkBluetoothButton(); // never returns if it enters provisioning

    uint32_t budgetMs = gpsBeginCycle();
    uint32_t acquireStartMs = millis();
    bool gotFix = budgetMs > 0 && acquireGpsFix(budgetMs);
    gpsEndCycle(gotFix, millis() - acquireStartMs);

    sendLocationPacket(sosActive ? "SOS" : "OK");
    if (sosActive) {
        sosFirstSendPending = false;
    }

    radioRailDown();

    uint32_t elapsedMs = millis() - cycleStartMs;
    uint32_t sleepMs = elapsedMs < SEND_INTERVAL_MS ? SEND_INTERVAL_MS - elapsedMs : 0;
    lightSleepMs(sleepMs);

    radioRailUp();
}

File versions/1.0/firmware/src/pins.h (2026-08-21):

#pragma once

// Pin map for the LILYGO T-Beam Supreme (ESP32-S3 + SX1262 + AXP2101 + GNSS).
// Values taken from LilyGO's LoRa-Series utilities.h (T_BEAM_S3_SUPREME_SX1262
// block) in ../Lora Source — this is board-specific, not derivable from a
// generic ESP32-S3 datasheet.

// Display / general I2C bus
#define I2C_SDA         17
#define I2C_SCL         18

// PMU (AXP2101 power management IC) lives on a second I2C bus
#define PMU_SDA         42
#define PMU_SCL         41
#define PMU_IRQ_PIN     40

// GNSS module UART + enable line
#define GPS_RX_PIN      9   // ESP32 RX <- GPS TX
#define GPS_TX_PIN      8   // ESP32 TX -> GPS RX
#define GPS_EN_PIN      7   // must be driven HIGH to power the GNSS chip
#define GPS_PPS_PIN     6
#define GPS_BAUD_RATE   9600

// SOS button
#define BUTTON_PIN      0

// SX1262 LoRa radio (SPI)
#define RADIO_SCLK_PIN  12
#define RADIO_MISO_PIN  13
#define RADIO_MOSI_PIN  11
#define RADIO_CS_PIN    10
#define RADIO_RST_PIN   5
#define RADIO_DIO1_PIN  1
#define RADIO_BUSY_PIN  4

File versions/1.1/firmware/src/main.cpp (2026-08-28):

// Hiker's Companion — Milestone 1 firmware
//
// Reads GPS location and transmits it over LoRa on a fixed interval.
// No button/SOS logic or display yet — this exists to prove the GPS -> LoRa
// path works end to end on real hardware before building the full SOS flow.
//
// Target: LILYGO T-Beam Supreme (ESP32-S3, SX1262, AXP2101, GNSS)

#include <Adafruit_GFX.h>
#include <Adafruit_SH110X.h>
#include <Arduino.h>
#include <SPI.h>
#include <Wire.h>
#include <RadioLib.h>
#include <TinyGPS++.h>
#include <XPowersLib.h>

#include "hc_crypto.h"
#include "pins.h"

// ---- Radio configuration -------------------------------------------------
// 915 MHz sits in the US902-928 MHz ISM band the report identifies as our
// target. Spreading factor is not finalized in the report (SF7-SF12
// range/rate tradeoff) -- SF10 is a reasonable starting point that favors
// range over throughput; revisit once we have real range-test data.
static constexpr float LORA_FREQUENCY_MHZ = 915.0;
static constexpr float LORA_BANDWIDTH_KHZ = 125.0;
static constexpr uint8_t LORA_SPREADING_FACTOR = 10;
static constexpr uint8_t LORA_CODING_RATE = 5;
static constexpr int8_t LORA_TX_POWER_DBM = 17;

// Report's flow chart calls for polling roughly once a minute; kept as a
// constant here so it's easy to tune once battery-life testing informs it.
static constexpr uint32_t SEND_INTERVAL_MS = 60000;

// GPIO0 has no external debounce hardware on this board -- a plain
// digitalRead() chatters across several transitions on every press/release.
static constexpr uint32_t BUTTON_DEBOUNCE_MS = 50;

// ---- Globals ---------------------------------------------------------
// XPowersAXP2101's power-control methods are only public through the
// XPowersLibInterface base -- the concrete class re-declares them protected,
// so the pointer must be typed as the interface (this matches XPowersLib's
// own usage pattern, not a workaround).
TwoWire PMUWire = TwoWire(1);
XPowersLibInterface *PMU = nullptr;

HardwareSerial &SerialGPS = Serial1;
TinyGPSPlus gps;

SX1262 radio = new Module(RADIO_CS_PIN, RADIO_DIO1_PIN, RADIO_RST_PIN, RADIO_BUSY_PIN);

static constexpr uint8_t DISPLAY_WIDTH = 128;
static constexpr uint8_t DISPLAY_HEIGHT = 64;
static constexpr uint8_t DISPLAY_I2C_ADDR = 0x3C;
Adafruit_SH1106G display(DISPLAY_WIDTH, DISPLAY_HEIGHT, &Wire, -1);

uint32_t lastSendMs = 0;

// BUTTON_PIN uses INPUT_PULLUP, so idle-high/pressed-low.
bool lastButtonReading = HIGH;
bool buttonState = HIGH;
uint32_t lastButtonChangeMs = 0;

// A press starts a standing SOS beacon (every periodic send goes out flagged
// "SOS" instead of "OK") rather than sending just one SOS packet and falling
// back to routine sends. A second press cancels it.
bool sosActive = false;

static void printHex(const char *label, const uint8_t *data, size_t len) {
    Serial.print(label);
    for (size_t i = 0; i < len; i++) {
        Serial.printf("%02x", data[i]);
    }
    Serial.println();
}

static void haltWithError(const char *message) {
    Serial.println(message);
    while (true) {
        delay(1000);
    }
}

// The T-Beam Supreme gates LoRa and GPS power behind the AXP2101 PMU's ALDO3
// and ALDO4 rails -- they are off by default at boot. Without this, the
// radio and GPS modules never power up even though the wiring is correct.
static void initPower() {
    PMUWire.begin(PMU_SDA, PMU_SCL);

    PMU = new XPowersAXP2101(PMUWire);
    if (!PMU->init()) {
        haltWithError("PMU init failed - check I2C wiring to AXP2101");
    }

    PMU->setPowerChannelVoltage(XPOWERS_ALDO3, 3300); // LoRa rail
    PMU->enablePowerOutput(XPOWERS_ALDO3);

    PMU->setPowerChannelVoltage(XPOWERS_ALDO4, 3300); // GPS rail
    PMU->enablePowerOutput(XPOWERS_ALDO4);
}

static void initGPS() {
    pinMode(GPS_EN_PIN, OUTPUT);
    digitalWrite(GPS_EN_PIN, HIGH);
    SerialGPS.begin(GPS_BAUD_RATE, SERIAL_8N1, GPS_RX_PIN, GPS_TX_PIN);
}

static void initDisplay() {
    Wire.begin(I2C_SDA, I2C_SCL);
    if (!display.begin(DISPLAY_I2C_ADDR, true)) {
        haltWithError("Display init failed - check I2C wiring to SH1106");
    }
    display.clearDisplay();
    display.display();
}

// Panel stays off between transmissions to save power -- it wakes for a
// send, holds through the result, then sleeps again on a timer checked in
// loop() (no delay() here, since that would stall GPS/button/radio polling).
static constexpr uint32_t DISPLAY_HOLD_MS = 5000;
bool displayOn = false;
bool displayOffScheduled = false;
uint32_t displayOffAtMs = 0;

static void displayWake() {
    if (!displayOn) {
        display.oled_command(SH110X_DISPLAYON);
        displayOn = true;
    }
    displayOffScheduled = false;
}

static void displaySleep() {
    if (displayOn) {
        display.oled_command(SH110X_DISPLAYOFF);
        displayOn = false;
    }
    displayOffScheduled = false;
}

static void scheduleDisplayOff(uint32_t holdMs) {
    displayOffAtMs = millis() + holdMs;
    displayOffScheduled = true;
}

// line2 is the big/important word ("Sending", "Delivered", "Send failed");
// line1 is the small context above it (message type, or a boot message).
// No ACK yet (see FW-06 in the backlog), so "Delivered" here means "the
// radio call returned success," not "a human received this."
static void showStatus(const char *line1, const char *line2) {
    display.clearDisplay();
    display.setTextColor(SH110X_WHITE);

    display.setTextSize(1);
    display.setCursor(0, 0);
    display.print(line1);

    display.setTextSize(2);
    display.setCursor(0, 20);
    display.print(line2);

    display.display();
}

static void initRadio() {
    SPI.begin(RADIO_SCLK_PIN, RADIO_MISO_PIN, RADIO_MOSI_PIN, RADIO_CS_PIN);

    int state = radio.begin();
    if (state != RADIOLIB_ERR_NONE) {
        Serial.printf("Radio init failed, code %d\n", state);
        haltWithError("Halting.");
    }

    radio.setFrequency(LORA_FREQUENCY_MHZ);
    radio.setBandwidth(LORA_BANDWIDTH_KHZ);
    radio.setSpreadingFactor(LORA_SPREADING_FACTOR);
    radio.setCodingRate(LORA_CODING_RATE);
    radio.setOutputPower(LORA_TX_POWER_DBM);
}

// Builds "lat,lng,hdop,age_ms" or "NOFIX,age_ms" if we don't have a valid fix yet.
static String buildLocationMessage() {
    if (!gps.location.isValid()) {
        return "NOFIX," + String(gps.location.age());
    }

    String message;
    message += String(gps.location.lat(), 6);
    message += ",";
    message += String(gps.location.lng(), 6);
    message += ",";
    message += String(gps.hdop.hdop(), 1);
    message += ",";
    message += String(gps.location.age());
    return message;
}
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

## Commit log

2026-08-21 Add custom firmware skeleton: GPS + LoRa send loop for T-Beam Supreme
    Milestone 1 firmware, separate from vendored Lora Source/. Reads GPS
    fixes and transmits location over LoRa on a timer using RadioLib,
    TinyGPSPlus, and XPowersLib for the AXP2101 power rails the LoRa/GPS
    modules are gated behind. Build-verified with PlatformIO.
    [main.cpp, pins.h]
2026-08-28 Add SOS button, AES-128-GCM encryption, status displays, and delivery ACK
    Builds on the GPS + LoRa send loop skeleton with the next round of
    Milestone 1 features:
    - AES-128-GCM encryption on all LoRa payloads (shared/hc_crypto.h,
    shared/psk.h), so location data is no longer sent in the clear.
    - SOS button (T-Beam BOOT/GPIO0): toggles a standing beacon that flags
    every send "SOS" instead of "OK" until pressed again.
    - Status OLED on both boards (SH1106 on the T-Beam, SSD1306 on the
    Heltec), each sleeping between events to save power.
    - Real delivery ACK: the Heltec replies "ACK,<id>" on every valid
    packet, and the T-Beam now distinguishes Delivered / No ACK / Send
    failed instead of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
    [main.cpp, pins.h]
2026-09-07 Light-sleep the ESP32 and gate GPS/LoRa rails between polls
    Replaces the always-on busy loop with a bounded acquire-and-send cycle:
    GPS/LoRa PMU rails power up, GPS gets a capped window to get a fix (short
    for an SOS press so it isn't held up by fix quality), the packet sends,
    then both rails gate off and the ESP32 light-sleeps for the rest of the
    interval. The SOS button is armed as a GPIO wakeup source so a press
    during sleep isn't stuck waiting out the timer. This is the duty cycle
    the report's 46.93 mA average current draw is based on.
    [main.cpp]
2026-09-07 Re-init display I2C each cycle to survive light sleep
    The GPS/LoRa rails get a full re-init after waking because their PMU
    rails are actually cut, but the display's rail is never gated -- so
    sendLocationPacket() was only sending a DISPLAYON command, assuming the
    I2C peripheral itself was untouched. It isn't: the ESP32's I2C state
    doesn't reliably survive esp_light_sleep_start() either, so every status
    draw after the first sleep was silently failing and the screen stayed
    dark, even though GPS/LoRa/SOS kept working fine.
    reinitDisplay() re-runs Wire.begin() + display.begin() before each
    cycle's draw, non-fatal on failure unlike the boot-time initDisplay()
    halt, since a flaky screen shouldn't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
    [main.cpp]
2026-09-07 Add BLE emergency-contact provisioning (FW-10) and attach contacts to SOS
    Provisioning runs as a standalone Nordic UART Service session, entered
    either by holding BOOT through power-on or by short-pressing the board's
    PWR button (wired into the AXP2101 as its power key) during normal
    operation -- the latter is flatly ignored whenever the SOS beacon is
    active, since entering can block the loop for minutes. Up to 3 contacts
    are stored in NVS and editable from any terminal-style BLE app.
    The stored contacts now also ride along on the first SOS transmission
    after activation (not every repeat), so responders learn who to notify
    without resending that data on every ~60s heartbeat; the location it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
    [ble_provisioning.cpp, main.cpp]
2026-09-07 Add T-Beam Supreme CAD reference files for MECH-01/02/04
    Extracted from the vendored Lora Source/dimensions/ archives (LilyGO's own
    repo) into a top-level cad-reference/ folder so they're easy to find:
    board STEP model, mounting bracket STEP, dimension DXF, and LilyGO's own
    existing enclosure shell STLs -- a real starting point for enclosure CAD
    work rather than a from-scratch design.
    Claude-Session: https://claude.ai/code/session_018WTZ2VfU4pZpzSDXb1Y9i8
    [T-Beam-Supreme-Board.stp, T-Beam-Supreme-Bracket.stp, T-Beam-Supreme-Dimensions.dxf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]
2026-09-08 Fix display init: probe both I2C addresses, never halt the whole device
    LilyGO ships this board with two magnetometer sub-variants (QMC6310U vs
    QMC6310N) that put the SH1106 OLED at different I2C addresses -- 0x3C or
    0x3D. Confirmed on our own bench: our two units needed different
    addresses, and the one at 0x3D was silently bricking on boot because
    initDisplay() only ever tried 0x3C and haltWithError()'d on failure,
    taking GPS/LoRa/SOS down with it over what looked like just a dead
    screen.
    initDisplay() and runProvisioningMode() now probe both addresses, and
    display failure is non-fatal everywhere including at boot -- every
    display* function checks a new displayAvailable flag and no-ops rat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
    [ble_provisioning.cpp, main.cpp]
2026-09-08 Enable ALDO1: the actual cause of a "dead" display on one unit
    initPower() only ever enabled ALDO3 (LoRa) and ALDO4 (GPS), never ALDO1 --
    the AXP2101 rail that LilyGO's own hardware doc says is shared across the
    display, the BME280 sensor, and the magnetometer. One of our two units had
    a screen that stayed black through boot even though display.begin()
    reported success and the rest of the device ran fine. Flashing Meshtastic
    on the same unit proved the OLED hardware itself was fine, which pointed
    at power rather than the display or its I2C address (the address-fallback
    and non-fatal-boot fixes from the previous commit were real improvements
    but not the actual cause here). The SH1106 controll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
    [main.cpp]
2026-09-18 Add PWR long-press power-off alongside short-press BLE provisioning
    Both PMU key IRQs are enabled and decoded from a single status read in
    bluetoothButtonPressed(): short press still enters provisioning, long press
    shows "Power Off" and parks until the PMU cuts all rails at 4s. Long press
    applies even while SOS is active since the hardware cut can't be aborted.
    [main.cpp]
2026-09-20 Add no-sleep bench-debug build so USB serial stays alive
    Light sleep suspends native USB CDC, so a serial monitor goes dead between
    cycles. The new t-beam-supreme-debug env defines DEBUG_NO_SLEEP, which makes
    lightSleepMs() poll the button/PMU pins with delay() instead of sleeping.
    Default env stays t-beam-supreme (real low-power build).
2026-09-20 Add timestamp filter to serial monitor
2026-09-20 Attach emergency contacts to every SOS send, not just the first
    The one-shot sosContactsPending flag meant a standing SOS beacon carried
    the contact list on exactly one packet. LoRa packets get lost, so losing
    that single packet lost the contacts for the whole emergency -- a
    responder who only catches a later beacon repeat had no one to notify.
    Gate on sosActive alone so every packet of the beacon carries them. Costs
    airtime on data that doesn't change mid-emergency, but that redundancy is
    the point for a safety device.
    The receiver's 192-byte kMaxCipherLen already covered this; only its
    comment needed updating.
    [main.cpp]
2026-09-20 Reduce emergency contact slots from 3 to 2
    Derive every user-facing mention of the valid slot range from
    MAX_CONTACTS via slotRange() instead of spelling out "0-2" by hand. The
    BLE greeting, both ERR replies, and the serial command hint each had the
    range hardcoded and would have silently advertised a slot the firmware
    now rejects.
    Note for already-provisioned units: name2/phone2 stay in NVS but are
    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
2026-09-20 Set LoRa spreading factor to 7 on T-Beam and Heltec receiver
    Starting point for the SF7-SF12 range test. Both ends must use the same
    value or the receiver won't decode the packets and no ACKs come back.
    [main.cpp]
2026-09-20 Scale ACK window with spreading factor; raise TX power to 22 dBm
    - waitForAck() now sizes its listen window from the ACK's airtime at the
    current SF (radio.getTimeOnAir) plus a turnaround margin, replacing the
    fixed 2s that was shorter than the ACK itself at SF11/SF12.
    - T-Beam TX power 17 -> 22 dBm (SX1262 max).
    - Heltec receiver never set an output power, so ACKs went out at RadioLib's
    10 dBm default and dropped out first at range; now set to 22 dBm.
    - Both ends set to SF12 for the current range test.
    [main.cpp]
2026-09-21 Condense source comments and set SF7 on both boards
    Trims long explanatory comments to short notes, keeping the non-obvious
    reasons (ALDO1 display rail, I2C re-init after light sleep, NimBLE setValue
    pitfall, DIO1 flag clearing after ACK). No functional changes. Both ends are
    set to SF7 for the range test.
    [ble_provisioning.cpp, main.cpp]
2026-09-25 Show battery percentage and charging status on the OLED
    Adds a bottom line to every status screen: "Bat 87% CHG" while charging,
    "USB" when plugged in but not charging, plain percent on battery, or
    "No battery". Enables the AXP2101's battery detection and voltage
    measurement, which the percentage needs, and prints the same line to
    serial on each send.
2026-09-25 Add per-spreading-factor build envs (SF7-SF10); default to SF10
    Spreading factor is now the LORA_SF build flag (default 10) instead of a
    hardcoded constant. T-Beam gets t-beam-supreme-debug-sf7..sf10 and the Heltec
    gets heltec-sf7..sf10, so switching SF is a single pio command on each board
    with no code edits. Both boards print their SF in the boot banner.
2026-09-27 Schedule the L76K GPS rail independently of the send cycle
    Previously the GPS rail was cut after every send, throwing away any
    in-progress search, and SOS only gave the GPS 2s after a power-up.
    The GPS now runs its own schedule: it stays on (even through light
    sleep) until a fix, settles 60s so the full ephemeris downloads, then
    drops to backup between sends. The Supreme feeds the GNSS backup supply
    straight from the 18650, so each send should be a hot start. A missed
    hot start re-acquires, ephemeris is refreshed every 2h, and searching
    rests after 10 min without a fix (never during SOS).
    SOS uses the same schedule; only its first send after a press gets the
    short 2s window. Logs time-to-f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
    [main.cpp]
2026-09-29 Fix debug-build SOS presses being intermittently dropped
    lightSleepMs()'s DEBUG_NO_SLEEP branch polled BUTTON_PIN with a raw
    digitalRead() to end its wait early, bypassing buttonPressed()'s debounce
    state machine entirely. A press that started and ended inside that wait
    (covering most of each cycle -- the display hold and the between-send wait)
    never updated that state, so whether the next real buttonPressed() call
    caught it depended on exact timing -- intermittently dropping a press.
    Now it polls through buttonPressed()/handleButtonPress() like every other
    call site, so debounce state stays consistent throughout. buttonPressed()
    and handleButtonPress() are moved above lightSleepMs() so they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
    [main.cpp]
2026-09-29 Actually power off on a PWR long press
    The long-press handler showed "Power Off" and then waited for the AXP2101
    to cut power after a 4s hold. But the long-press IRQ fires at ~2s, so users
    let go early, and the chip's hold-to-power-off was never enabled, so the
    board stayed fully on and draining the battery. The firmware now shows the
    message for 1.5s, turns the display off, and calls PMU->shutdown() itself.
    The hardware 4s hold-to-off is also enabled as a backstop if firmware hangs.
    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
2026-10-08 Add node ID to packets and ACKs; add contention test builds
    Packets are now "<type>,<node>,<id>,<location>" and ACKs "ACK,<node>,<id>".
    waitForAck() matches both, fixing a real multi-node bug where a sender could
    accept another node's ACK whenever their message ids coincided. NODE_ID,
    SEND_INTERVAL, and LORA_TX_POWER are now build flags (defaults 1, 60000 ms,
    22 dBm). The Heltec parses the node field, echoes it in the ACK, and
    prefixes every receive-path log line with millis().
    New envs for the concurrent-transmission test: contention-tx1/tx2 on the
    T-Beams (no-sleep debug, SF10, 10 dBm, 5 s interval, node 1/2) and
    heltec-contention on the receiver (SF10, 10 dBm ACKs).
    All boards need refl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
2026-10-09 Bump firmware version to v0.6.0
    v0.6.0 changes the packet and ACK format to carry a node ID, so boards on
    v0.5.0 can't exchange ACKs with boards on v0.6.0.
2026-10-09 Ignore serial monitor logs folders
    PlatformIO's log2file monitor filter writes to logs/ in whichever project
    folder the monitor runs from.
2026-10-17 Retry display init at boot for up to ~8s
    The OLED's bare COG driver chip can fail to init in direct sunlight. Boot
    now retries up to 5 times, 2 s apart, before continuing without the display.
2026-10-17 Switch radio to SF12 at 500 kHz for FCC 15.247 compliance
    At 125 kHz on a fixed channel the radio didn't meet 15.247: narrow signals
    must hop across 50+ channels with at most 400 ms per channel, and SF10
    packets ran 535-1700 ms. At 500 kHz it is a digital modulation system under
    15.247(a)(2), which allows a single channel with no dwell limit, subject to
    the power density cap (~0 dBm/3 kHz here vs. the 8 dBm limit).
    SF12/500 has the same symbol time as SF10/125, so airtime and range (~1 dB
    less) stay about the same. The measured 6 dB bandwidth still needs to be
    confirmed at >= 500 kHz.
    Bandwidth is now a build flag (-DLORA_BW) on both boards, and new
    t-beam-supreme-debug-sf10-bw125 / heltec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
2026-10-17 Bump firmware version to v0.7.0
    v0.7.0 moves the radio to SF12 at 500 kHz, so boards on v0.6.x (SF10 at
    125 kHz) can't talk to boards on v0.7.0. Flash the Heltec receiver too.
